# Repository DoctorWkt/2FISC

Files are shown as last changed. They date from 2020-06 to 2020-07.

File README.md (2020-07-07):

# FISC2: A TTL CPU with Some 16-bit Capabilities

FISC2 is a microseqenced CPU built from discrete TTL-level components.
It provides
 + recursive **F**unctions,
 + **I**ndexed addressing,
 + **S**tack operations, and
 + some instructions on 16-bit data values

as well as the usual load/store and arithmetic operations, comparisons,
branches and jumps.

The design uses 29 chips and has 8K of ROM, 336K of available RAM and a UART.



## Documentation

The overall design of the CPU is covered in
[Docs/arch_overview.md](Docs/arch_overview.md), and some details
of the hardware implementation are in 
[Docs/fisc2_implementation.md](Docs/fisc2_implementation.md).

## Implementation

At present, I have:

 + a Perl CPU simulator, [csim](csim)
 + an assembler, [cas](cas)
 + a simple compiler, [clc](clc)
 + example assembly and higher-level programs in [Examples](Examples)
 + a Verilog design in [Verilog](Verilog)
 + a final schematic in [Kicad/schematic.pdf](Kicad/schematic.pdf)

## Status of the CPU

**early-July, 2020**: Both the Perl simulator and the Verilog model work
well. I am happy with the design and I've ordered the PCBs and components.

For more detail on progress, you can read my [journal](Docs/journal.md).

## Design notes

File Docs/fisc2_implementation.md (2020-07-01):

# Implementation of the FISC CPU

This document outlines some of the implementation decisions for the FISC2
CPU. As with the CSCvon8 CPU, one of my goals was to keep the chip count
down. This time, recursive functions, local variables and indexed addressing
are important goals, as these allow me to port a C compiler to the CPU.

## Clock Phases

Before we tour the FISC2 implementation, I think it's important that I cover
how I'm using the two phases of the master clock signal in the implementation.
There is a square-wave master clock, called `Clk`, running at 3.57Mhz: in
the first half of each clock cycle the clock's value is high, and in the second
half the clock's value is low. And, of course, there is a falling edge between
the first and second halves.

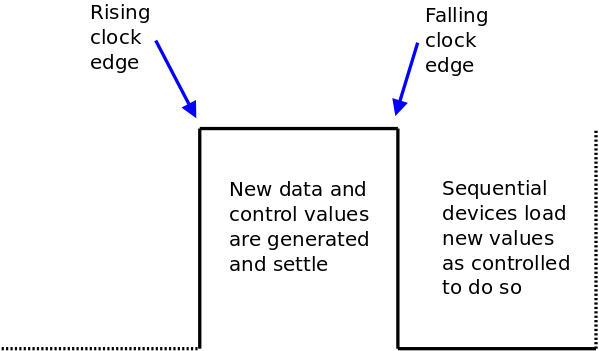
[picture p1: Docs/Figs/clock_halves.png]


In the first half of the clock cycle when the clock pulse is high, we propagate
new values from a (typically sequential) source of data through one or more
combinational devices, e.g the RAM or the ALU. The final result *must* settle before
the end of the first half. This also includes any level-based control values that
will be used in the second half.

The falling edge of the clock pulse is used to load the new data values from the
first half of the clock cycle into the sequential devices that need to load new
values. These devices need to be told to load their values, and so their control
lines (as noted) need to be set before the clock pulse falls. These devices know
to load when they see the clock edge. However, some of them need to see a
rising edge, so we also generate an inverted clock signal `Clkbar` for this reason.

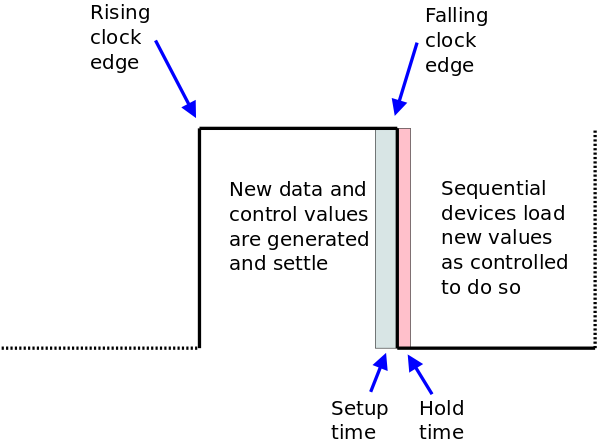
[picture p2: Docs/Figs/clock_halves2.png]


In fact, the values generated in the first half of the clock cycle need to settle
well before the clock transition. This is as most of the sequential devices which use
these values have both a *setup time* and a *hold time*. Each sequential device
has its own values for these two times.

The overall timing of the CPU (and hence its maximum clock speed) is limited
by the delay from when the clock edge rises and when the resulting control and data
values can settle before the start of the setup time. If we don't meet this
timing constraint, we will either load incorrect data or perform actions based
on incorrect control line values.

We can now start the tour of the FISC2 implementation, but bear in mind
which device control lines are level-based (generated in the first clock phase)
and which device control lines are edge-based (and triggered by the falling
clock transition).

*Aside: throughout the rest of the document, control lines which are active
low are indicated by a leading `~` tilde character.*

## The Program Counter

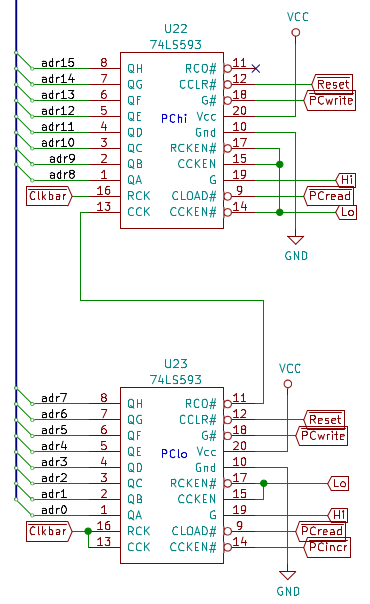
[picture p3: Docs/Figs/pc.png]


I chose to re-use the [74LS593](https://www.ti.com/lit/gpn/sn74ls593) as the
device for the PC. I'd previously used this in my CSCvon8 design; there it was
[my nemesis](https://minnie.tuhs.org/Blog/2019_04_26_Understanding_74LS593.html).
I think I understand it now.

The 74LS593 is an 8-bit register and incrementing counter with tri-state output.
The tri-state output is controlled by the level-based `~G` input, so we generate
this in the first clock half.

Loading and incrementing the register occur when `RCK` and `CCK` see a
rising edge. So, for the *PClo* component, they are both tied to `Clkbar`.

The register loads mid-cycle if `~CLOAD` is set low: both devices have this tied to
`~PCread`. The *PClo* component increments mid-cycle if `~CCKEN` is set low: this
is tied to `~PCincr`.

When *PClo* overflows from $FF to $00, the `~RCO` line generates a clock
transition. This is connected to *PChi*'s `CCK` so as to make *PChi* increment
as well.

I've tied both devices' `~CCLR` lines to the `~Reset` line to ensure that the PC
initialises to value $0000.

Note that the 74LS593's inputs are also its outputs. This is fine as the PC
only has to write to, and read from, the address bus. But because of this
I had to choose another device for the other address registers.

## The Stack Pointer



For the stack pointer, I had to find a TTL device which is:

 + an 8-bit register,
 + with tri-state output,
 + is also an up/down counter,
 + and can be cascaded to act as a 16-bit device.

Fortunately I found the
[74LS469](http://pdf.datasheetcatalog.com/datasheet/nationalsemiconductor/DS008333.PDF).
Unfortunately, this is now obsolete. I can
get them second-hand, but there are no new device and, sadly, no SOIC packages.
That's a shame as the 74LS469 is quite a nice device.

The 74LS469 has two level-based inputs, `~UD` and `~CBI`. When the `CLK` input
sees a rising edge, here is what happens:

  ~CBI |  ~UD  |  Result
------:|:-----:|--------
    0  |   0   | Decrement
    0  |   1   | Increment
    1  |   0   | Do nothing
    1  |   1   | Do nothing

As two of these four values have the same result, I was able to use one of these
patterns for a second purpose: to generate the `~PCincr` line. I'll explain soon.

`~UD` and `~CBI` are level-based, so I have to generate them in the first half of
the clock cycle. The 74LS469 expects a rising clock edge, so `Clkbar` is used
for this.

*SPlo* gets two control lines `~StkOp0` and `~StkOp1` which are tied to
`~UD` and `~CBI`, respectively. We only need to connect the `~StkOp0` (i.e
increment/decrement) line to *SPhi* because *SPlo* generates a carry/borrow
on the `~CBO` output. We can wire this to *SPhi*'s `~CBI` input to cascade
any increment or decrement.

As with the PC, the tri-state output is controlled by a level-based pin, `~OE`
which is tied to `~SPwrite` and generated in the first half of the clock cycle.

Now, I need to be able to set the Stack Pointer to any value, but typically
$0000 when the CPU initialises. Both *SPlo* and *SPhi*'s have `~LD` lines which
are tied to the control lines `~SPloread` and `~SPhiread`, respectively. When
low, they cause *SPlo* or *SPhi* to read from the data bus.

## The AR and DR Address Registers

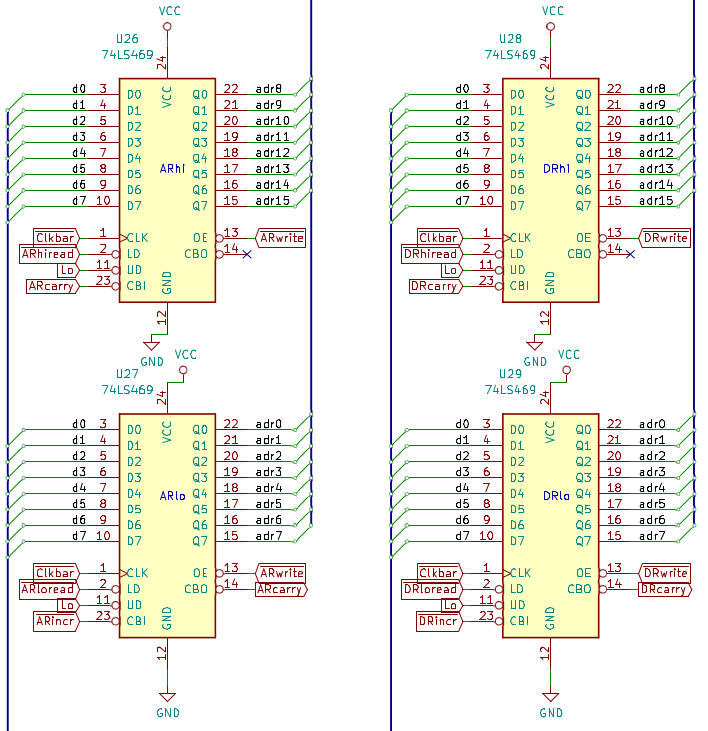
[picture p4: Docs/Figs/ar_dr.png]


I re-used the 74LS469 for the AR and DR registers as they need inputs separate
from their outputs, and they also need to increment.

As they only need to increment, not decrement, I can wire their `~UD` lines low.
They increment when the level-based `~ARincr` and `~DRincr` lines, respectively,
are low in the first half of the clock cycle. Otherwise, they are wired up
the same as the stack pointer devices.

## Memory Devices

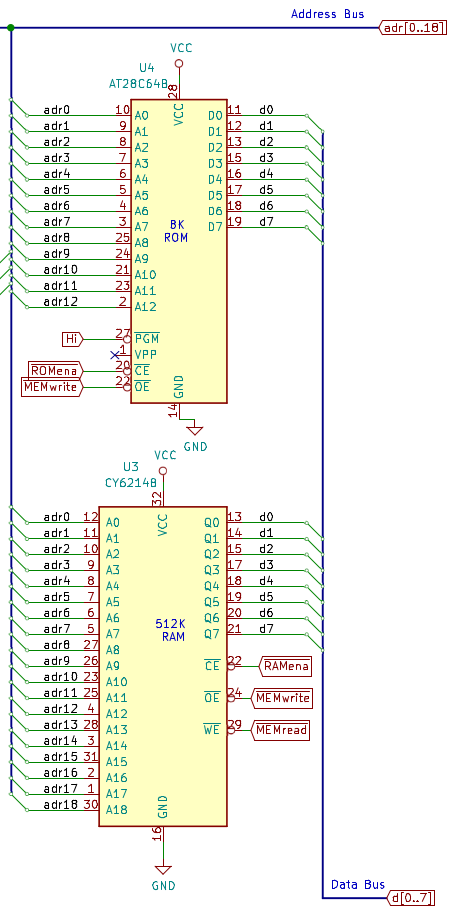
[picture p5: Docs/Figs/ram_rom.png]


The address registers in FISC2 are 16 bits wide, so technically there is only
a 64Kbyte address space. This is divided up into 8K of ROM starting at address
$0000, followed by 56K of RAM.

Both the
[AT28C64B EEPROM](http://ww1.microchip.com/downloads/en/DeviceDoc/doc0270.pdf)
and the [CY62148 static RAM](https://www.digchip.com/datasheets/parts/datasheet/115/CY62148-pdf.php)
read the address from the
address bus, select a memory location and write out to the 8-bit data bus.

Output on each device is enabled when both:

 + the `~CE` (chip enable) line is low, and
 + the `~OE` (output enable) line is low.

I've chosen to wire both `~OE` lines to `~MEMwrite` and treat both components
as a single "memory" device. There is a control line to the RAM, `~MEMread` wired
to `~WE`, which tells the RAM to read from the data bus and overwrite a memory
location.

## Selecting RAM and ROM, and Bank Switching

What I omitted to describe is how I control the `~CE` (chip enable) line on
both devices. I generate a single `~RAMena` line which is connected to the RAM's
`~CE` line. This is inverted and connected to the ROM's `~CE` line. Either
the RAM is enabled or the ROM, but never both. Now let's look at how
this `~RAMena` line is generated.

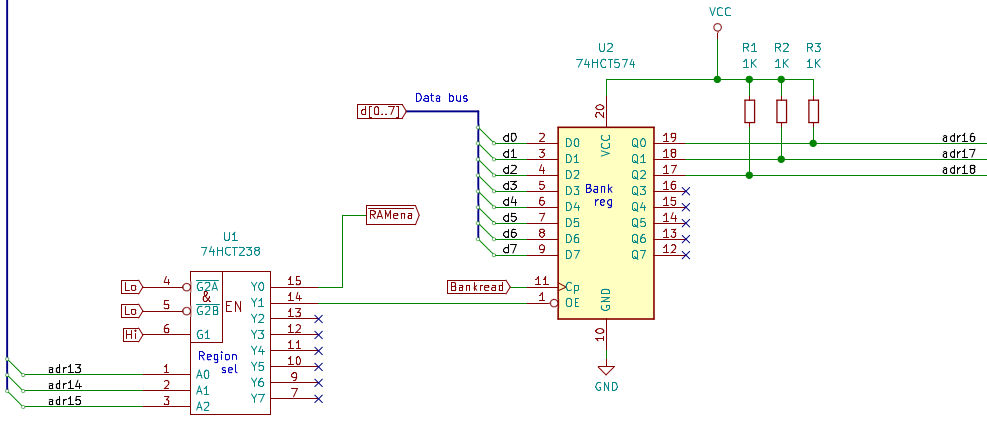
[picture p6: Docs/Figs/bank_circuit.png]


We want the bottom 8K of the address space to select the ROM and the rest of the
address space to select the RAM. To do this, I'm using the
[74HCT238](https://assets.nexperia.com/documents/data-sheet/74HC_HCT238.pdf)
3:8 demux on the left.

The 74HCT238 generates high outputs based on its input. The `A0` to `A2` inputs
are wired to the top three address bus lines, dividing the address space up into
eight 8K regions.

For the bottom 8K, `A0` to `A2` will be all low. This causes the `Y0` output
from the 74HCT238 to go high. As this is wired to the active-low `~RAMena` line,
this disables the RAM and enables the ROM. For all other memory regions, the RAM
is enabled.

Now we get to the bank switch. I wanted to have more than just 56K of available
RAM, and I had to work out how to map it into the 64K address space. Moreover,
I wanted to have a shared region of RAM which was always visible, so that I could
copy in and out of the currently non-visible parts of memory.

I've achieved this with a "bank switch" that generates extra address lines for the
CY62148 which is actually a 512K RAM device. Here is how it works.

I am using a
[74HCT574 8-bit register](https://assets.nexperia.com/documents/data-sheet/74HC_HCT574.pdf)
as a bank switch register; I'm only using
three of the bits that it can store. This register can load from the data bus
when the `Cp` clock input rises. I've wired this to `Bankread` which rises
mid-cycle once the data bus value has settled.

This allows eight "banks" of RAM to be mapped in to the address space, but only one
bank at a time is visible. As it stands, this means that the contents in each bank
can never be visible when a different bank is mapped in. I wanted to have a way
to copy data from one memory bank to another. And here is how this works.

Notice that the `Y1` output from the demux is wired to the `~OE` input on the
bank register. When the address bus has an address in the range $2000 to $3FFF,
this value is high. And as the `~OE` input is active low, this will cause the
output of the 74HCT574 to become high impedance ("high Z").

I've added three 1K pullup resistors to the three address outputs of the
bank register. When these are high impedance, the pullup resistors set their
values high.

The end result is that, when the address bus is in the range $2000 to $3FFF,
the highest of the eight RAM banks will always be selected, regardless of the
value in the bank register. Thus, there is a shared 8K of RAM in the
range $2000 to $3FFF no matter what RAM bank is selected.

# The Address Buffers

I needed the ability to manipulate and to store the values in the four
address registers (PC, SP, AR and DR) in RAM. To do this, I need to be able
to write their values on the data bus. However, the data bus is only 8 bits
wide and the address bus is 16 bits wide.

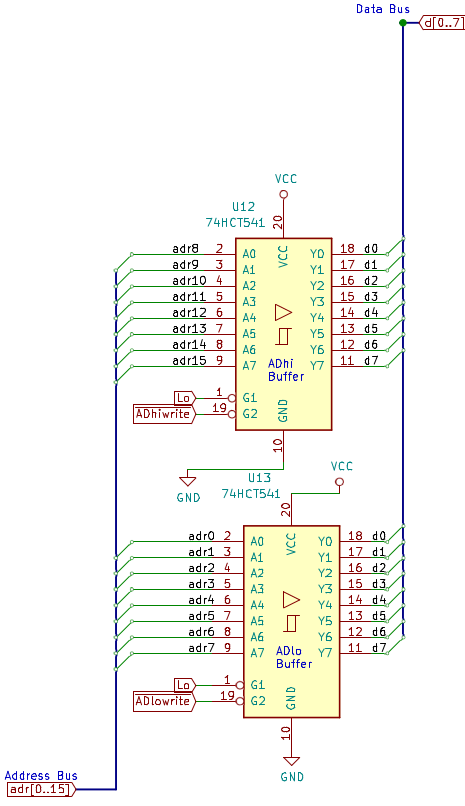
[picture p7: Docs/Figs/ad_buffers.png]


To do this, I'm using two
[74HCT151 tri-state buffers](https://assets.nexperia.com/documents/data-sheet/74HC_HCT151_Q100.pdf).
One is connected to the
low eight bits of the address bus; the other to the high eight bits. Both
output to the data bus.

The 74HCT151's output is controlled by two active-low lines, `~G1` and `~G2`.
I've set one line low on each buffer. The other is wired to `~ADlowrite` and
`~ADhiwrite`, respectively. I can set one of these in the first half of the
clock cycle. At the same time, I can get one of PC, SP, AR or DR to write a
value on the address bus. Now, half of the address bus value appears on the
data bus.

## The A and B Data Registers

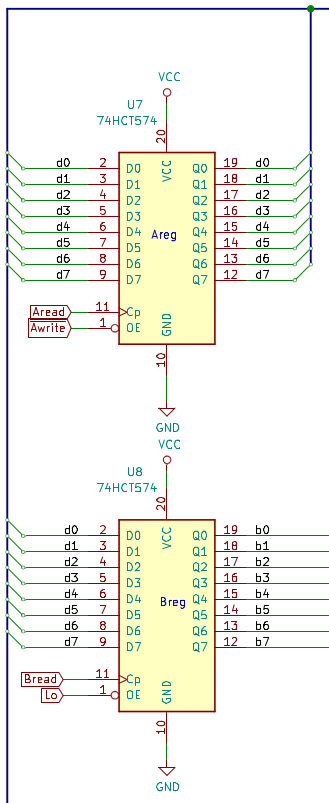
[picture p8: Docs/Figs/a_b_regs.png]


An ALU needs to operands to work on, but we can't transfer two things across
the data bus at the same time. Therefore, we need to store data in at least one
data register. I've put two data registers into FISC, the A and B register.

The A register simply reads from the data bus and writes back to the data bus.
This allows us to get data from memory and keep hold of it for several instructions
without having to fetch it again and again. I used a 74HCT574 8-bit register
for both A and B. Note that each have a rising edge control line, `Aread` and `Bread`
to read from the data bus mid-cycle.

The A register has an active low level-based control line, `~Awrite`, which
enables it to write to the data bus. We have a lot of data bus writers, and
we have to ensure that only one can write on the data bus at any time.

The B register's value goes directly into the ALU, so its output is always
enabled.

## The ALU

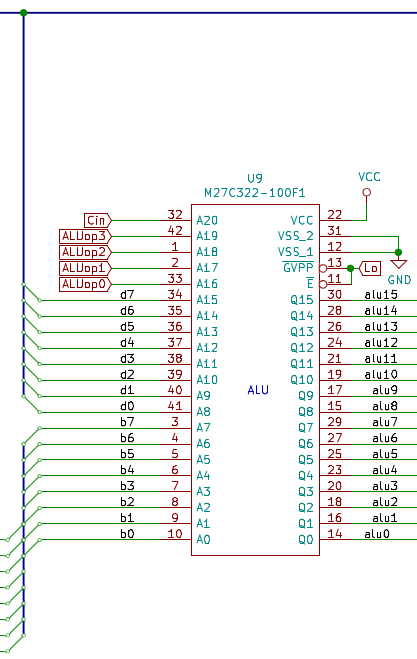
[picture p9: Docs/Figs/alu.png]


The ALU is simply a very big ROM, an
[M27C322 2MB x 16 ROM](https://www.digchip.com/datasheets/parts/datasheet/456/M27C322-pdf.php),
where the results of all operations are pre-computed and stored. I will cover what operations the
ALU performs elsewhere (and put in a link to this at some point).

As inputs, the ALU takes:

 + the 8-bit B value on address lines 0 to 7,
 + the 8-bit data bus value on address lines 8 to 15,
 + four bits indicating the ALU operation on address lines 16 to 19, and
 + a carry-in bit on address line 20.

As outputs, the ALU generates an 8-bit result on data lines 0 to 7, and
another eight bits. For some ALU operations, these encode a comparison result
(e.g. if one operand was bigger than another operand). For other ALU operations,
these bits encode part of the result. As an example of the latter, an 8-bit by
8-bit multiply produces a 16-bit result.

In terms of control, we don't need any control lines for the ALU. The ALU's
output is wired on with `~E` set low. `~GVPP` is wired low to stop the ROM
from being accidentally reprogrammed.

The datasheet for the MC27C322 lists its time from address change to data output
at up to 80nS, so this is one of the longer timing delays in the CPU. Another
is the AT27C1024-70 Decode ROM at 70nS. Together, they mean that the first half
of the clock cycle has to be at minimum 150nS. Then, if we have to fetch data from
the AT28C64B Instruction ROM, we can add another 150nS to that as well!

## The 16-bit Output Register

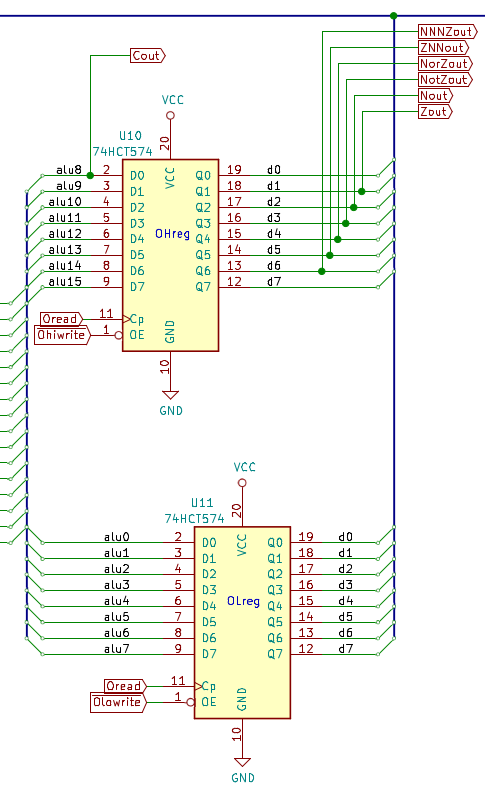
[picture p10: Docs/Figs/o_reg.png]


I use another two 74HCT574 8-bit registers to hold the output of the ALU.
A single rising edge load line, `Oread`, causes them to read the ALU output
mid-cycle when it is settled. Two level-based control lines, `~Ohiwrite`
and `~Olowrite`, tell the registers to write to the data bus. The implication
here is that it takes two clock cycles for the ALU to calculate a result
and for it to cross the data bus to be stored somewhere.

## The Carry

Notice on the previous image that there is a `Cout` signal tied to bit 8
of the ALU output. When we are doing addition or subtraction, this holds
the resulting carry or borrow. Yes, this is already stored in the high half of
the output register discussed above. The problem is that I need this
carry result to be fed back in to the ALU for subsequent additions or
subtractions. However, the output register's output is already connected
to the data bus.

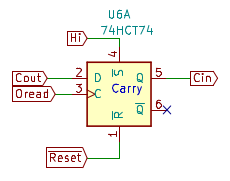
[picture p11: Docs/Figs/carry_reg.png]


Thus, we need a 1-bit register to hold the carry output. I've chosen to
use half of a
[74HCT74 D flip-flop](https://assets.nexperia.com/documents/data-sheet/74HC_HCT74.pdf).
I'm using the same rising edge load
line, `Oread`, that I was using for the output register to save a control
line. I've also wired the flip-flop's reset line to the system `~Reset`
line, even though this is not really neccessary.

## The Reset Line

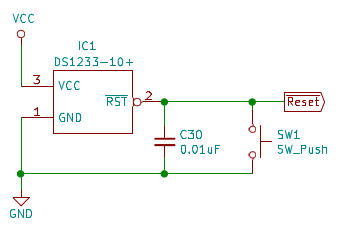
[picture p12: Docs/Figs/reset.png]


Given that I've just mentioned the `~Reset` line, let's see how we
generate it. I am using the
[DS1233 reset device](https://datasheets.maximintegrated.com/en/ds/DS1233.pdf)
for this. It holds the `~Reset` line low until the power supply stabilises,
then waits about 300mS, then raises the `~Reset` line.

The DS1233 device also provides for a manual reset button as
shown in the schematic. When pressed, this drops `~Reset` low,
and it comes up (glitch free) after about 300mS.

## The UART

Our final data device is the
[UM245R UART](https://www.ftdichip.com/Support/Documents/DataSheets/Modules/DS_UM245R.pdf).
This is an expensive device but I like it because it does several things:

 + provides a USB-visible UART for both Linux and Windows at a
   very high bit rate;
 + provides an 8-bit input and output register which is much easier to
   read/write than doing bit-banging;
 + the output is tri-state; and
 + it can also be used as the power supply for the whole CPU.

I am using all four features of the UM245R here. It is connected
to the data bus for both input and output. There are two falling-edge
control lines:

 + `~WR` (connected to `~UARTread`) reads one byte of data from the
   data bus and writes it to the UART; and
 + `~RD` (connected to `~UARTwrite`) reads one byte of data from the
  UART and writes it to the data bus.

When the UART is not writing to the data bus, its output is high Z.

Finally, there are two status lines from the UART:

 + `~RXF` (connected to `~RXready`) is low when the UART has a byte
   ready to place on the data bus; and
 + `~TXF` (connected to `~TXready`) is low when the UART is read to
   read from the data bus and send data down the UART.

## The Control Logic

We have now covered all of the address and data components in the FISC2
implementation. Along the way, I've covered most of the control lines
for these devices. Now we need to turn our attention to how these lines
are generated.

Also, remember that the level-based control lines need to be generated
in the first half of the clock cycle. The edge-based control lines will
either be generated from `Clk` if they need to be falling edges, or
from `Clkbar` if they need to be rising edges.

I did a quick count of the control lines before and I came up with about
thirty-six lines (including some which are groups of lines like the ALU
operation). Somehow, all of these lines have to be asserted or disabled
on each microinstruction. Fortunately, many of the lines can be grouped
together as they are mutually exclusive (e.g. the data bus writers).

## The Instruction Register and Microsequencer

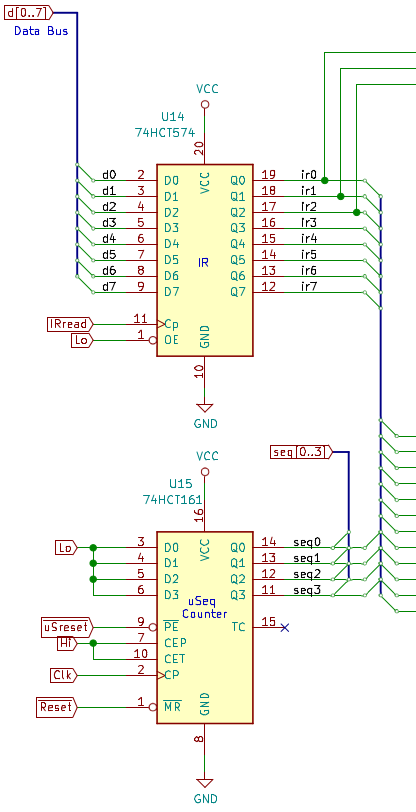
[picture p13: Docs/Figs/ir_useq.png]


The instruction register, a 74HCT574 register, loads an 8-bit opcode
value at the beginning of each instruction. I'll explain how in a minute.

As each high-level instruction is composed of a sequence of microinstructions,
I use a
[74HCT161 counter](https://www.ti.com/lit/ds/symlink/cd54hc163.pdf)
to produce a increasing 4-bit pattern to index
each microinstruction in the high-level instruction in turn.

The `CEP` and `CET` inputs are tied high to hard-wire the device to always
increment. However, we do need to be able to reset the counter back to zero
at the end of each instruction, and also when we reset the CPU. Luckily,
the 74HCT161 has two control lines which we can use to do both.

The `~PE` edge-based line tells the counter to load a value from the
four `D` input lines when this line falls. I've tied all the `D` lines low.
`~PE` is then tied to the `~uSreset` control line, so when it drops, the
counter is reset.

For the main CPU reset, I've tied the 74HCT161 `~MR` (master reset)
level-based line to the system `~Reset` line. When this is low, the
counter remains at zero.

## The Decode ROM

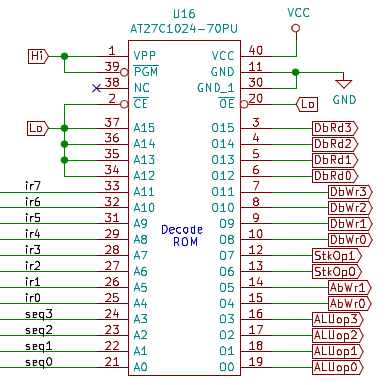
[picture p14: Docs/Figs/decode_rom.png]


The 8 bits from the instruction register and the 4 bits from the microsequence
counter form the address to look up a microinstruction in the
[AT27C1024 Decode ROM](http://ww1.microchip.com/downloads/en/devicedoc/doc0019.pdf).
This ROM has 16 bits of output which we need to
expand to produce the 36 control lines I mentioned before.

The AT27C1024 has more than 12 bits of address inputs, so I've tied the
unused ones to zero. It does mean if I need more instructions, or more
microinstructions in each instruction, I've got the ability to implement this!

The `~PGM` line is tied high so that the ROM is not accidentally programmed.
The `~CE` and `~OE` lines are tied low so that the ROM's output is always
enabled.

I mentioned before that the instruction register loads an opcode from the data
bus on the first microinstruction in each insttruction. I make this happen
by programming the Decode ROM so that the first microinstruction in *every*
instruction asserts these control lines:

```
  MEMwrite IRread PCincr     # Read from memory, write to IR, increment PC
```

## Groups of Decode ROM Outputs

If you look at the above diagram, you can see that the Decode ROM's output
can be broken up into five groups:

 + 4 bits identifying the ALU operation;
 + 2 bits identifying the address bus writer;
 + 2 bits for the stack pointer operation;
 + 4 bits identifying the data bus writer; and
 + 4 bits identifying the data bus reader.

As I mentioned earlier, some patterns in each group are spare, and I
repurpose then for other uses which I will explain below.

## The Address Bus Writer Demux

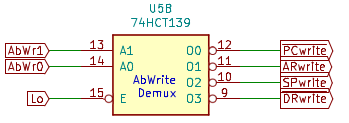
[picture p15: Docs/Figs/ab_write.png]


I've covered the available ALU operations elsewhere, so let's move to the
address bus writer demux. The two address bus writer bits from the Decode
ROM come to this half of a
[74HCT139 2:4 demux](https://assets.nexperia.com/documents/data-sheet/74HC_HCT139.pdf).
These control lines need to
be generated in the first half of the clock cycle, so I have wired the
`~E` enable line of the 74HCT139 low so that the output is always on.
You can see the four active-low control lines that this demux generates on
the right.

## The Stack Operation and `~PCincr`

The stack pointer needs two bits to control its increment and decrement
operation, and these come directly out of the Decode ROM. But two of the
four patterns have the same effect on the stack pointer, and I have a spare
74HCT139 half, so here is what I do:

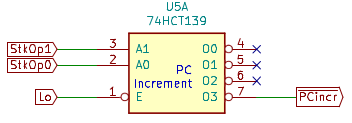
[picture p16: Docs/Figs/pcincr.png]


The fourth stack operation pattern is demuxed to become the active low
`~PCincr` control line. I won't be inc/decrementing the stack at the
same time as I increment the PC, so this is fine. As with the other
74HCT139 half, the `~E` enable line is wired low to generate `~PCincr`
in the first half of the clock cycle.

## The Data Bus Writer Demux

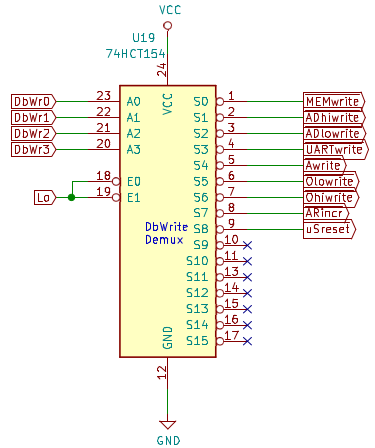
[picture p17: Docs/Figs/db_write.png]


We need to choose a device to write to the data bus in the first half
of the clock cycle. The four data bus writer bits from the Decode ROM
are demux'd with a
[74HCT154 4:16 demultiplexer](https://assets.nexperia.com/documents/data-sheet/74HC_HCT154.pdf).
Again, the `~E0` and `~E1` enable lines are wired low so that the output is always on.

The first seven outputs are actual data bus writer control lines.
That leaves nine outputs unused, so I have repurposed two of them
to be the `~ARincr` and the `~uSreset` lines. I didn't put `~DRincr`
here because I wanted to be able to increment the AR and DR address
registers separately.

## The First Data Bus Reader Demux

We have a problem with demuxing the data bus reader lines from the
Decode ROM. Some of the data bus readers need a level-based control
line to be generated before the mid-cycle clock transition. Others
need an rising edge mid-cycle to read the bus. And yet others need
a falling edge mid-cycle to read the bus! This is how I solve this
problem.

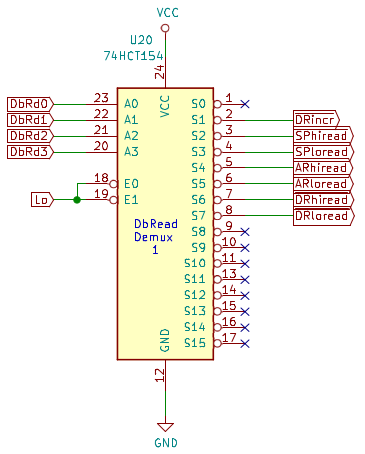
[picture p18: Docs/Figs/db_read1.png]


The first data bus reader demux deals with those lines that are
level-based. I'm using another 74HCT154 4:16 demultiplexer. Again,
the `~E0` and `~E1` enable lines are wired low so that the output
is always on.

Only the `~XXread` lines are actual data bus reader control lines.
I've borrowed one output to be the `~DRincr` control line.

Also note, in particular, two things. First, output zero is not used:
we need the ability to *not* read from the data bus, e.g. when we are
doing a NOP instruction. Second, only the first half of the sixteen
possible input patterns are decoded. Now, why would this be?

## The Second Data Bus Reader Demux

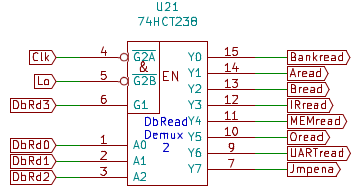
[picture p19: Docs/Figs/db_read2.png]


We don't decode the second half of the sixteen possible input patterns
because they are decoded by this demux! I'm using another 74HCT238 3:8
demux here, and I've done some subtle cleverness along the way.

Remember that the 74HCT238 produces a high output on the line which
is selected by the input pattern. The 74HCT238 also has three output
enable lines: `G1`, `~G2A` and `~G2B`. These have to be high, low and
low (respectively) for one output line to be high. Otherwise, all
eight outputs are held low.

Here is the cleverness. This demux needs to generate the rising
edge lines to control those data bus readers that need them. `~G2B`
is already low, so now we need to deal with `G1` and `~G2A`.

`G1` is tied to the highest of the four data bus reader bits from
the Decode ROM. This means the demux output can only go high when
the input is a pattern from the *second half* of the possible
data bus reader patterns. Clever, huh?!

`~G2A` is now tied to the master `Clk` signal. Now, the output
can only go high when the `Clk` signal falls, and this occurs
mid-cycle. We now have one output which only goes high when selected
and is a rising edge mid-cycle: just what we wanted.

## The Inverter

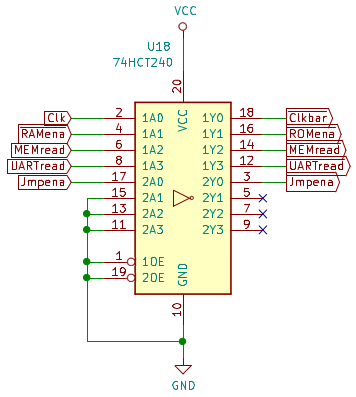
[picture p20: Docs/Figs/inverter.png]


These is just one niggling unsolved issue with the second data bus
reader demux. Some of the edge-based control lines we need are
falling edge, but the 74HCT238 only generates rising edges. To
solve this, I have a
[74HCT240 octal inverter](https://assets.nexperia.com/documents/data-sheet/74HC_HCT240.pdf)
to change the direction of the
edges. This is also used to change the level of some other control
lines.

## The Jump Logic

One thing that I've left to last in this tour of the FISC2
implementation is how the CPU performs jumps. Here are the
reasons that the FISC2 CPU can jump:

 + when the first ALU operand (I'll call "A") is equal to
   the second ALU operand (I'll call "B");
 + when A is not equal to B;
 + when A is greater than B;
 + when A is greater than or equal to B;
 + when A is less than B;
 + when A is less than or equal to B;
 + when the UART is not ready to transmit data;
 + when the UART has no data to be read; and
 + unconditionally (i.e. a normal JMP).

Firstly, this is nine jump reasons, i.e. one more that I can encode
in three bits. Secondly, there isn't any spare output bits from
the Decode ROM, so I have to think of a way to generate a bit
pattern for each of the above jump reasons that can be easily
decoded. Here is what I chose.

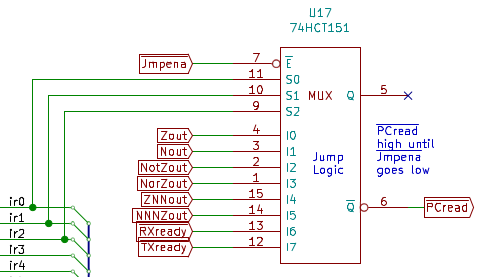
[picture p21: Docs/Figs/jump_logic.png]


I've wired three of the instruction register's output bits
directly to the jump logic. This gives me eight bit patterns
to represent the different jumps. It also means that *any*
instruction can cause a jump if the `~Jmpena` line is
enabled.

For the ALU-based jumps, there is a special ALU operation `A-Bcomp`
which subtracts the "B" operand from the "A" operand and stores
these result flags in the output register if the comparison is:

 + Zero
 + Not Zero
 + Negative
 + Negative or Zero
 + Not Negative, Not Zero
 + Zero or Not Negative

I chose these flags results because:

 + `A == B`, when `A - B` is zero
 + `A != B`, when `A - B` is not zero
 + `A < B`,  when `A - B` is negative
 + `A <= B`, when `A - B` is negative or zero
 + `A > B`,  when `A - B` is not negative, not zero
 + `A >= B`, when `A - B` is zero or not negative

So these six flags become six of the inputs to the jump logic,
which is a
[74HCT151 8:1 multiplexer.](https://assets.nexperia.com/documents/data-sheet/74HC_HCT151_Q100.pdf)
Two other inputs to this device are the two UART status lines, `~RXready` and `~TXready`.

When the `~Jmpena` control line goes low, and when one of the
eight possible jump inputs is high, the `~Q` output goes
low and sets `~PCread` low. This causes the PC to load a new
value, thus "jumping" the PC to a new location.

Which jump input is chosen depends on the three bits from
the instruction opcode. This forces the opcode to represent
certain jump types. For example, an opcode of $X0 or $X8
(when the three IR bits are all zero) can only do an `A == B`
conditional jump. Similarly, an opcode of $X1 or $X9 can only
do an `A != B` conditional jump.

There is one jump which I haven't discussed yet, and that's
the unconditional jump. To make this happen, I use that
ALU operation that always generates a zero output; this also
always sets the Zero flag. Therefore, the microcode sequence
to jump to address $XXXX is:

```
Opcode $48:
  MEMwrite IRread PCincr     # Read from memory, write to IR, increment PC
  MEMwrite ARloread PCincr   # Read the low/high address into the AR
  MEMwrite ARhiread PCincr
  Zero Oread	             # Set the Zero flag in the output register
  Ohiwrite ARwrite Jmpena    # Put AR on address bus, jump as Zero set
  uSreset		     # Reset the microsequencer back to zero
```

## Summary

That ends the tour of the RISC2 implementation. I think (hope)
that I've covered all the devices and, in particular, I hope
I have covered how I've organised all the control lines in order
to make them all work.

If something doesn't make sense, or if you would like something
to be clarified, please let me know.

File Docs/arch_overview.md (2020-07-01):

# FISC2: An 8-bit TTL CPU with Some 16-bit Instructions

FISC2 is a microseqenced CPU built from discrete TTL-level components.
It provides
 + recursive **F**unctions,
 + **I**ndexed addressing,
 + **S**tack operations, and
 + some instructions on 16-bit data values

as well as the usual load/store and arithmetic operations, comparisons,
branches and jumps.

## High-level Overview

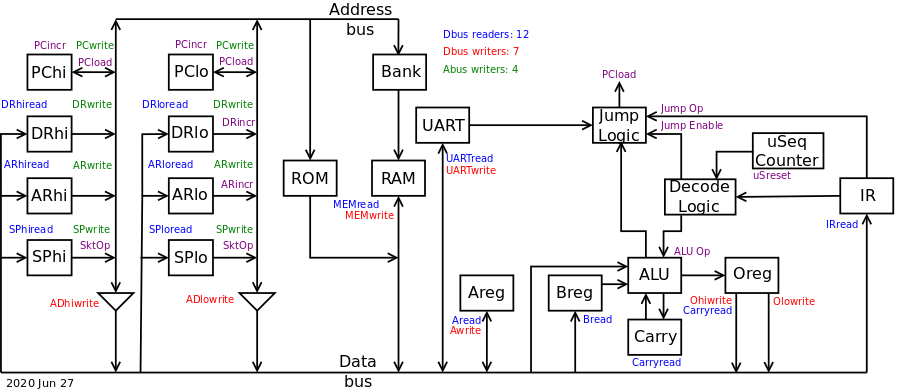
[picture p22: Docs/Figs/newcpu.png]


The above image shows a high level view of the architecture. On the left are the
components that write addresses to the address bus. In the middle is the ROM
and RAM which writes to the data bus. At the bottom right are the two 8-bit data
registers, A and B and the ALU. Finally, at the top-right is the control logic
for the CPU.

Four components can place an address on the address bus, and their control lines
are named in green.

Seven components can write data on the address bus, and their control lines
are named in red.

Twelve components can read from the data bus, and their control lines are named in
blue.

Finally, the purple control lines are for other actions such as incrementing
registers.

## The Address Bus and Registers

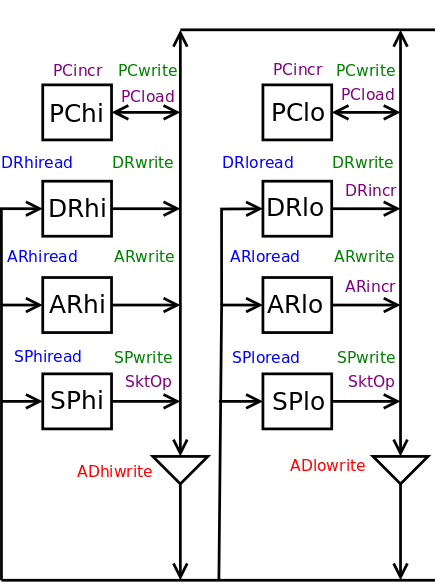
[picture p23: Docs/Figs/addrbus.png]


There are four 16-bit registers which can write to the 16-bit address bus:
 1. The Program Counter (PC)
 2. The Address Register (AR)
 3. The Destination Address Register (DR)
 3. The Stack Pointer (SP)

All three are divided into 8-bit high and low registers. This allows
the Address Register, Destination Register and Stack pointer halves to
write to and read from the 8-bit data bus through the buffers shown as
triangles. The PC can only load from the address bus.

The PC provides the address of the next instruction in memory. It can load
a new value (i.e. jump), increment to the next address or hold its value.

The AR provides the address for data items in memory; this is typically
used as the *source* of CPU data. It can load a new value, hold its value,
or increment its value.

The DR also provides the address for data items in memory; this is
typically used as the *destination* of CPU data. It can load a new value,
hold its value, or increment its value.

The SP points at a location in memory where data can be pushed or popped.
It can load a new value, increment, decrement or hold its value.

## Memory

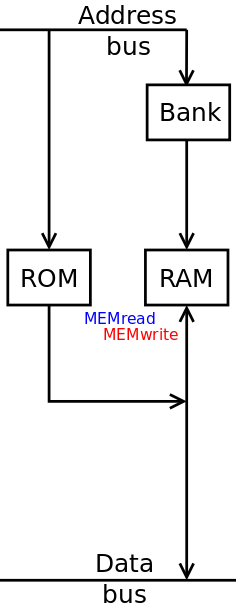
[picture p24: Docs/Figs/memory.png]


FISC2 has a 16-bit address bus, so only 64K bytes can be accessed by
the CPU at any time. The ROM is mapped to the bottom 8K of the address
space. The RAM device is 512K bytes in size. The Bank register adds and
extra three address bits to the address bus and allows the CPU to "see"
eight banks of RAM above the mapped ROM.

However, for the 8K of memory immediately above the ROM, this is always
mapped to the same memory bank. This provides a shared buffer which is
always visible regardless of the value in the Bank register.

The memory map for FISC is thus:



Based on the address on the address bus and the selected bank, either the ROM
or the RAM access a location in memory. If the `MEMwrite` control line is
enabled, this value is written on the data bus.

## The Data Bus



The data bus is 8 bits wide and provides the path for data movement. This includes:

 + data to and from the address registers,
 + data to and from the memory devices,
 + data to and from the UART (not shown),
 + data to the A and B data registers, and from the A register,
 + data to the instruction register (IR), and
 + data from the O register which holds the ALU's output.

## The ALU



The ALU provides 16 operations on two data inputs, of which one is always
the B register. The other data input is the data bus itself. This allows
the ALU input to be one of:

 + the 8-bit halves of the PC, AR, DR and SP registers,
 + the A register,
 + a memory location,
 + the UART, or
 + the output of a previous ALU operation (via the two halves of the 16-bit
   O register).

The ALU's data output is buffered by the 16-bit O register. For most ALU
operations, only the low half of the O register is used. The top half
is used to hold results for multiplication, division and shifts. The
16-bit O register thus allows the CPU to perform ALU operations on two
8-bit values where there is a 16-bit result.

The Carry register records the carry of an ALU addition or subtraction
of an ALU operation. This information can then be used by following
additions and subtractions. 

When performing a comparison between two operands, the ALU stores
information about the comparison in the top half of the O register. This
can then be used for conditional jump and branch instructions.

## Indexed Addressing

As the AR and SP registers can write to and read from the data bus,
we can use the ALU along with the Address Register (AR) to perform indexed
addressing. Consider the load operation `A= <address>,B`, where the base address
is indexed by the B register's value. Also assume that AR and B are already loaded
with the address and index. This sequence of microinstructions will perform the
indexed load:

```
  Oreg = ARlo + B, carry recorded in Carry register
  ARlo = Oreg
  Oreg = ARhi + 0, previous carry brought in
  ARhi = Oreg
  A = Memory[ AR ]
```

## Stack Operations

At boot time, the 16-bit Stack Pointer is initialised to $0000 so
that the first push on the stack will occur at $FFFF, i.e.
the top of memory. The Stack Pointer can increment and decrement itself without
requiring the ALU. Let's look at how we can push the A register on the stack.
This would be performed by this sequence of microinstructions:

```
  SP--
  Memory[ SP ] = A
```

Similarly, popping a value from the stack and into the A register
would be performed by this sequence of microinstructions:

```
  A= Memory[ SP ]
  SP++
```

The Stack Pointer is connected to the data bus in the same way as the
Address Register, and the Stack Pointer can be loaded from the data bus.
This allows functions to have local variables and arguments. Consider
a function with two 8-bit arguments (`arg1` and `arg2`) and three 8-bit
local variables (`loc1`, `loc2` and `loc3`). We can arrange the stack
to look like this:

```
        | arg2 |   SP,3
        +------+
        | arg1 |   SP,2
        +------+
        |  Old |
        +      +
  SP -> | PC+1 |
        +------+
        | loc3 |   SP,-1
        +------+
        | loc2 |   SP,-2
        +------+
        | loc1 |   SP,-3
        +------+
```

The five variables can be accessed using indexed addressing with the Stack
Pointer as the base, as shown in the right-hand column above.

## Function Calls

FISC provides function calls where the return address is stored on the
stack. There are two instructions: JSR to jump to a subroutine and RTS
to return from the subroutine.

Given that the Program Counter will increment itself as part of each
instruction, the sequence of microinstructions for JSR is:

```
  SP--
  Memory[ SP ] = PChi
  SP--
  Memory[ SP ] = PClo
```

and the sequence of microinstructions for RTS is:

```
  PClo = Memory[ SP ]
  SP++
  PChi = Memory[ SP ]
  SP++
```

## Control Logic



The control logic block diagram for FISC2 is shown in the above image.
Each instruction is one byte, followed by zero or more bytes that
encode addresses, constant values, offsets etc.

FISC2 is a microsequenced CPU with up to sixteen microinstructions per
high-level instruction. The microsequence counter starts at zero and
counts up to fifteen, but it can be reset to zero by the Decode Logic.

On microinstruction zero, the Instruction Register is loaded from memory
over the data bus:

```
  IR = Memory[ PC++ ]
```

The Instruction Register and the microsequence counter form a lookup
address to choose the next microinstruction in the Decode Logic.

Four bits from the Decode Logic are sent to the ALU as the
operation to perform. Thus, on every microinstruction the ALU makes a calculation.
However, the Decode Logic also control when the O register stores this result
and the the Carry buffer stores any carry result.
This allows us to selectively use the ALU as required.

When doing a comparison, the ALU generates six bits which are sent to the
Jump Logic:

 + Zero
 + Not Zero
 + Negative
 + Negative or Zero
 + Not Negative, Not Zero
 + Zero or Not Negative

The ALU compares two operands by subtracting the second operand from the
first. The above outputs can be used to make these decisions:

 + `operand1 == operand2`, when `operand1 - operand2` is zero
 + `operand1 != operand2`, when `operand1 - operand2` is not zero
 + `operand1 < operand2`, when `operand1 - operand2` is negative
 + `operand1 <= operand2`, when `operand1 - operand2` is negative or zero
 + `operand1 > operand2`, when `operand1 - operand2` is not negative, not zero
 + `operand1 >= operand2`, when `operand1 - operand2` is zero or not negative

As with the ALU, the Decode Logic controls when the Jump Logic output
actually modifies the Program Counter's value. So even though the Jump
Logic is always evaluating the comparison bits from the ALU, we
won't jump unless the Decode Logic tells us to.

### The Decode Logic

The Decode Logic outputs sixteen control bits. Some of these are demultiplexed
to provide many more control bits. The Jump operation is provided directly by
the low three bits of the instruction.

At present, these are the control groups provided by the Decode Logic:

 + The ALU operation: 4 bits, 3:0
 + The address bus writers: 2 bits, 5:4
 + The stack operation: 2 bits, 7:6
 + The data bus writers: 4 bits, 11:8
 + The data bus readers: 4 bits, 15:12

There are less than sixteen components that read from the data bus; similarly,
there are less than sixteen components that write to the data bus.
So, some of the bit patterns for these two control groups are used to generate
other control lines, such as:

 + incrementing the AR and DR registers
 + asking the Jump Logic to change the PC if required
 + resetting the microsequencer at the end of a series of microinstructions

As there are less than four stack operations, one of the four stack operation
patterns controls when the PC increments.

## Operations on 16-bit Data Values

Given that FISC2 has an 8-bit data bus, it is sensible that we treat FISC2 as
an 8-bit CPU. But what makes FISC2 interesting is that both the AR and DR address
registers can increment. This provides scope to write instructions that perform
operations on 16-bit data values.

Here is an example 8-bit data operation and a possible sequence of microinstructions
for it:

```
# Add the 8-bit value from the source memory address to the value
# at the destination memory address, and store the result back in
# the destination memory address. Assume that the destination address is first.

    DRlo= Mem[ PC++ ]		# Get the destination and source addresses
    DRhi= Mem[ PC++ ]
    ARlo= Mem[ PC++ ]
    ARhi= Mem[ PC++ ]
    Clear the carry
    B= Mem[ AR ]		# Get one operand into the B register
    O= Mem[ DR ] + B		# Perform the ALU operation
    Mem[ DR ]= O		# Store the result back to memory
```

Now let's look at how we can extend this to do an operation on two 16-bit
data items in memory:

```
# Add the 16-bit value stored in little-endian format from the source memory address
# to the 16-bit value at the destination memory address, and store the result back in
# the destination memory address. Assume that the destination address is first.

    DRlo= Mem[ PC++ ]		# Get the destination and source addresses
    DRhi= Mem[ PC++ ]
    ARlo= Mem[ PC++ ]
    ARhi= Mem[ PC++ ]
    Clear the carry
    B= Mem[ AR ]		# Get one operand into the B register
    O= Mem[ DR ] + B		# Perform the ALU operation
    Mem[ DR ]= O		# Store the result back to memory
    AR++			# Move AR and DR to point to the high
    DR++			# byte of the data
    B= Mem[ AR ]		# Get high byte of operand into the B register
    O= Mem[ DR ] + B		# Perform the ALU operation using the stored carry
    Mem[ DR ]= O		# and store the result back to memory
```

This is a long microsequence. However, compared to two 8-bit instructions performed
sequentially:

 + the total number of microinstructions performed is slightly less
   as we don't have to load the IR twice or reset the microsequencer twice;
 + the total instruction size in memory is smaller as we don't have to
   store the destination and source addresses twice; and
 + we now have a 16-bit instruction which makes writing assembly code (and
   porting a compiler) much easier.

Not all 8-bit instructions can be rewritten to have a 16-bit equivalent. For example,
the ALU can do an 8-bit multiplication in one microinstruction. However, it cannot
do a 16-bit multiplication. To do this, we will need to perform four 8-bit
multiplication and then add the subsequent results. This will definitely *not*
fit into the sixteen microinstructions available in a single instruction.

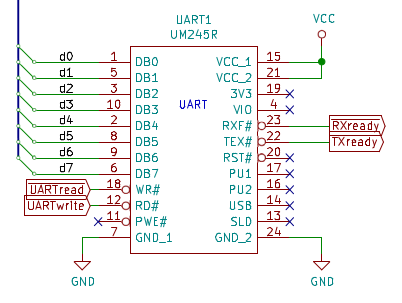
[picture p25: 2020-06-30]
Docs/Figs/uart.png

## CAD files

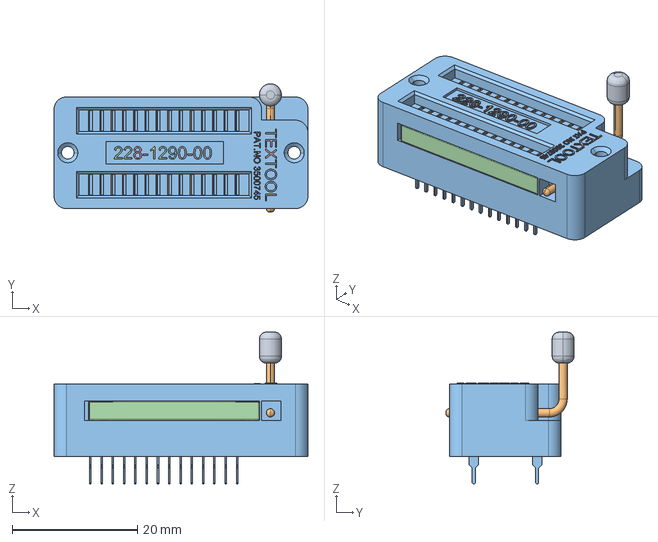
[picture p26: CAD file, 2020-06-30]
Kicad/lib_sch/textool.stp
40.5 x 20.5 x 24.2 mm

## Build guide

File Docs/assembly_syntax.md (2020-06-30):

# FISC2 Assembly Syntax

## Literals

Decimal literals are written as per normal and can be signed, e.g. 23, 45, -67,
-2005 etc.

Hexadecimal literals are written with a leading '$' followed any number of
hex digits. A minus sign is not permitted.

Character literals are written as a single character surrounded by single
quotes. These escaped character literals are recognised: '\n', '\t\, '\r'.

## Symbol Names

Symbol names are composed from the the characters A-Z, a-z, 0-9, the underscore
and the decimal point. Symbol names cannot start with a leading digit.

## Pseudo-Operations

```
  .text
  .data
```

The following code or data is stored in either the text section or the
code section of the output.

```
  .globl <symbol>
```

The given symbol is a global symbol.

```
  .byte <constant>
  .word <constant>
  .long <constant>
```

The given 8-, 16- or 32-bit constant is stored in little-endian format.
There is no word or long alignment.

## Labels

Labels must occur at the start of a line. They must be a symbol followed
immediately by a colon. Labels can appear on a line by themselves.

## Registers

There are eight 32-bit registers, R0 to R7, and they occupy the memory
locations $FFD0 to $FFFF. You cannot create symbols with the same names
as these eight registers.

Depending on the instruction, only the low 8-bits or 16-bits of a register
may be used.

## Index Syntax

You can access an indexed memory location using one of the following
syntaxes:

```
    symbol[Rx]		# Symbol address plus 16-bit register Rx
    symbol[const]	# Symbol address plus 16-bit constant
    symbol1[symbol2]	# Symbol address plus 16-bit value at symbol2
```

All of these denote a 16-bit address.

## Instructions

Most instructions end with a letter to signify the size of the data
and registers that they operate on: 'b' for 8-bit bytes and 'w' for
16-bit words.

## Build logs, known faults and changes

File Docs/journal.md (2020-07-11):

# Warren's Working Journal for the FISC2 CPU

This is my working journal for the FISC2 CPU. It will (hopefully) go
from when I first conceived of the design on paper through to soldering the
components on a PCB and running real instructions, and beyond. I didn't write
it for public consumption; the journal helps me keep track of what I'm doing,
what issues I still need to address etc.

FISC2 is a continuation of the FISC CPU, so you may want to read my
FISC journal
if you are going to read this one.

Anyway, read on for weeks of frustration and occasional success ...

## Sun 24 May 22:20:03 AEST 2020

I've forked my FISC code over to here so I can work on FISC2 in parallel.
This is because I want to explore the idea of a second address register
which will allow me to write "16-bit" instructions.

Imagine that there was a second pair
of address registers, DRhi/DRlo as well as the existing ARhi/ARlo.
Imagine that they could *increment* as well as load (like the PC).

Given the above, we could write these instructions:

### addw $DDDD, $SSSS

Add a 16-bit value from memory location `$SSSS` to memory location
`$DDDD`. Microcode:

  0. Load IR
  1. Load ARlo, clear carry
  2. Load ARhi
  3. Load B from Mem [AR]
  4. Load DRlo
  5. Load DRhi
  6. Oreg= Mem[DR]+B, save carry
  7. Mem[DR]= Oreg, increment AR
  8. Load B from Mem [AR], increment DR
  9. Oreg= Mem[DR]+B (with saved carry)
 10. Mem[DR]= Oreg, reset uSeq counter

The instruction would be 5 bytes long and take 11 microinstructions.
If we had to use byte instructions, we'd have to do:

```
   mov b, $SSSS
   add $DDDD, b		# Zeroes the carry in microcode
   mov b, $SSSS+1
   adc $DDDD+, b	# Add with carry
```

That's 12 bytes long and `5+6+5+6=22` microinstructions: significantly
longer in time and space. Hmm. I'm liking this. We would have to
replace the two 74HCT574 SOIC AR chips with four 74LS593 DIP chips.
More space on the PCB will be required.
Digikey sells SN74LS593DWR SOIC-20 for $20 each. Element 14 doesn't
sell them. Mouser (X-On) in quantities of 4,000+ only.

What this would mean is that the design would have both 8-bit and
16-bit instructions. Maybe I should completely hide the A and B
registers?

We have enough spare decode outputs to make this work, I think. I'd
have to sit down and make sure it was possible.

## Mon 25 May 10:31:02 AEST 2020

We need another address bus writer, that's easy:
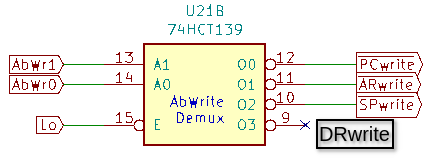
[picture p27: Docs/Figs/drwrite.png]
 

We need another two data bus readers, that's also easy. But I need a control
line which will increment all *four* AR and DR chips at the same time. I'm
thinking of something like this:

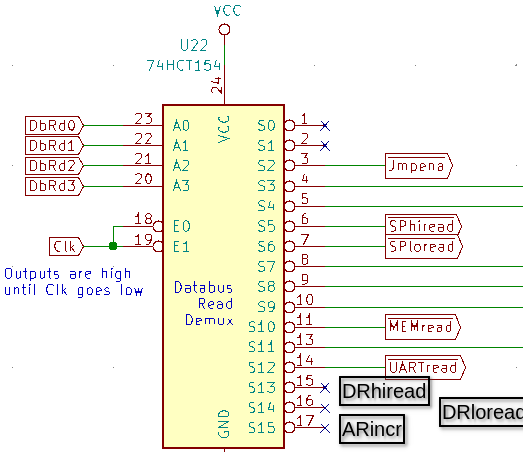
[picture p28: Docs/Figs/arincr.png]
 

I'm borrowing a spare data bus reader control line to use as the increment
line. Let's see if I can write the microcode for `addw $DDDD, $SSSS`:

```
# Address bus writers (2 bits, 8:7)
PCwrite = 0000
ARwrite = 0080
SPwrite = 0100
DRwrite = 0180

# Data bus readers (4 bits, 12:9)
#           0000 means no data bus reader
#           Several values are unused
Jmpena    = 0400
ARhiread  = 0600
ARloread  = 0800
SPhiread  = 0A00
SPloread  = 0C00
Aread     = 0E00
Bread     = 1000
IRread    = 1200
MEMread   = 1400
Carryread = 1600
UARTread  = 1800
DRhiread  = 1A00
DRloread  = 1C00
ARincr    = 1E00

# Add 16-bit word from source to destination (accumulator)
XX movw_word_word:				    # uInst 0 same as before
     MEMwrite ARloread PCincr			    # Get src address into AR
     MEMwrite ARhiread PCincr
     MEMwrite DRloread PCincr			    # Get dest address into DR
     MEMwrite DRhiread PCincr
     ARwrite MEMwrite Bread Stkhold Zero Carryread  # B= Mem[ AR ], zero carry
     DRwrite MEMwrite A+B Carryread Stkhold	    # O= Mem[ DR ] + B
     DRwrite Owrite MEMread Stkhold		    # Mem[ DR ] = O
     ARincr					    # Increment AR and DR
     ARwrite MEMwrite Bread Stkhold 		    # B= Mem[ AR+1 ]
     DRwrite MEMwrite A+B Stkhold		    # O= Mem[ DR+1 ] + B
     DRwrite Owrite MEMread Stkhold		    # Mem[ DR+1 ] = O
     uSreset Stkhold
```

That's 13 microinstructions. I forgot the `uSreset`, and we have to do the
`ARincr` separately: we can't do it while we are using AR or DR. This looks
promising. Now let's look to see if the control lines are active high or low.

## Mon 25 May 11:04:37 AEST 2020

We'd be using the 74LS593, the same as the PC. All three lines are active low:
*PCread*, *PCwrite* and *PCincr*. So *DRwrite* from the address bus writer
demux is active low: OK. And all lines out from the data bus reader demux
are active low, so all OK there too. No extra inverters!

I might try wiring this up in the Verilog and see what happens. I've done the
wiring and the existing examples are all OK with the AR registers. Now let's
try the DR register and the above instruction.

## Mon 25 May 12:25:17 AEST 2020

The wiring is done, took a while to get it fixed. I had to add one more
microinstruction, `Zero Carryread Stkhold` to the list as `Carryread` is
overloaded on the data bus reader demux, sigh. The test program is:

```
        mov a,  $FF     # $8000 is #$10FF
        mov $8000, a
        mov a,  $10
        mov $8001, a
        mov a,  $75     # $8002 is #$6675
        mov $8002, a
        mov a,  $66
        mov $8003, a

        addw $8000, $8002	# 14 uInsts, 5 bytes long
```

which is the same as `example06.s` which does the above (not the `addw`) and:

```
        mov a, $8000    #  5 uInsts
        mov b, $8002	#  5 uInsts
        clc		#  3 uInsts
        add a, b        #  4 uInsts
        mov $8000, a    #  5 uInsts
        mov a, $8001    #  5 uInsts
        mov b, $8003    #  5 uInsts
        add a, b        #  4 uInsts
        mov $8001, a    #  5 uInsts, total 41 uInsts
```

Yes I could improve this by doing:

```
        mov b, $8002	#  5 uInsts
	clc		#  3 uInsts
	add $8000, b    #  6 uInsts
        mov b, $8003    #  5 uInsts
	add $8001, b    #  6 uInsts, total 25 uInsts
```

Also, I could write one of the `add`s to be an add with no carry, so let's
remove the 3-cycle `clc` but add one cycle to the first `add`. That's now
23 uInsts. The new 14-cycle version is 64% faster and only 42% the size
of the one without the `clc`. So, definitely an improvement.

I just updated `csim` with this design change. All tests still pass.

## Mon 25 May 13:30:46 AEST 2020

What this means is that we can hide the A and B registers and make the CPU
look like a 2-operand CISC platform with 8-bit and 16-bit operations.

I'm trying to think of opcode names....

```
    loadb $8000, 'x'		# Load 8-bit constant to memory
    loadb $8000, #$45		# Load 8-bit constant to memory
    loadw $8000, #$1234		# Load 16-bit constant to memory
    movb  $8000, $8002		# Copy byte from src to dest memory
    movw  $8000, $8002		# Copy word from src to dest memory
    addb  $8000, $8002		# 8-bit add from src to dest memory
    addw  $8000, $8002		# 16-bit add from src to dest memory
```

Maybe we use the source operand syntax to work out the instruction?

```
    movb $8000, 'x'		# Load 8-bit constant to memory
    movb $8000, $8002		# Copy byte from src to dest memory
    movw $8000, #$1234		# Load 16-bit constant to memory
    movw $8000, $8002           # Copy word from src to dest memory
    addb $8000, #$12		# 8-bit add constant to dest memory
    addb $8000, $8002		# 8-bit add from src to dest memory
    addw $8000, #$1234		# 16-bit add constant to dest memory
    addw $8000, $8002		# 16-bit add from src to dest memory
```

Yes, I think I like this. I'll need to spend some time on constructing
all the new opcodes.

## Mon 25 May 13:55:58 AEST 2020

I think I really do need to capture the high byte of an 8-bit multiply.
Example: `0x30 * 0x23 = 0x690`. Now imagine we want to do a 16-bit
multiply, which we can do with FOIL:

```
	AABB *         Example:   0203 *
        CCDD                      0065
        ----                      ----
        PPPP = BB*DD              012F = 03 * 65
      QQQQ00 = BB*CC            000000 = 03 * 00
      RRRR00 = AA*DD            00CA00 = 02 * 65  
    SSSS0000 = AA*CC          00000000 = 02 * 00 (not needed for 16-bit result)
                              --------
                                  CB2F
```

But we need that `01` from the `012F` result. I was thinking of wiring up
the Carry register to the top 8 bits of ALU result. When we do an 8-bit
multiply, Oreg gets the low 8-bit result and Creg gets the top 8-bits.
But now how do we output it somewhere?

I've already hardwired one bit to the `Cin` ALU input. I was thinking of
making the Creg another databus writer. But that means:

 + either its output is disabled, so no `Cin` value, or
 + its output is on the data bus, so `Cin` only visible when
   we *cannot* use the data bus to read in one ALU operand. Sigh.

It's **so** close! I could make the Creg into an 8-bit "Preg" (P comes
after O) for the top 8-bits, and just use a 74HCT74 D flip-flop for the
carry store. Assuming I do this, that's two DP chips and one D flip-flop,
so now 28 chips. It also means I can grab 8 more bits of output from the ALU!
Not sure that I need it, but it could be useful. Example, shifts and rolls.

## Tue 26 May 11:35:23 AEST 2020

I've added the new I/O handling code to `csim` and it works. Right now, the
Perl simulator has a 1-bit carry. So I'll now go and capture the top 8-bits
of the ALU output. I've renamed the Oreg as the Olow register and there is now
an Ohigh register. Both get set on every clock cycle. The old Owrite databus
writer control line is now Olowrite and there is an Ohiwrite control line too.

All the tests and compile stuff still works. I'll now go modify `gen_alu` to
output the top 8-bits on a multiply. Done. Now to see if it works.

Just transliterated the old `prhex()` function into the new assembly. Argh,
we don't have `1f` jump labels. I'm definitely going to have to rewrite
the assembler at some point.

Ah, small problem. The original Oreg gets updated on each clock cycle. If
we do this for the Ohigh register, we will lose it before we get a chance to
save it somewhere. I think I'll use Carryread as its load line. Now to change
`csim`. Done.

I've changed the `mul a, b` instruction to store the 16-bit result in B/A,
high bits in B. And it works:

```
$ ./cas fred.s; ./csim
45*56=172E
```

That means technically I can try to write a 16-bit by 16-bit multiply
sequence by doing cross-multiplication (FOIL). I'll do that later.

Hah. It also means that I can make a "divmod" instruction and get the results
of both at the same time. Thus, I can make room for one more ALU operation!

Back to the cross multiply. An example:

```
         12  34      Location $8001/$8000
      *  67  89      Location $8003/$8002
---------------
         1B  D4      34*89	# Store in $8004/$8005
     09  A2          12*89	# Store in $8006, add to $8005
     14  EC          34*67	# Store A temp, add B to $8006, reload A etc.
 07  3E              12*67	# Store in $8007, add to $8006
---------------
 07  5C  A9  D4

$07 $06 $05 $04      Locations $80xx

```

Argh. I coded it up, but I get the result `075BA9D4`. I can see why:
there are going to be carries in each byte column. Argh! This means that
we will have to work right to left.

Fixed, it takes 23 instructions to do it. I had to change the "mul"
instruction and store the hi/lo results in A/B instead of in B/A.

## Thu 28 May 11:24:02 AEST 2020

Now I need to make all of this work in the Verilog version, and bring in
the 74HCT74 flip-flop model. Done. I've also added in the OH register.
I've run all the examples and all the hi-level programs in both the Perl
simulator and in the Verilog version; they produce the same output. So
that seems to indicate the the design is OK.

What to do next? I think what I need to do now is to create a bunch of
8-bit and 16-bit instructions which are suitable for a compiler to
target. One problem I've already thought of are the conditional jumps.
For the 8-bit ones:

```
  jeq addr1, addr2, newpc
```

makes sense to compare 8-bit two locations and jump if `addr1`'s value is
greater than `addr2`. To do the same for two 16-bit locations isn't going
to be so easy. We certainly can't do it in one microinstruction.

For example, consider comparing values $1200 and $2300 which are obviously
not equal. If we compare the low bytes, they are the same. But we can't
jump until we can compare the high bytes.

I don't want to encode the addresses twice in successive instructions:

```
  # Jump to L1 if both 16-bit src and 16-bit dest are the same
  jne src, dest, L2
  jeq src+1, dest+1, L1
L2: ...
    ...
L1: ...
```

But the AR/DR registers are already loaded, so perhaps I can write
separate instructions and increment the AR/DR. Something like:

```
  # Jump to L1 if both 16-bit src and 16-bit dest are the same
  jne src, dest, L2
  ijeq L1
L2: ...
    ...
L1: ...
```

where `ijeq` means "increment the AR/DR registers and do the comparison.
It does look like I have to encode two jump addresses though, but I can
live with that.

## Thu 28 May 11:24:12 AEST 2020

What I might also do is look into `acwj` and see what instructions it already
uses, and see if I can write similar instructions here.

```
  .text
  .data
  .globl
  .byte
  .word
  .long
  push register
  pop register
  move between registers
  load constant into register
  load address into register
  widen a value
  narrow a value
  shift left/right, different sizes (will be fun!)
  negate a value, different sizes (will be fun!)
  convert value into zero or 1 (AND with $0001?)
```

are the ones that I'll have to worry about, plus the multiplication,
division and remainder of course. Argh, I'll also need to deal with
indexed addressing! I think I might need to first work out an assembly
syntax.

## Sat 30 May 08:08:05 AEST 2020

I rewrote `cas` yesterday and now have `ncas`. Still a work in
progress. I've started on the new microcode. I have some of
the 8-bit instructions. I've also got some of the 16-bit
instructions working, too. I've just got 16-bit adds and
subtracts done. I'm trying to work out how to fit a 16-bit
left shift in to the 16 microinstructions. Here is my idea:

```
# lslw_ww: shift value at DR left by value at AR
  Load DR and AR values
  Load B with AR value
  Do O= Mem[DR] << B, 16-bit result in Ohi/Olo (Carryread)
  Save Olo to Mem[DR]
  ARincr
  Do O= Mem[DR] << B no Carryread. Now we need to OR Ohi and Olo
  B= Olo
  O= Ohi << B
  Save Olo to Mem[DR]
```

I wonder if I can do ARincr at the same time that I use the
AR/DR registers, as that would save a clock cycle. No, it's
an overload on the databus read demux so it's not a separate
control line unfortunately.

## Sat 30 May 09:36:13 AEST 2020

Following on from the above, I think I just had a good idea. Right now
we have a single control line `uSreset` to reset the microsequencer.
And we have two `StkOp` control lines which both control the stack pointer
chips and increment the PC. We've had to overload the databus read demux
with things like `Carryread` and `ARincr`.

Also, right now the stack pointer chips are clocked by `Clkbar`.

What if we changed the `uSreset` line to be a `StkOp` line which is used to
clock the stack pointer chips. Then the other two lines will become `MiscOp`
lines. All three lines go to a 74HCT138 3:8 demux.

This gives us the low four outputs as control lines. When the `StkOp` line
goes high, this will be a stack operation. So we could have:

```
  000:  unused
  001:  uSreset
  010:  ARincr
  011:  Carryread?
  100:	Stkincr
  101:  Stkdecr
  110:  Stkhold, could be reused
  111:  Stkhold, could be reused
```

Given that `Stkhold` is essentially a no-op on the stack, this gives us
three more active-low control lines and possibly a fourth if `Carryread`
stays where it is. We could also move `Jmpena`, but I don't know if moving
`Carryread` or `Jmpena` gives us any extra parallelism.

This would change the 4:16 demux chip we currently have to a 3:8 demux, so
it doesn't add to the chip count.

## Sat 30 May 09:51:05 AEST 2020

I was also looking at what else on the board I could make into SOIC.
The '593s are available in SOIC packages. I can also get RAM in a
SOIC package, the CY62128E 128Kx8 device. There is also the CY62148G
512Kx8 in a SOIC package. Argh, if only I can think of a way to bank
switch it so that I could implement a filesystem in the RAM. Both also
have very low standby current, so maybe I could arrange some battery
circuit to hold the memory?!

On the TTLers forum, I asked this question: *Could anybody recommend a
suitable resistor value to pull up a high-Z TTL output so that it is
treated as "high"? Or, similarly, a pull down to "low" resistor value? I
need a 4-bit register where I can force the output to be either "0000"
or "1111" based on a control line. I thought I could use the 74HCT574
register which has tri-state output. So when the output is in high-Z I
could force it to be all ones or all zeroes. This would save a chip.*

Alastair Hewitt writes: *The resistor value is part of an RC circuit
where the C is the parasitic capacitance of the gate/bus. This is in the
15-50pF range depending on your chips. I'm seeing around 25-30pF in my
design. It takes about 0.5RC to go from 0 to 2V with the resistor tied
to 5V. A value of 1K will get there in about 15nS. Initially I wanted to keep
it close to the 74F propagation delay of the 74F chips (4nS) and used 270 ohm
resistors. These worked fine but got kind of hot on the final PCB layout.
1k was a good trade off. I remember now that 1K was too slow on the
breadboard, so you may want to go lower if prototyping. The PCB is more
compact and less parasitic and 1K is just fast enough.*

If this worked, I could keep the 138 3:8 demux for the `ROMena` output.
I could use one of the other outputs to be the output enable for a
74HCT574 which would be the bank selector. I think. Now thinking that
I might need to invert that. Anyway, the idea would be to have ROM at
the bottom 8K, then force bank 0 for the next 8K, then the remaining
48K would be bank switched.

We could run the programs in the top 48K of bank 0 and use the RAM
at location 8K to 16K as the buffer to copy in/out from the other banks.

If an extra inverter is a problem, I could change to the 74HCT238 3:8
demux with active high outputs. Let's see:

```
  top 3 addrbus bits -> 74HCT238, active high outputs

  When 000 input, Q0 is high, otherwise Q0 is low. Use this as RAMena
  and invert it to get ROMena.

  When 001 input, Q1 is high, otherwise Q1 is low. Use this as the
  active-low output enable for a 74HCT574 address bank register.
```

So when the address bus top bits are 001, the address bank register
is high-Z. The pullup (or down) resistors force the output to be a
fixed value regardless of the address bank register's actual value.
We will also need a spare databus reader control line to allow the
bank register to read from the data bus. Yes, there is a spare one
and even two if we move `ARincr` to the new three control lines.

I sent this to the TTlers:
*I want to use a 512KB SRAM and an 8K ROM in a design with a 64K address
bus. I want to keep the 8K ROM at location $0000. In the next 8K starting
at $2000 I want a window on the same RAM regardless of the bank switch. For
the remaining 48K I will have a bank switch that selects from one of
eight 48K banks in the 512KB SRAM.

Here is the circuit I am thinking of. Can anybody spot any issues?



The bank switch is a 74HCT574 register which loads from the data bus. It
has tri-state output but I'm using the pull-up resistors as suggested by
Alastair to set the output to "111" when the `~OE` line is high. These
three bits select the RAM bank.

The 74HCT238 is a 3:8 demultiplexor with high outputs. It receives the
top three bits from the address bus.

When the demux input is "000", this sets `~RAMena` high, disabling the
RAM output. An inverter turns this into `~ROMena`, enabling the ROM for
the bottom 8K.

When the demux input is "001", the `Y1` output from the demux is
high. This disables the 74HCT574 register output and forces the selection
of RAM bank "111". Thuus, RAM bank "111" is always used when the top three
address bus bits are "001", i.e. for memory locations $2000 to $3FFF.

For all other values on the address bus, demux `Y0` output is low so
RAM is enabled and demux `Y1` output is low, asserting the bank switch
register values on address lines 16, 17 and 18.*

And here's a memory map:

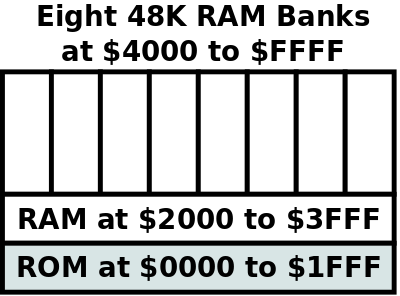
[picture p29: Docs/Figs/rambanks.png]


Assuming that I keep one 48K bank for running code, this leaves
336K of RAM for a file system. That's nearly a whole 360K floppy! So, the
same memory as an Apple ][+, more disk space, a faster clock speed and
some 16-bit instructions! Oh, and the ability to write a C compiler backend
for it.

## Sat 30 May 16:56:52 AEST 2020

I was going to order just the 74HCT574, 74HCT238 and 74HCT04 in DIP package
to test the above. But then I thought: I'm probably going to build FISC2
anyway, so I worked out a BoM and ordered it all from Digikey! Now I've
got to actually design it and lay out the PCB :-)

## Sun 31 May 16:19:47 AEST 2020

Damn, damn, damn! I want 16-bit DR/AR registers that can load from the data
bus, increment and write to the address bus. I thought I could use the
74LS593s as per the PC (and which are in SOIC packages) but no! These
read/write on the _same_ pins! So I can't keep the data and address busses
separate.

The only other incrementing register (in SOIC) I know of is the 74HCT161
which I used in the CSCv2. But these are 4-bit registers. I'd need four
for DR and four for AR. No way. So I will have to order more 74LS469s
in skinny DIP packages from Utsource, as I only have four and I need six.
Damnit! I've ordered six or eight of them.

OK, I've quickly rewired the schematic to have 74LS469s for AR and DR.
For now, I've left `ARincr` as a databus reader demux control line,
because I'll need to add an extra 74HCT138 if I want to demux the
old `StkOp` and `uSreset` lines. If I desperately need extra
microinstructions, I'll add the extra 74HCT138.

## Mon  1 Jun 06:44:56 AEST 2020

I was getting sick of forgetting to put `StkHold` on nearly every
microinstruction, so I modified `gen_ucode` to have a list of lines
to assert by default, and a list of lines that deassert these defaults.
This seems to work.

What I now need to do is to bring all three implementations (Perl,
Verilog, Kicad) into line with each other. I'll probably start with
adding the memory banking to the Perl version. I've added the memory
banking to the Perl version. The next hard bit is the Verilog version
with all the TTL devices to add.

## Mon  1 Jun 13:59:21 AEST 2020

I've left AR/DR as '593s for now (they work) and I've added in the
74HCT238 3:8 demux (active high outputs) and the modified '574 register
(output is high when not enabled). I've also changed the RAM to be 512K.
I also fixed a couple of `csim` bugs. I've written RAM bank test code
and a `bank` instruction. I can write to and read from all the eight
banks, and I can see the shared 8K window from $2000 to $3FFF. This
works in both the Perl and the Verilog versions. Yay!!!

## Mon  1 Jun 14:19:53 AEST 2020

I've replaced the AR/DR with '469s in the Verilog version and they work.
I forgot that `Bankread` was active high so I added it to the inverter
in the Kicad version. So, I *think* all three versions of FISC2 are now
back in sync. Now I need to write more instructions and do more testing.

## Mon  1 Jun 19:28:33 AEST 2020

I've decided to use Carryread as a control line for Ohi/Olow regs and
the Carry register. I've rewritten `csim` to do this and some of the
microcode. Now I need to fix up the Verilog and Kicad versions. Verilog
is done. Kicad is also now done. I nearly made a big gotcha with the
wiring to the O registers but fortunately caught it and fixed it.

## Tue  2 Jun 06:48:01 AEST 2020

I went to bed wondering if there was a 74 series device which was a dual
4-bit register. Then I could use one for carry and the other for the bank
register. No there isn't one, which is a real shame: I could have saved a
chip again! We are at 28 logic chips, one UART, one oscillator and one
reset device. I'm counting that as 29 chips.

I've added some more documentation to the schematic. I've had to create a
SOIC-32 footprint, now sure about the width just yet. I've exported the
netlist and I'm about to start on a PCB design. Very early days.

I've spread it out across a roughly A4-sized board and freerouter is working.
I have tried to minimise the pain points, but I can still see a few.

## Tue  2 Jun 16:20:37 AEST 2020

I started a freerouter running and it began with about 270 vias. After I
could see where the tight/loose areas were, I squeezed in some components.
Now running freerouter, it started at 400+ vias and after an hour is only
down to 370. So obviously it is very space sensitive. And I didn't save
the PCB layout from before.

## Wed  3 Jun 08:06:14 AEST 2020

I made the PCB a bit bigger (215mm x 123mm), spaced out and moved a few
things and I've left freerouter running overnight. It started in the 270 via
area and is now down to 182 after about 12 hours. It's still going. So I will
keep this board size. It's a pity there is no way to get it to save a
snapshot of what it's done periodically, just in case it crashes.

I stopped it at 182. Looks OK. I moved the UART slightly to give a bit more
room for the Decode LEDs. I also moved the Oscillator and clock LED to give
room for the clock daughterboards that I have built. So I can't do much more
on the hardware side for a while. I might turn my attention back to the
microcode.

## Wed  3 Jun 11:16:34 AEST 2020

I did some more instructions. I've done the 8-bit conditional instructions, e.g

```
	jeqb r0, r1, L1
	jltb r0, r1, L2
	jneb r0, r1, L3
	jleb r0, r1, L4
	jgeb r0, r1, L5
	jgtb r0, r1, L6
```

I don't think I can create 16-bit conditional jumps, e.g. `jeqw r1, r1, L2`
to jump is the 16-bit word at `r1` equals the 16-bit word at `r2`. This is
because the jump condition is wired to the instruction opcode.

To do the above, what I really need to do is:

```
	move to the next instruction if the low bytes are different
	do the jump if the high bytes are the same
```

That requires different condition tests and I can't do that. I can simulate:

```
	# jeqw r1, r1, L2 is the same as
	jneb r1, r1, L2a
	jeqb r1+1, r1+1, L2
L2a:    ....

        ....
L2:
```

It's a pity that I don't have three address registers that can increment!
Then I could keep dest, src and jump locations in registers between the
two instructions.

Ah! What if I had a compare instruction which sets the flags in the OH
register?! So:

```
	cmpw r0, r1		# Compare these 16-bit values
	jge L2			# Jump if r2 > r1 to L2
```

The questions are:

+ would an 8-bit compare followed by a jump be more efficient than the
  existing 8-bit conditional jumps?
+ if not, can I keep the existing 8-bit conditional jumps and also have
  the new jump instructions? Yes I think so.

I'm starting to feel that I need an assembler for the microcode!

Right now the condition lines going in to the Jump logic come straight
out from the ALU. This means that we need to load the ALU with the two
operands in the second instruction.

On the other hand, if I reconnect the condition lines going in to the
Jump logic to the OH output, then ... that could be a problem as OH's
output is tristate. But we don't need the databus so it should be OK.
For the existing jump instructions it will add a clock cycle as we
store the result in OH. Example:

```
# Jump if dest equals source
30 jeqb_www: MEMwrite DRloread PCincr
           MEMwrite DRhiread PCincr
           DRwrite MEMwrite Aread        # Get destination value
           MEMwrite ARloread PCincr
           MEMwrite ARhiread PCincr
           ARwrite MEMwrite Bread        # Get source value
           MEMwrite ARloread PCincr
           MEMwrite ARhiread PCincr      # Get jump address
           Awrite A-Bcomp ARwrite Oread	 # Added the Oread
	   Ohiwrite Jmpena		 # Compare and jump if equal
           uSreset
```

But the new no-operand jump instruction would be something like:

```
# Jump if last result was zero
60 jeq: MEMwrite ARloread PCincr	# Get the jump address
	MEMwrite ARhiread PCincr
	Ohiwrite Jmpena
	uSreset
```

## Wed  3 Jun 11:54:32 AEST 2020

Aside: there's a tension going on here. We still have the A and B registers.
For plain old 8-bit operations, instructions like the old FISC which deal
directly with A and B are much more efficient then the new "8-bit value at
a memory location" instructions. But then it's very hard to target a C
compiler at the A/B instructions, especially as there are no "real" registers.

Maybe I need to end up with:

- a set of A/B instructions
- a set of 8-bit in-memory instructions
- a set of 16-bit in-memory instructions

and some warnings that A and B will get clobbered on the 8-bit and
16-bit instructions.

But back to the discussion. Should I move the condition control lines to
the OH output? I suppose I can try it out.

## Wed  3 Jun 12:19:46 AEST 2020

Done and things still work. Now I need to microcode up the `cmpb`, `cmpw`
and the conditional jump-on-flags instructions. Done and they work. For
a 16-bit comparison, I'll need to ripple up the carry from the lower
8-bit subtraction. So I think I'll need to do `A-B-carry` for the `A-Bcomp`
ALU operation. I should be able to clear carry as part of the microsequence
too. OK, I've done that too! My goodness, so much change all in one hit.

But all the microinstructions are getting bigger, sigh.

## Wed  3 Jun 13:36:07 AEST 2020

I realised that I had some lines asserted that were conflicting with each other,
so I modified `gen_ucode` to spot them and die. I found about six or seven!
Oops, so that was a useful modification to make. The 16-bit comparison instruction
(destlo-srclo followed by desthi-srchi) now works.

I also just adjusted the schematic to have the flags change to the output side
of OH. That's the databus, so I just realised that we could store OH into memory
and, at a later point in time, pull the flags back in and jump!

## Wed  3 Jun 14:15:00 AEST 2020

Running freeroute again, starting with 274 vias and 19.4M trace length.

If I put back in the A/B instructions, I might relabel the registers as X/Y
because `b` now means "byte" in the opcode names. I've done a few with more
to go.

## Thu  4 Jun 07:52:35 AEST 2020

Freeroute is down to 164 vias. That's better than the 182 the last time.
I've added back nearly all of the old FISC instructions but with X/Y names.

## Thu  4 Jun 11:32:09 AEST 2020

I've added some push/pop instructions to the microcode. Along the way I found:

 + I had a deassert bug in `gen_ucode`, now fixed.
 + `cas` needed a proper tokeniser, now fixed.
 + I needed some pseudo instructions. I've added some.

Down to 160 vias with freeroute. And it's ended. Also, the Digikey FISC2
parts have arrived! Here's a render of the PCB at the moment:

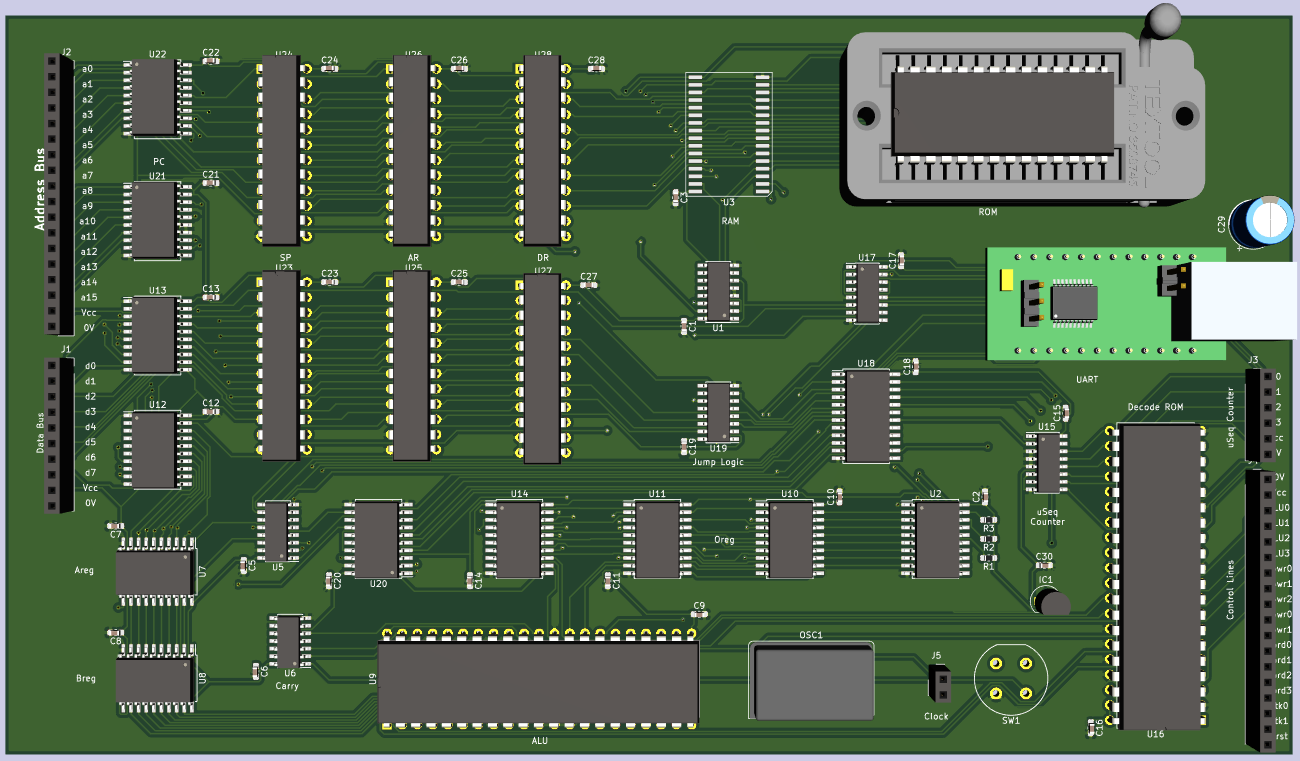
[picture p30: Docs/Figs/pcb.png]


## Thu  4 Jun 14:00:29 AEST 2020



I've built the RAM bank circuit with the parts that have just arrived.

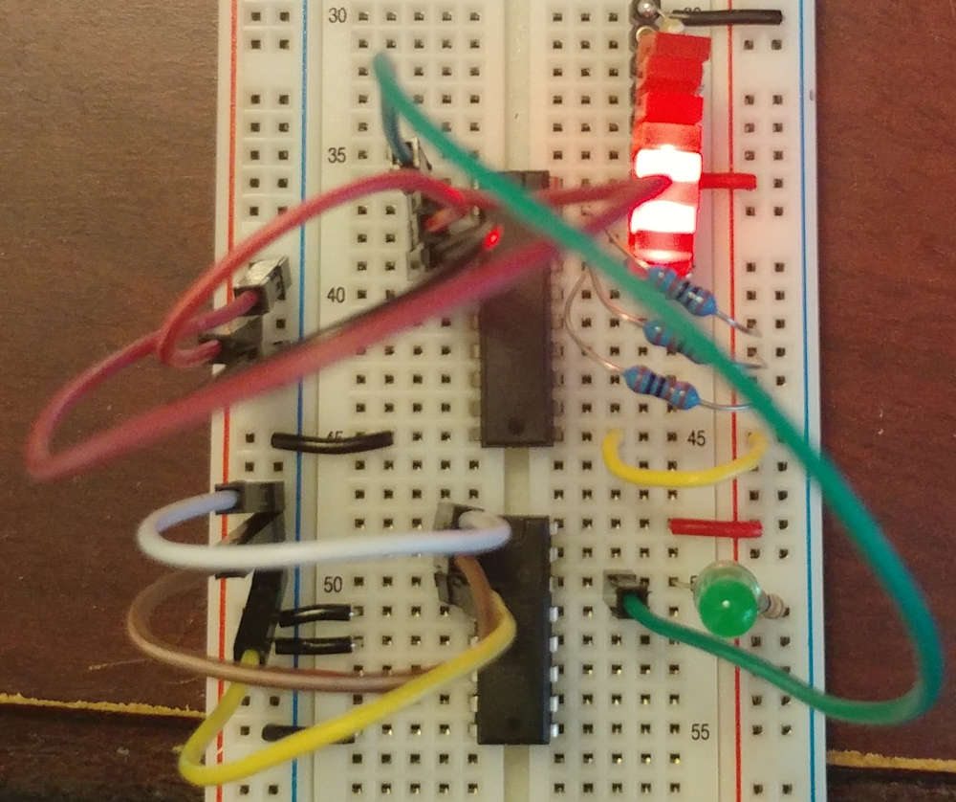
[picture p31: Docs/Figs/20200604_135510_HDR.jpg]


Ignore the top red LED which is lit, this is tied to the Vcc of the
'574 chip. I've loaded "010" into the register using the red/red/black
jumpers at the top-left. The `~Bankload` line is the yellow wire just
below the three resistors. The resistors are the pull-ups for when the
register is high-Z. The green jumper going to the '574 output enable input
from the '238 Y1 output. In the above photo, I've selected RAM region
"000" with the white/brown/yellow jumpers. The Y1 line is low, so the
'574 output is enabled and we see the bottom three LEDs displaying "010".

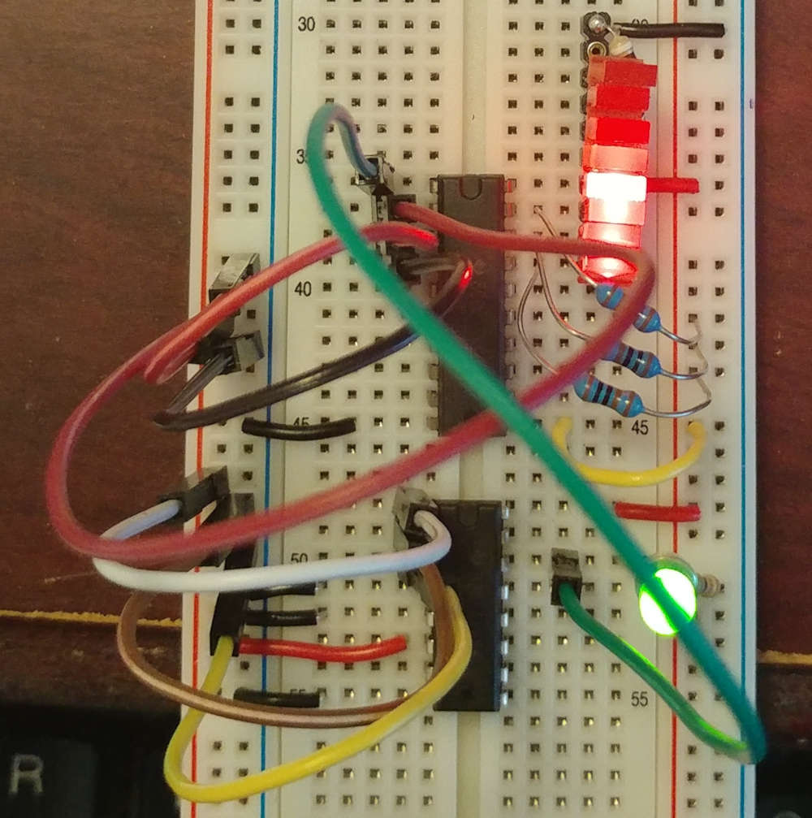
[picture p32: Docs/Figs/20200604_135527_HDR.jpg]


Now I've moved the white jumper to 1, so that the RAM region being used is
"001", i.e. 16-bit address `$2XXX`. This forces the Y1 output high. This
puts the '574 output into high-Z and the pullup resistors turn this into
"111". You can see the green LED show that Y1 is high, and you can see
the bottom three LEDs are all on.

So, it does look like the RAM bank circuit will work.

## Sat  6 Jun 07:38:19 AEST 2020

I've been thinking of the calling convention for the CPU. I think it's going
to be:

 + caller spills all in-use registers before the call
 + caller pushes all arguments on the stack
 + jsr
 + callee uses the arguments, and has local variables with negative
   stack indices
 + callee returns a value through r0

What I do need is to come up with a set of instructions and opcode
nmenonics for accessing the stack. I did this with FISC but I need
to redo them. Something like:

 + move from sp+offset to rX and vice versa

I'd also like to put (back) in some indexed instructions. Examples:

```
int x[5];	// Global variable
r0= x[3];	// Known base, constant index
r0= x[r1];	// Known base, register index

int *ptr = x;	// Global variable
r0= ptr[3];	// Get value at ptr, add constant index
r0= ptr[r1];	// Get value at ptr, add register index
```

Now imagine that `x` and `ptr` are on the stack, either as arguments or as
local variables. We now need to do:

```
r0= x[3];       // SP + constant, constant index
r0= x[r1];      // SP + constant, register index
r0= ptr[3];	// Get value at SP + constant, add constant index
r0= ptr[r1];	// Get value at SP + constant, add register index
```
 
I think I'll do these on a needs basis when I'm writing the compiler backend.
Either way, I'll need a way to represent the operand. At present, we have
'b' bytes, 'w' words and 'l' longs. I can use other letters for these new
operand "types" (not the best word to use).

Imagine:

```
int a;		// Global
main() {
  int b;	// Local at known stack offset

  a= b;
}
```

We want an instruction that does `movw a, sp-2`. The `-2` will be encoded
as a 16-bit signed value. How about the instruction name `movw_ws` where
`s` stands for "SP + constant"? I think that's good. I'm just thinking of
the assembly code for `puts()`. The pseudo-code would be:

```
puts: get byte from *argument
      jump if NUL to L1
      print it on UART
      increment argument
      jump to puts
L1:   rts
```

So perhaps also another operand suffix which means "deref'd address on
stack". I'm going to need to make a list of these things!

 1. b: byte
 2. w: word
 3. l: long
 4: s: value at stack offset
 5: p: value through a pointer
 6: P: value through a stack offset pointer, might be too ambitious

Going back to `puts`:

```
puts: movb r0, *sp+2	# Get byte from *argument
      cmpb r0, 0
      jeq L1		# Jump if NUL to L1
      out r0
      inc sp+2
      jmp puts
L1:   rts
```

There are a few instructions there that don't exist yet!

## Sat  6 Jun 18:26:43 AEST 2020

I just added `movb_ws`, which moves a value at an offset from the stack
pointer into a memory location. Lots more to do!

## Sun  7 Jun 07:24:34 AEST 2020

I'm trying to write the microsequence for `movb dest, *src` and I'm getting
stuck. As the `dest` comes first, it gets put into DR first. The the `src`
address into AR. Now I need to get the pointer in AR. To do that, I'll
need to increment AR to get the high byte. But ... that will also increment
the DR even before I've used it!

I could try to shuffle the dest address first into A/B and then back,
but that's lots more microinstructions and I may not have enough :-(

Crazy idea: I could make the last unused databus writer demux output into
`~DRincr`. Thus, it is separate from `~ARincr` but it can also be asserted
at the same time.

## Mon  8 Jun 11:22:58 AEST 2020

I've done the above, fixed the existing micocode and added two more `mov`
instructions which move a byte to/from via a pointer. I've modified `cas`,
`csim` and the Verilog version and all tests still pass. I also updated the
Kicad version.

Damn. I was hoping to squeeze in "move word to/from pointer" instructions
but I've run out of microinstructions and I can't see how to reduce them.
We have too many data bus readers, and we can't write B directly out to the
data bus!

Hah, I fixed it. We can update AR in the same cycle that we use it, so that
saved a microinstruction and now it fits. The "move word to/from pointer"
instructions work as well in `csim` and Verilog. Yay! It's starting to feel
like a usable CPU, now. But the overall instruction speed is going to be
slow compared to the clock speed.

## Mon  8 Jun 12:48:57 AEST 2020

The eight '469s from UTsource arrived. I still haven't properly started
building FISCv1. I just did an experiment where I bring the final `uSreset`
microinstruction up and merge with the second-last one. It works with `csim`
and the Verilog version. No idea if it will work with real hardware yet.
Would be nice if it does: each instruction is one less clock cycle.

I started to (re)build FISC1, so things here on the FISC2 side might be
put on hold. I'm hoping there will be few lessons learned on FISC1 but
and I do learn will help out here on FISC2.

## Tue  9 Jun 09:20:12 AEST 2020

I've ported the `clc` compiler from FISC, using the A/B instructions. I
was going to rewrite it using the new 8-bit instructions, but the compiler
is written assuming two registers. It would actually be more inefficient if
I tried using the 8-bit instructions.

## Wed 17 Jun 11:09:20 AEST 2020

I've built the FISC CPU and I'm testing it. I've hit a bad problem with
the choice I made with how to loadd the stack pointer chips. These are
74LS469s, and they need the `~LD` signal to be low *before* the clock
signal comes in. In FISC, I'm generating the `~SPloread` and `~SPhiread`
lines as edges at the same time as `Clkbar`. So they are definitely not
set before the clock comes in.

So ... I'll need to generate all the 74LS469 load lines at the start of the
clock cycle and not in the middle of the clock cycle. This means that I
can't use the existing databus read demux to generate the 74LS469 load
lines, like I can for the registers (A/B/O) and the memory devices. And
that means I'll have to rethink my control line demultiplexers.

## Fri 26 Jun 11:46:39 AEST 2020

I had spent a few days working on a solution which, in the end, involved
a second decode ROM to generate more control lines. I've ditched that and
I now have a nicer solution. Here it is.

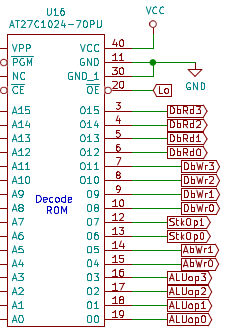
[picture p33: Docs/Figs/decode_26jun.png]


The decode ROM still outputs the same four ALUop lines, the same two address
bus writer lines and the same two stack operation lines. We still have the
same 2:4 demuxes for these, and `~PCincr` is still being generated as one of
the four stack operations.

I've merged `~uSreset` so that there are now four data bus writer bits. These
are decoded as follows:

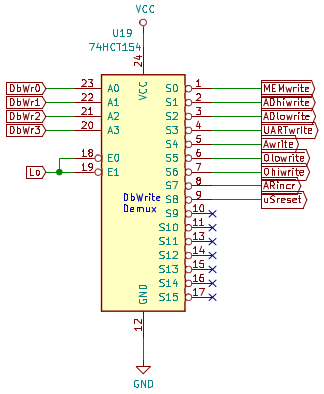
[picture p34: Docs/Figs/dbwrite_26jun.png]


These are the existing seven data bus writer control lines, which all have to
be enabled at the start of the clock cycle. That's why the two enable lines are
pulled low. All of these seven control lines are active low. I've put in
`~uSreset` here as it is done when we are not writing on the data bus. I've
put `~ARincr` in here so that it is separate from `~DRincr`. This allows us to
do them at the same time, which will save a clock cycle with the 16-bit instructions.

Now the interesting part, the data bus reader decode. There are now **two**
demuxes. The first one is this one:

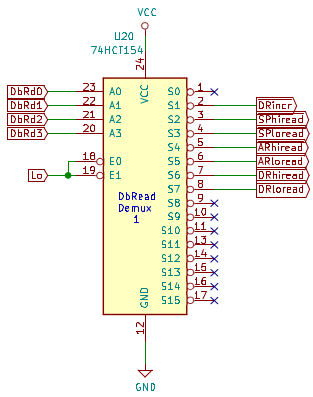
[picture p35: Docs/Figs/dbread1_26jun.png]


Again, the enable lines are pulled low so the outputs occur at the start of the
clock cycle. Note that we are only using the first eight outputs; the first
one is unused so that we can *not* read from the data bus.

All of these control lines are going to the 74LS469 counters, so we need them
to be asserted at the start of the clock cycle. `~DRincr` is here for the same
reason, and also because I can separate it from `~ARincr`.

But there is a *second* data bus reader demux:

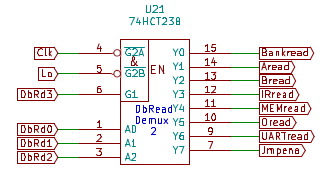
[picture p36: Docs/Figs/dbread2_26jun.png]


This is a 3:8 demux with active *high* outputs. These ones go to the 74HCT574
registers which need to be rising signals: `Bankread`, `Aread`, `Bread`, `IRread`
and `Oread`. And they have to rise mid-cycle.

To make this happen, the active low enable line `~G2B` is wired low and the other
active low enable line `~G2A` is wired to `Clk`. So when `Clk` goes low,
one of the outputs goes high. Thus, a rising signal mid-cycle.

And here's the tricky part: `DbRd3` , which is the most significant bit of the four
data bus read control bits, is wired to `G1`. This ensures that the output of the
3:8 demux can only go high when we are selecting something from the *upper half*
of the range of data bus read control values. Thus, `Bankread` is value $8,
`Aread` is $9 etc.

This is the only easy way I could think of to have some data bus read control lines
become active at the start of the clock cycle as *values*, and others go active
mid-cycle as *edges*.

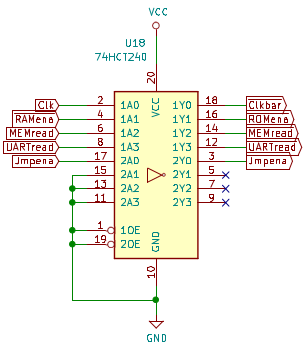
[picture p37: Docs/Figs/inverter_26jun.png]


Finally, some of the outputs from this 3:8 demux have to be falling edges, so we
send them to the inverter, along with the clock and the RAM enable line.

And, somehow, we are still at 29 chips.

## Sat 27 Jun 08:30:18 AEST 2020

This time I'm going to breadboard each part of the control logic before I
order the PCBs. This will allow me to check the timings and ensure that
the 74LS469 counters are working properly. I've ordered a bunch of DIP
chips which are used on the control side of things. While I wait for them
to arrive, I've made a start on the breadboard. I have:

 + an oscillator socket, connected to
 + a 74HCT161 counter, no resets yet, connected to
 + a Decode ROM socket with the IR lines pulled low

I won't build the whole control side. What I will do is check each
demux in turn, and connect them to an controlled device. Example,
I can check the Stack Operation bits and the SPloread lines by
connecting them to a 74LS469 to ensure that it does load, increment
and decrement.

The existing circuit is counting happily for now.

## Sat 27 Jun 09:02:40 AEST 2020

Now that I've moved the control lines around, I need to fix up
the microcode, the Perl simulator and the Verilog simulator. I've
just done the microcode. Now to do the Perl simulator.

OK, `csim` is now updated and it passes all the current tests.
I'll do the Verilog version later as it will need a lot of work.

## Sat 27 Jun 11:02:59 AEST 2020

I've just created a handful of instructions so I can use
them on the breadboard to verify that the control logic is working.
One nice idea that I had was that I can use the timings I see on
the logic analyser to adjust the timings in the Verilog model to
make it even more accurate.

## Sat 27 Jun 16:21:36 AEST 2020

OK, I've rewritten the Verilog version to match the new control
logic wiring, and it passes all the test from 01 to 12 again.
I also realised that I can replace the first data bus reader demux,
currently a 74HCT154 with a 74HCT138 using `DbRd3` as one of the
control lines like I did with the second data bus reader demux.
This is a smaller chip and it might make the wiring a slightly
bit simpler as well. Ditto, I can replace the octal inverter
with a hex inverter which is also a smaller chip.

## Sun 28 Jun 17:15:06 AEST 2020

I was writing up new docs for the design and implementation of
FISC2. I have the carry flag wired up wrong in the schematic
and I must fix it. For a while I couldn't work out why the
jump inputs come from the output of *Ohi* and not the ALU
output. Then I remembered, we need to store the flags so
we can do a compare in one instruction and then jump based
on these flags in a second instruction.

## Mon 29 Jun 08:15:53 AEST 2020

I removed the reset line going to the Carry flip-flop to make 
the PCB layout just a bit simpler. But I also added a pin
header for power, just in case I need to plug in the logic
probe. Hopefully the DIP devices will arrive tomorrow and I
can check the control logic on the breadboard. I'm feeling
confident about it now.

## Mon 29 Jun 11:57:04 AEST 2020

I fixed up the PCB layout with the new chip, and I've set freerouter
running on it to give me an idea of the pain points. It started at
305 vias, which is up from the ~270 vias on FISC. Well, with four
new chips I'm not surprised.

## Mon 29 Jun 13:23:02 AEST 2020

I saw where some tracks were tight and I moved a few things out
to add some more space. Now freerouter has started with only
263 vias, which is great news!

I ws reading in a TTL book and saw: Good practice calls for an
unused LS input to be tied to 5V. HCT inputs can be tied to
either 0V or 5V. I must remember to do this for the unused D
flip-flop.

And now I'm worried about fan out on the data bus. Apparently
about ten LS devices is the maximum fan out. I've got six
74LS469s, four 74HCT574s, a ROM (M27C322), a RAM (CY62148)
and a UART (UM245R). So maybe I should put in a buffer just
for the 74LS469s. Which one to choose? I'm already using a
74HCT541. Is there a more "powerful" one?

## Tue 30 Jun 09:36:13 AEST 2020

I've stopped the freeroute, added in the unused D flip-flop,
tied its inputs and redid freeroute using the existing tracks.
All OK. Down to 174 vias. Here's what it looks like:

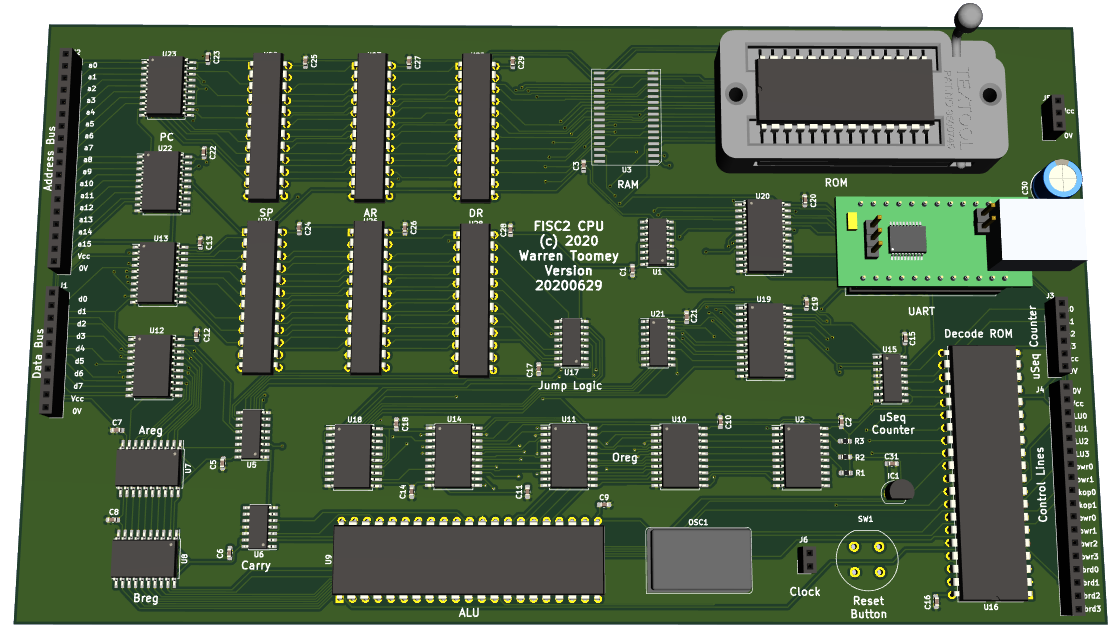
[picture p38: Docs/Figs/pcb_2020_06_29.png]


On inspection, I can see a few bypass caps in the wrong place so
I'm going to have to fix them, anyway. Damn!

## Tue 30 Jun 09:36:19 AEST 2020

Back to thinking about the ALU. We have a spare ALUop now that
I can merge div and mod. We also have A-B and A-Bcomp which are
pretty much the same except A-Bcomp passes out the B value.

Now that I have OHireg, can I use the `asr` ALUop to pass B's
value out on the high 8 bits? That would mean that I now have
_two_ spare ALUops! And, what to do with them?!

## Tue 30 Jun 17:55:06 AEST 2020

I'll come back to the ALU, but my DIP TTL chips are here. So I'm doing
some timing measurements. First up,

74HC161 propagation time clk to out: 12.5nS.
74HCT161 propagation time clk to out: 15nS.
AT27C1024 Decode ROM propagation time from input change to output change: 20nS.

Here's the circuit so far:

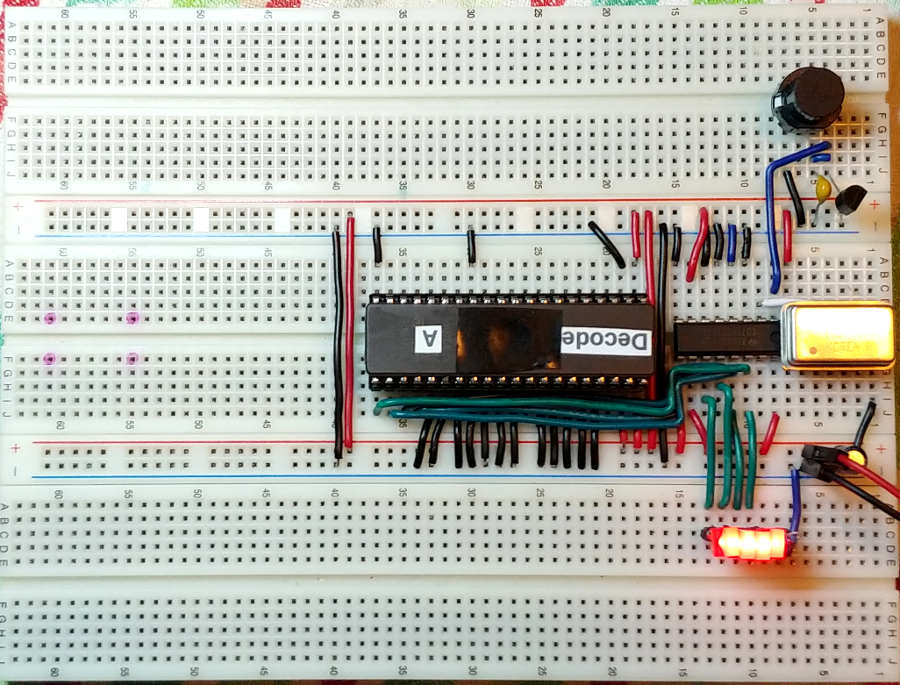
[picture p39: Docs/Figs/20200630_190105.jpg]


The 1MHz oscillator is on the right with the reset circuit above it. Next
left is the 74HCT161 driving the LEDs and the low four bits of the Decode
ROM. The remaining ROM inputs are tied low. On the top side of the ROMs
are the currently unwired outputs. There's a 22uF cap near the power input.

So at present I'm running the NOP instruction at 1MHz, which gives me
enough bits to compare the input change to the output change.

I've just put the 74HCT139 address bus writer demux on the breadboard.
I've checked the Stack Operation bits and the `~SPwrite` line
against this opcode:

```
D1 stkops:
	MEMwrite IRread PCincr	# 1
	Noread
        SPloread
        SPwrite			# 2
        Stkincr			# 3
        SPwrite			# 4
        Stkincr			# 5
        SPwrite			# 6
        Stkdecr SPwrite		# 7
        Stkdecr SPwrite		# 8
        SPloread SPwrite	# 9
        SPwrite			# 10
        uSreset
```

Here is the resulting waveform with signals `Clk`, `Stkop0`, `Stkop1`
and `~SPwrite` from top to bottom. I've added numbers for the above steps.
It all looks good.



While I've got the 74HCT139 on the board, here's a measurement for it.
74HCT139 input to output change: 12.5nS.

## Wed  1 Jul 07:19:30 AEST 2020

I can't believe that I don't have (and didn't order) any 74HCT154 4:16
demux chips! I must have ordered the '541s and thought they were '154s at
the same time. So, for `~SPloread`, I am using a 74HCT138 3:8 demux on
the breadboard. Here's a measurement for it.
74HCT138 input to output change: 12.5nS.

I've put the 74LS469 up/down counter on the breadboard, and wired it up
to the two `StkOp` lines and the `~SPloread` line. I've wired a constant
input of $02. So it's the moment of truth time. Can I get the '469 to
load the value of 2? Here is what value it should have:

```
D1 stkops:
	MEMwrite IRread PCincr
	Noread
        SPloread		# 2
        SPwrite
        Stkincr			# 3
        SPwrite
        Stkincr			# 4
        SPwrite
        Stkdecr SPwrite		# 3
        Stkdecr SPwrite		# 2
        SPloread SPwrite	# 2
        SPwrite
        uSreset			# 3
	default			# 4
	default			# 5
	default			# 6?
```

I am not decoding `~uSreset` so the microsequencer will count from 0 to 15.
Those last three microinstructions are all zero which by default is a
stack increment operation.

And here is what I see, the lines from top to bottom are `Clk`, `Q0`, `Q1`,
`Q2` and `Q3`.

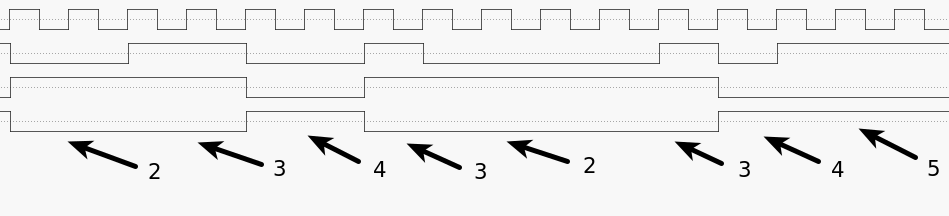
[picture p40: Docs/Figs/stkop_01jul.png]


And that's a beautiful thing as I can see the chip loading the value $2,
incrementing and decrementing. I'm not seeing the increment to 6 but I'm
not worried by that. I'm very happy to see the 5 change to a 2 right on
the left-hand side of the figure.

Now, I need to augment this to have a `Clkbar`, so I've put a 74HCT240
octal inverter on the breadboard. 74HCT240: input to output is 10nS.

I've tied the bottom three 74LS469 inputs to some Decode ROM outputs
just to show that I can load different values. Here's the microcode
with that I think is the register's output value:

```
D1 stkops:
	MEMwrite IRread PCincr
	Noread
        SPloread		# 0 load
        SPwrite
        Stkincr			# 1
        SPwrite
        Stkincr			# 2
        SPwrite
        Stkdecr SPwrite		# 1
        Stkdecr SPwrite		# 0
        SPloread SPwrite	# 2 load
        SPwrite
        uSreset			# 3
	default			# 4
	default			# 5
	default	
```

And here's what I see with the logic analyser:



So, yes, it is loading different values at different times.
Also, 74LS469 load to output change: 12.5uS.

Here's the breadboard at present:

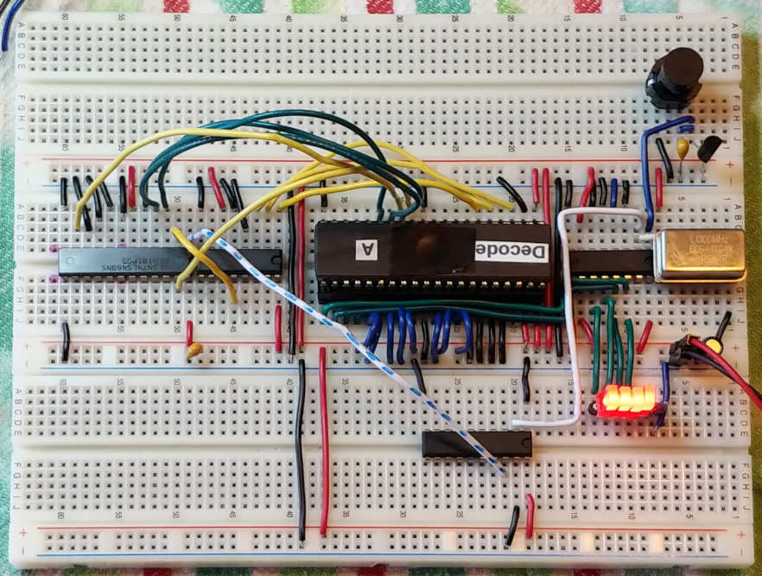
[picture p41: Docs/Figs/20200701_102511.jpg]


We have, from left to right:

 + 74LS469 up/down/counter
 + 74HCT138 3:8 demux
 + AT27C1024 Decode ROM
 + 74HCT240 inverter below the ROM
 + 74HCT161 4-bit counter
 + 1MHz oscillator
 + DS1233 reset device above the oscillator

## Wed  1 Jul 10:34:22 AEST 2020

Yesterday on the TTLers forum I asked about possible fan out problems and
Alan and Alastair gave me some feedback. I tried to work out the high/low
input and output currents for all the devices on the data bus, and I made
a spreadsheet for it. I think I've concluded that I'm OK for the data bus.
Yes there are eight LS readers but all the other readers are CMOS (so low
input current required), and all the bus writers have enough output current
to drive all the bus readers.

I think that means that I don't need another 74HCT541 buffer just to drive
the LS devices. I also asked Alan if he would review my design and he's
agreed to, so hopefully he will spot any glaring mistakes I've made. So far
he's worried that the AT28C64B Instruction ROM delay is 150nS, and at
3.57MHz half a clock cycle is under 140nS. I think I'm OK because I
didn't have any troubles with it on CSCvon8 running at 3.57, but it's
something to watch out for.

Therefore, I'm going to set freeroute running twice (simultaneously)
and get some tracks laid down again.

## Wed  1 Jul 11:47:08 AEST 2020

Back to the ALU redesign. I had this idea. We can now
capture two lots of 8-bit results for each ALU operation.
Not all of them have to be flags. I could move
some of the logic operations to the high bits
as they can get stored in OHireg. So, this is
possible:

Op  | Low Bits           | High Bits
---:|:------------------:|:---------
 0  |  0		 |  Flags (Z for jump)
 1  |  A + B		 |  Flags (Carry)
 2  |  A - B		 |  Flags (Carry and jumps)
 3  |  A + 1		 |  Flags (Carry)
 4  |  A - 1		 |  Flags (Carry)
 5  |  A + carry	 |  Flags (Carry)
 6  |  A * B		 |  High bits of multiply
 7  |  A / B		 |  A % B
 8  |  A AND B		 |  B
 9  |  A OR B		 |  A XOR B
 A  |  NOT A		 |  NOT B
 B  |  A << B		 |  High bits of shift
 D  |  A >> B arithmetic |  A >> B logical
 D  |  spare		 |  spare
 E  |  spare		 |  spare
 F  |  spare		 |  spare

This leaves six 8-bit operations that I can
add. I'm just wondering: would there be any
ALU operations that would help when doing 16-bit
arithmetic? Especially as I can read/write the
two AR registers and the two DR registers. I can't
think how at present, but it's something to
investigate.

## Wed  1 Jul 13:06:24 AEST 2020

Back to the breadboard. I'm now trying the second databus reader demux, the
one that's a 3:8 decoder but I use the clock and the `DbRd3` bit to
enable the output. Looks like it's going to work:

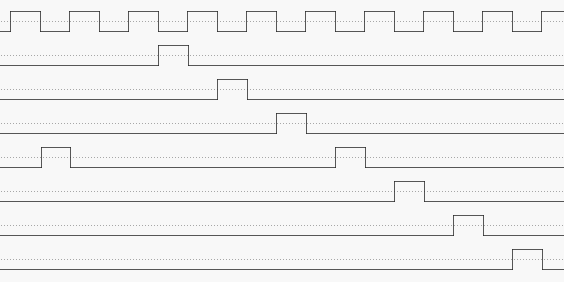
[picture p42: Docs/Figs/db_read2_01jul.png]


We need rising clock edges mid cycle and that's what we see. The first one is
the `IRread` signal. Then I do:

```
D5 dbrd2:
	MEMwrite IRread PCincr
	Noread
        A-B Bankread
        A&B Aread
        A|B Bread Awrite
        A^B IRread
        A<<B MEMread
        A>>B Oread MEMwrite
        A*B UARTread
        A/B Jmpena
        uSreset
```

I don't have enough analyser pins deployed to catch the `Jmpena` signal
but I'm sure it will be there. 74HCT238: delay from input to output is 10nS.

I also checked the carry:



That's the reset line, clock, input and output.
74HCT74: clock to output change is 12.5nS.

Next up is the Instruction ROM, the AT28C64B device that Alan is worried
about. I wired the low four address bits up to the '161 counter and wired
the others high.



The trace shows the fastest counter pin and three data bit outputs.
You can definitely see it glitch as it finds the data value internally.
Also, the output delays are not synchronised. The worst I saw with
this small sample of 16 addresses is a 35nS propagation delay. Alan
did say that it is possible that some data values might require
a delay of up to 150nS.

## Wed  1 Jul 16:18:29 AEST 2020

Alan's looking at the design and I'm getting some good feedback. He's
not happy with the 1K pullup resistors and recommends 22K ones instead.
I'll definitely have to try that out. He doesn't think that the PCB
layout is crucial. He doesn't like my register control line names, or
my flags names!

Alan did point out something that I hadn't fully realised and there some
potential there. The jump logic is now effectively wired to the data bus,
because the OHireg writes to the data bus and that's where the jump logic
reads from. Implication: we don't have to read the flags from the OHireg;
in fact, we can read them straight from the data bus.

I've just updated the Verilog version to reflect this. All the tests
are still OK.

Ah, a slight panic then. Alan pointed out that the CY62148 datasheet
says it's a 3.6V device, not a 5V device. After I spent some time
looking for a replacement part, I checked my parts purchase and found
that I'd bought a CY62148GN-45 which is a 5V device. So I'm OK!

## Thu  2 Jul 08:23:07 AEST 2020

I'll try this for the testing of the bank switch circuit with the different
resistors. The bottom three '161 output lines will be inputs to the bank switch
register. The top one will be the output enable line, so half the time the
register should be disabled. The 1MHz clock will be the register's clock input,
so the register should change value each time the counter changes.

I will feed this to my EEPROM (as I can't pre-program the RAM). The first
eight values will be 00 to 07. I'll monitor the ROM's output. With the
register `~OE` tied high I should see all eight values. With the 
register `~OE` tied to the top counter bit, I have no idea what I should
see for the second half of the values. Then when I add in the resistors,
I should see 07 for all of the the second half of the values.

## Thu  2 Jul 17:54:04 AEST 2020

I've wired the above up. Here is the output of the register with the `~OE`
pin tied low:



Top signal is the clock, the rest are the three output bits. It's outputting
the count of the '161 fine. Now I'll wire the `~OE` high and make the
output tri-state:

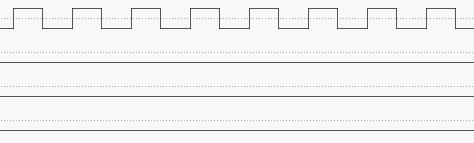
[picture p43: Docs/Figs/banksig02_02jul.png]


So all the outputs appear low but they are actually hi-Z. Now I'll wire
the `~OE` to the top bit of the '161 counter:



It counts for eight clocks then goes hi-Z for the next eight clocks. Fine.
Now let's try some 22K resistors on those outputs. Actually, I only have
20K resistors:



Looks the same, unsurprisingly. I wonder what my DSLogic Pro thinks is
the threshold between low/high for a) the high-Z and b) the pullup
resistors. For the high-Z, I'm seeing glitches around the 1.7V threshold.
With the pullup resistors, about 4.4V. This is with the register outputs
connected to the ROM inputs, so it's a realistic test. Now let's see what
the ROM outputs. It should be 0 to 6, then nine lots of 7.



And that's what I see on the output of the ROM. So it does look like I
can use 20K or 22K resistors instead of 1K resistors as the pullups.
I think that's the only change that I need to make.

## Thu  2 Jul 19:35:51 AEST 2020

I thought I'd let the auto place mechanism in KiCad put the components on
the board. So I cleared all the tracks, moved everything off except the
UART and let KiCad put them back. Then I spaced them all out evenly
over the PCB. Then I let freerouter have a go at the board. Once it had
routed the tracks, it had an initial via count of 346! That's pretty
terrible compared to my initial ~260 vias. In that case, I won't alter
the PCB at all now. I do still need to do the copper pour on the board.

## Thu  2 Jul 21:56:10 AEST 2020

I've changed the resistors to 22K on the schematic, poured the copper, done
the DRC, made the gerbers, sent them to JLCPCB and I've ordered the PCBs!
Now I need to find out what components I'm still missing and order some
of those. It's starting to get expensive.

## Fri  3 Jul 10:01:44 AEST 2020

You know, I forgot to check all the footprints on the PCB before I ordered
it. In particular, I didn't check the CY62148GN footprint. I just did and
it is slightly too narrow. It's not completely bad, but I might have to tin
the pads and the IC legs, then sit the chip on the pads and heat each leg
in turn to get them to "take".

I might try this out with a spare SOIC chip and the FISC board I've stuffed
up.

Here is the list of components that I definitely still need to buy:

 + three 22K resistors
 + SOIC HCT238
 + SOIC HCT74
 + SOIC HCT154

Given the freight charge, perhaps I should buy another set of components?
Also, maybe a 2MHz oscillator. I'll think about it.

Now, a long-term roadmap of things to do (apart from build and test the
FISC2 PCB), in no particular order:

 + write the boot ROM a la CSCvon8
 + add more instructions
 + choose the spare ALU operations
 + port the acwj C compiler
 + write a C version of the simulator
 + design a file system and system calls
 + add library functions to the ROM
 + make the C compiler self-compiling on the actual hardware

## Sat  4 Jul 15:44:48 AEST 2020

I worked on some more instructions today, adding 'X', 'Y' and 'sp' as
register keywords to `cas` as well. I was going to work on a `puts`
function where the base pointer is pushed on the stack. I've just found
out that:

```
        ldw $8000, $4342
        pushw $8000
```

puts $42 and $43 on the stack, not $00 $80. What I also want is to push
the pointer, not the value at the pointer. I need to do this:

```
fred:	.str "Hello there"
	pushsomething fred	# Push base address of fred on stack
```

Do I do this by naming the instruction, or by adding a decoration to the
operand?

```
	pushptr fred		# or
	pushw &fred
```

## Sun  5 Jul 10:50:33 AEST 2020

I went for the latter. Now that I'm trying to write `puts()`, I realise
that I'm going to need a whole bunch of new instructions that deal with
local variables, e.g.

```
	movw xxx, sp+1			# Move word from local to global
	movw sp+1, xxx			# Move word from global to local
	addw xxx, sp+1			# Add global and local
	addw sp+1, xxx			# Add global and local
	addw sp+1, sp+3			# Add local and local
```

Otherwise, I'll have to move stuff into the pseudo-registers, do the work
on them and move back to the locals. That would slow things down an awful
lot!

This FISC2 CPU is a project that going to keep me going (insane?) for a
very long time, there are just so many things that can be done. I might
even run out of instruction positions.

Now I'm wondering if I should modify `gen_ucode` to use the C pre-processor
(or add in my own pre-processor) because of the large amounts of duplicate
microcode. OK, I've just done this. I've added a couple of macros, but I
haven't done the whole of the `microcode` file yet.

Later, yes I've added a lot of macros to the `microcode` file.

## Mon  6 Jul 13:28:53 AEST 2020

I started on porting the "acwj" compiler to FISC2 last night. Only a
very small start, and I'll keep a separate journal.

In hindsight, yes I should have made the uSeq counter bigger than
4 bits so I could have *huge* instructions!

I was also wondering if I could clock the CPU at a higher speed
but for the slow components latch their control inputs for two
clock cycles, e.g. the ALU. It would be interesting to get up to 8MHz
or 10MHz :-) I could lose the 8K Instruction EEPROM and replace it
with a 4K EPROM. I could use a 4:16 demux for the memory regions
and have only a 4K shared region. This would give me eight 56K
memory banks. That's 448K of RAM! And if I could interface an SD
card, that would be excellent. Perhaps this could be FISC3.

## Mon  6 Jul 20:23:04 AEST 2020

I've added more pseudo-ops to the assembler: `.rom`, `.text` and `.data`.
I think they work but I'll have to keep an eye on them. I now need to
modify the simulator to load the `cas` output into RAM. OK, that's done
too, and I've altered the code that builds and runs the examples to
know about the new `-l` flag to `csim`.

## Tue  7 Jul 11:07:47 AEST 2020

I've added more instructions this morning. These deal with pointers
on the stack. Again, I've have to break instructions into two instructions.
Oh well. I just squeezed into the 16 microinstruction limit. I also realised
that I can leave out the `uSreset` when I need exactly 16 microinstructions!
That gives me one extra microinstruction if I need it.

The PCB should be arriving early next week, but I also start teaching
again next week. I've just written a list of what to solder in which
order. The big killer with this design is you need to do all the decode
logic pretty much in one hit!

Next up: get `cas` to input multiple files. That will be fun. I'll
have to pass one on all files, then pass two on them all again.
No, it was easy as we pre-load all the input files into an array.
I got rid of the `cpp` usage for now because it throws off the
line numbers.

## Tue  7 Jul 16:10:09 AEST 2020

I think I haven't got `.data` working properly in the assembler yet, so
that's something I will have to look at. I went crazy and sketched out
the beginning of a design with a 16-bit data bus, several 16-bit registers
and two ALU ROMs so that it is 16 bits wide.

## Tue  7 Jul 16:58:09 AEST 2020

Yay, I think I've fixed the `.data` problem. I can now do this:

```
$ cat input001.c
void prwhexn(int val);

int xx;

void main()
{ xx= 12 * 3; prwhexn(xx);
  xx= 18 - 2 * 4; prwhexn(xx);
  xx= 1 + 2 + 9 - 5/2 + 3*5; prwhexn(xx);
}

$ ./cwj -S input001.c
$ ./cas crt0.s prwhexn.s input001.s
$ ./csim -l
0024
000A
0019
```

So that's the first C program compiled, assembled and simulated with
no hand editing. I can't (yet) test it in the Verilog version as it
expects the Instruction ROM to have the code in it.

One thing I will have to think of is how to name the registers so that
they don't conflict with the C symbols: `r0` ... `r7`, `x` and `y`. That's
why I had to use `int xx;` above. For now, I've renamed `x` and `y` to
`rX` and `rY`.

I've made a start on tansliterating the CSCvon8 monitor, but I think
I need to write some instructions so I can do `address+rY` indexing.

## Sat 11 Jul 11:26:05 AEST 2020

It's been a tough time with my wife in hospital. This morning I've
managed to get the monitor working properly, and I've uploaded and
run my first program via the monitor:

```
C4000
06 48 06 65 06 6c 06 6c 06 6f 06 0a 50 Z
```

which simply prints out "Hello". I will add a `-o` flag to `cas`
so we can choose the output file name. Done.

I've also ordered a hot air reflow station and also a tablet oscilloscope,
so my addiction is getting serious! The PCBs arrived last night, but
I'm going to wait until the reflow station and the solder flux arrives.

## Sat 11 Jul 16:52:07 AEST 2020

I just realised that the instruction mnemonics that `clc` is using are
out of date, so I brought it up to date. It also now compiles and
assembles to an "a.out" format which I can upload to the new ROM monitor.
So once I build the hardware I will be able to burn the ROM once and
the upload programs through the monitor.

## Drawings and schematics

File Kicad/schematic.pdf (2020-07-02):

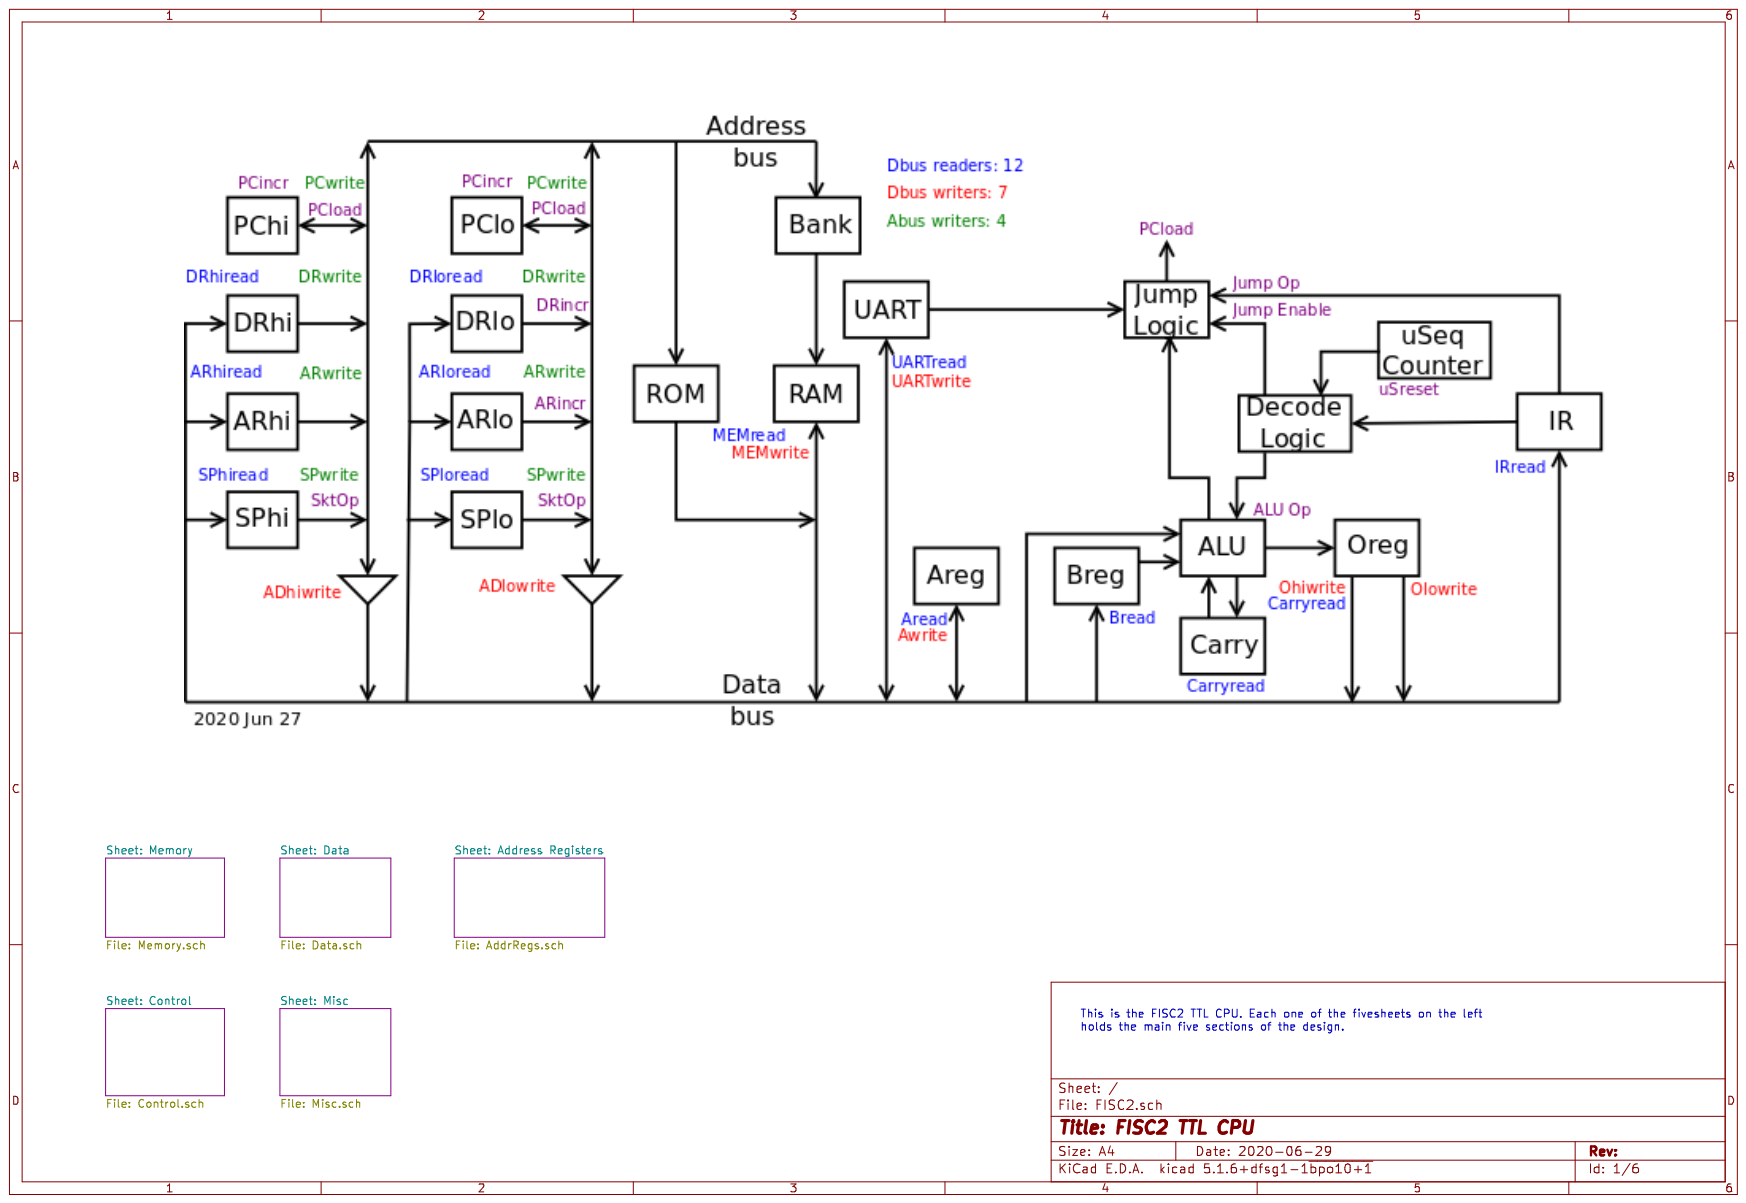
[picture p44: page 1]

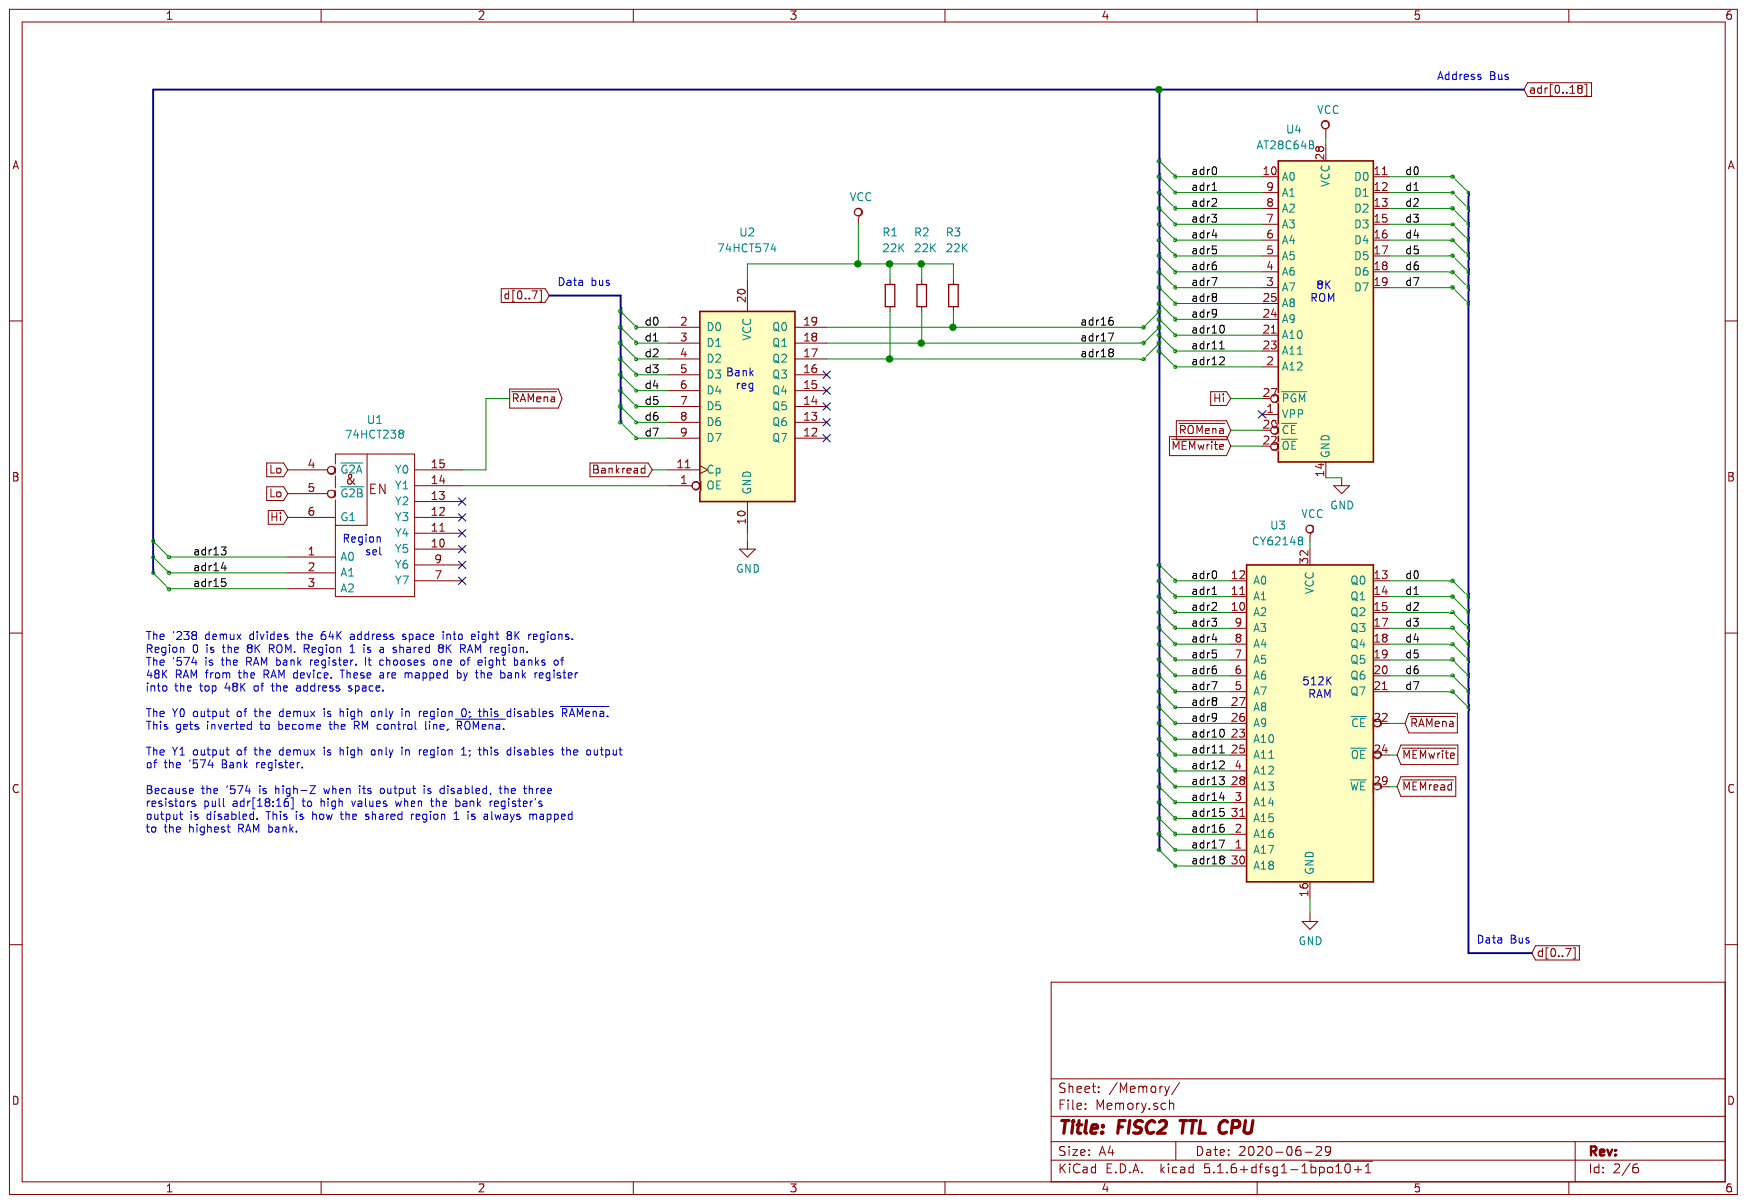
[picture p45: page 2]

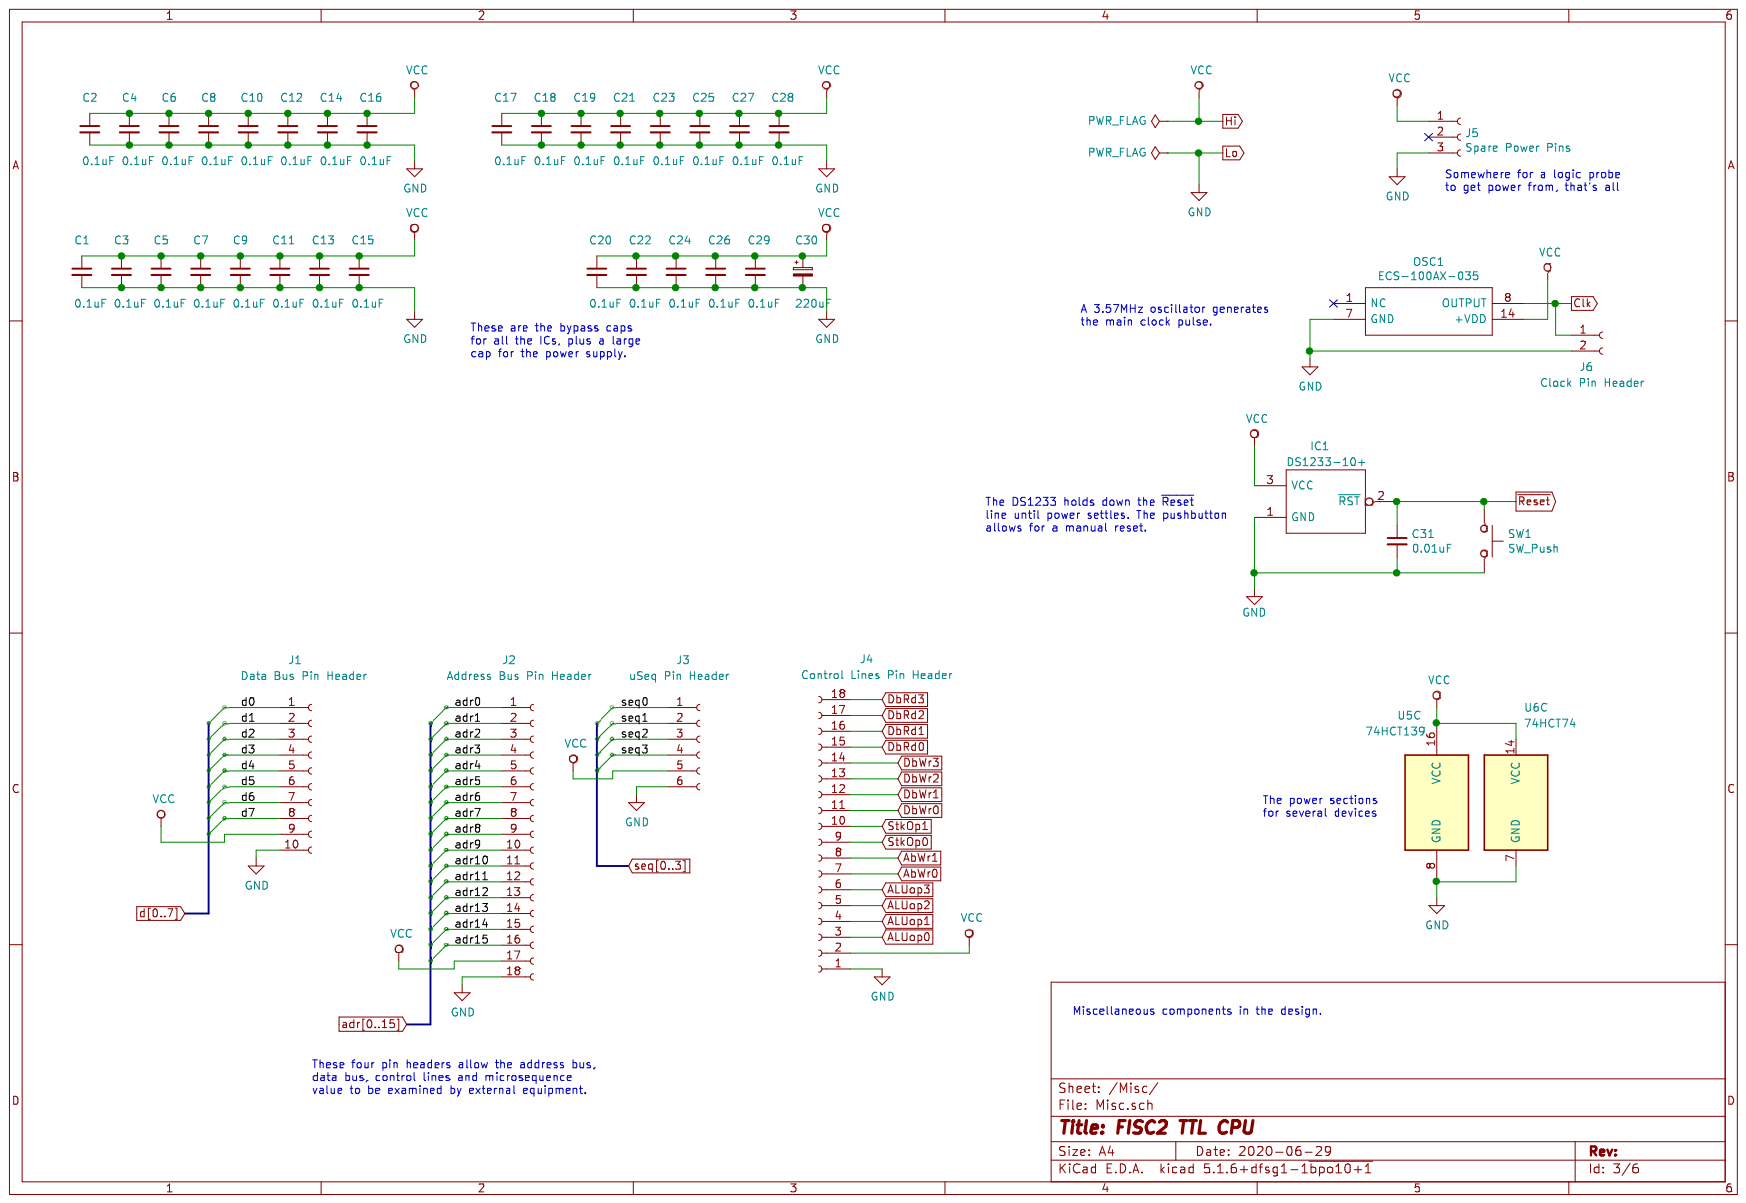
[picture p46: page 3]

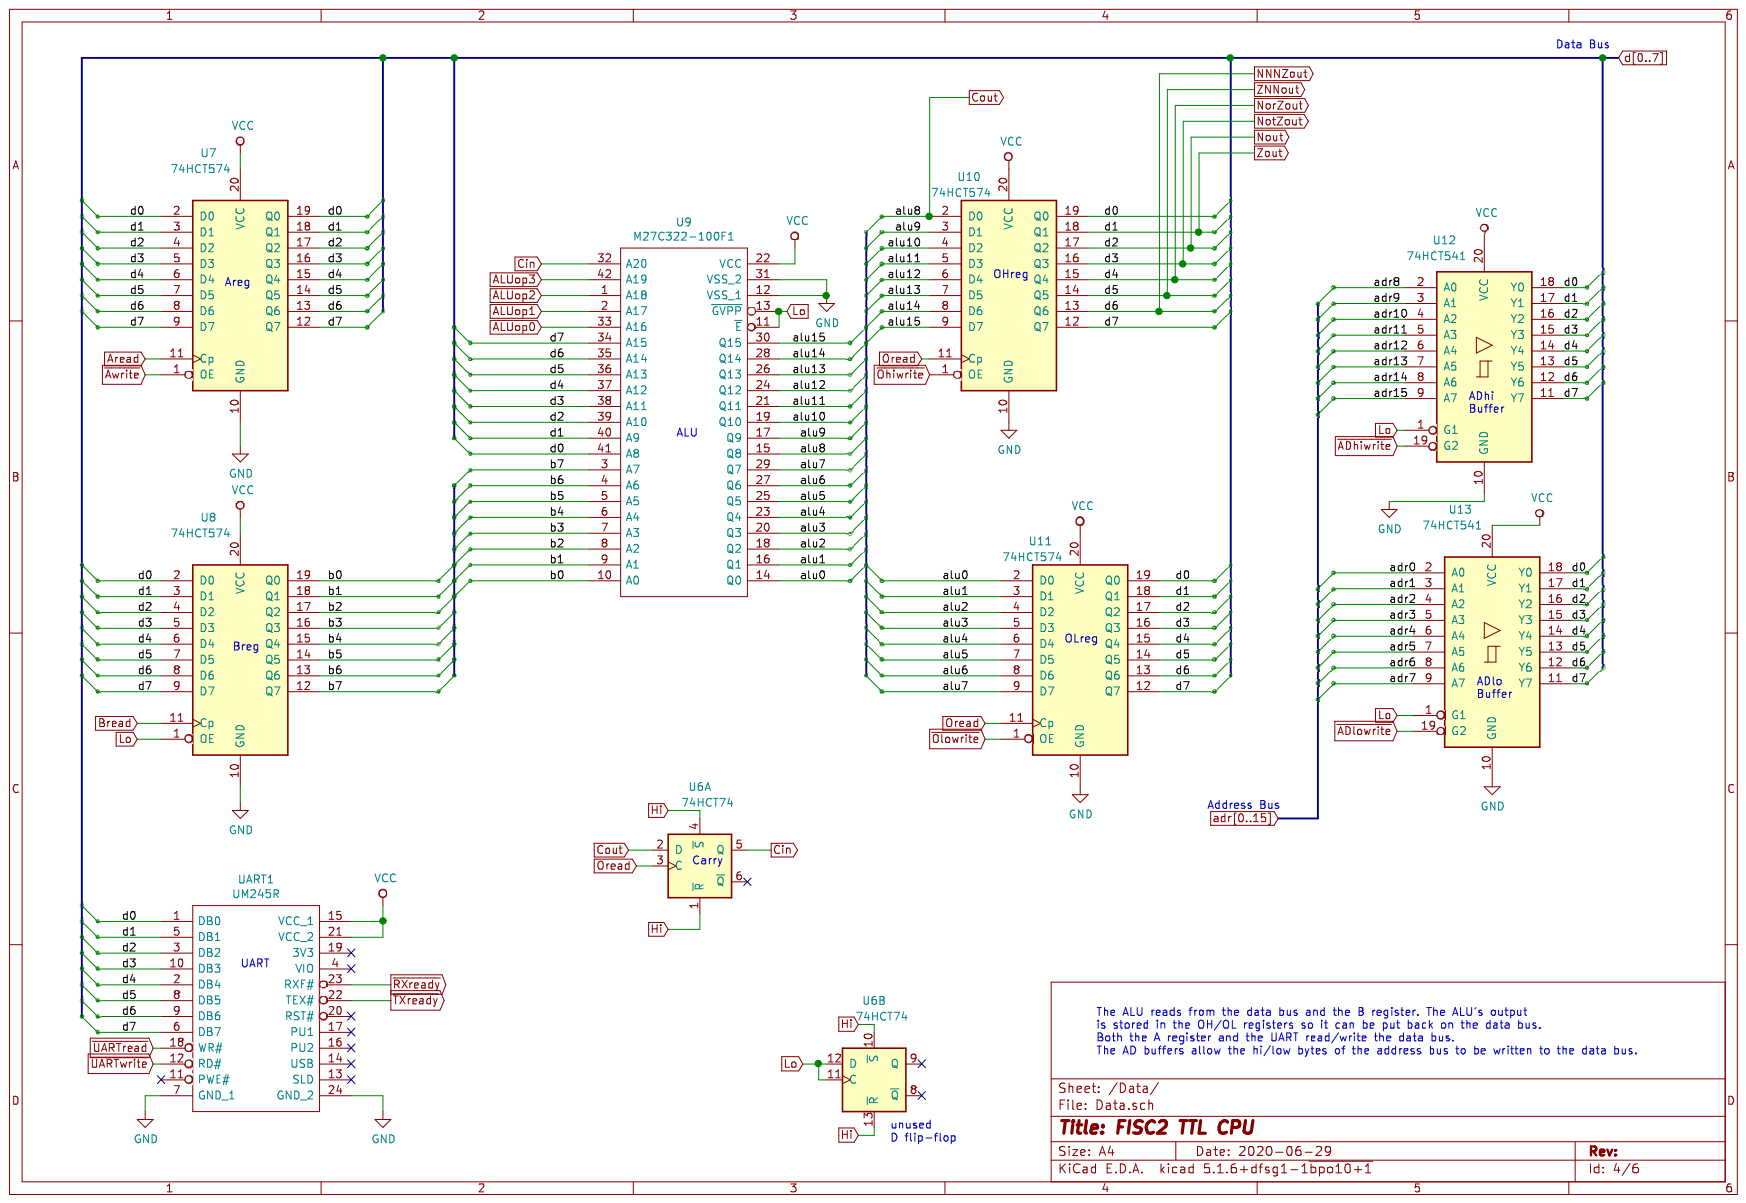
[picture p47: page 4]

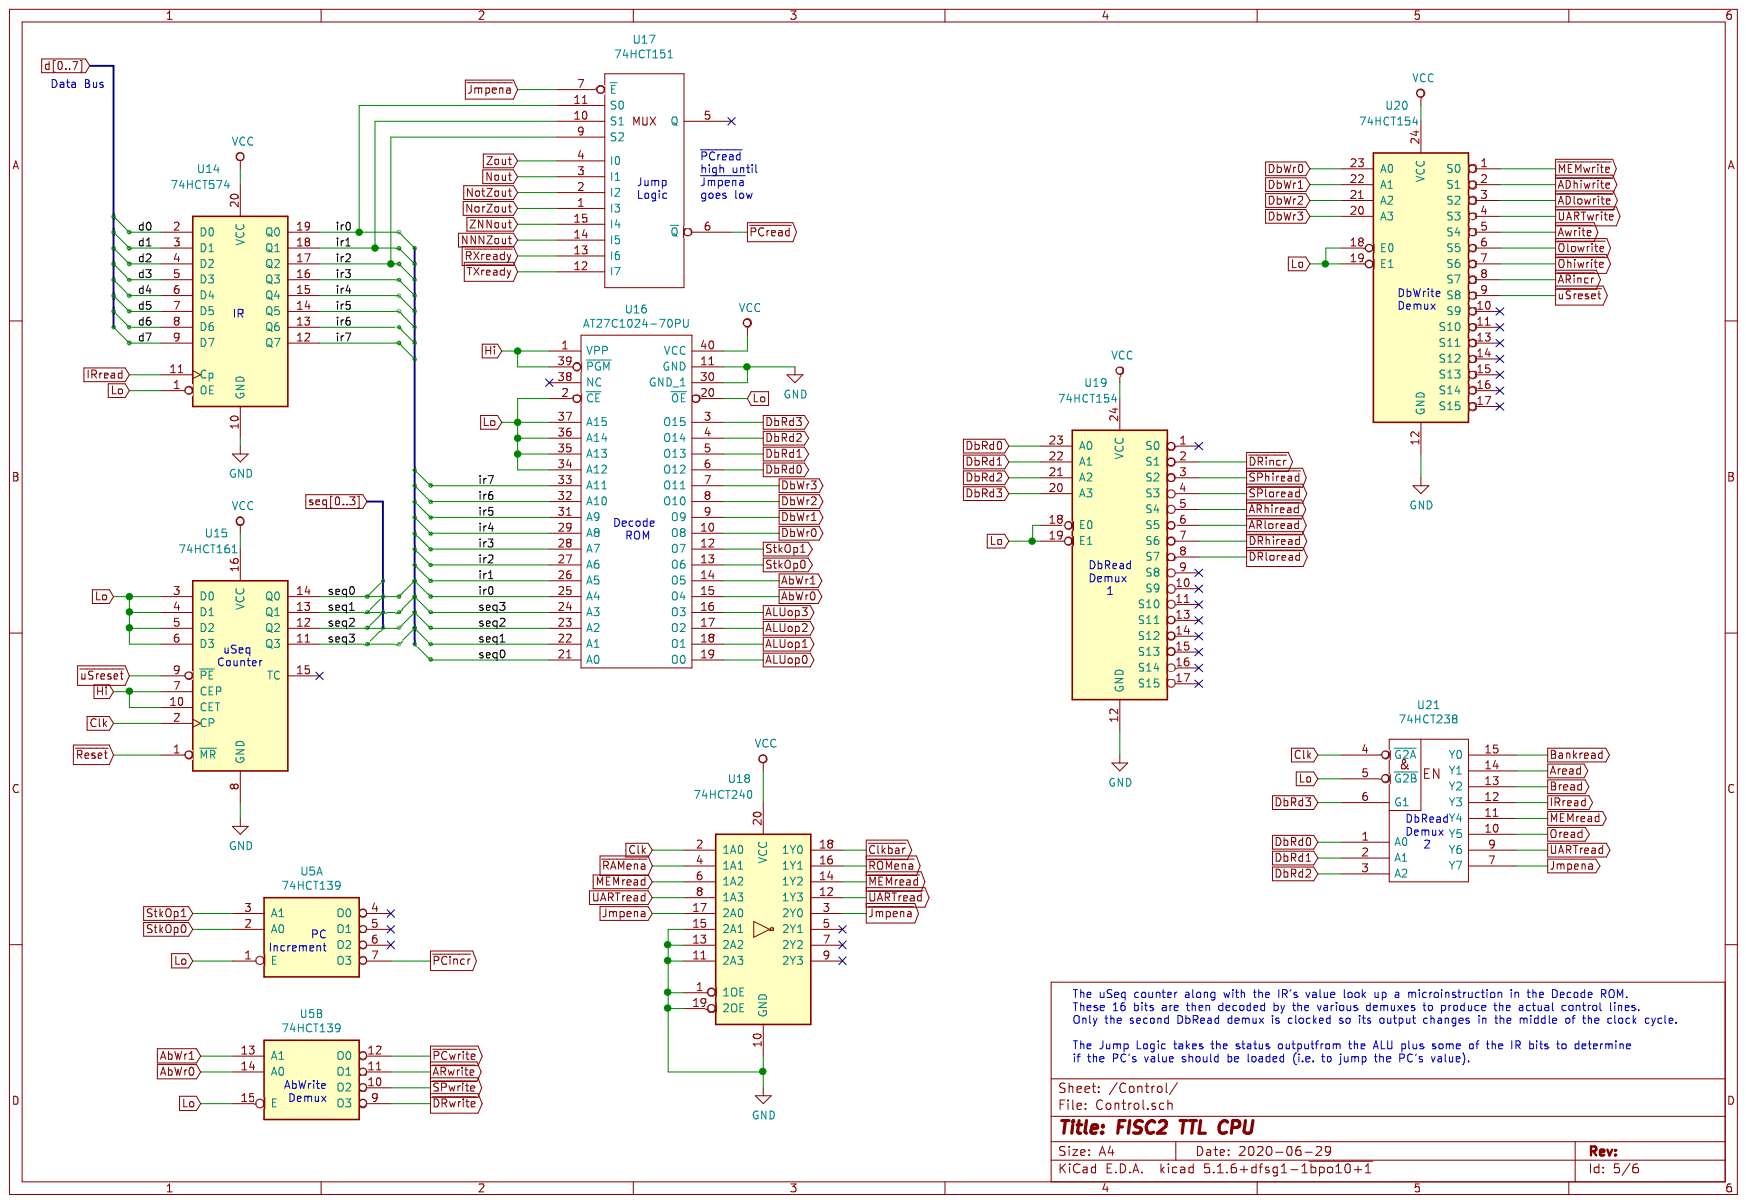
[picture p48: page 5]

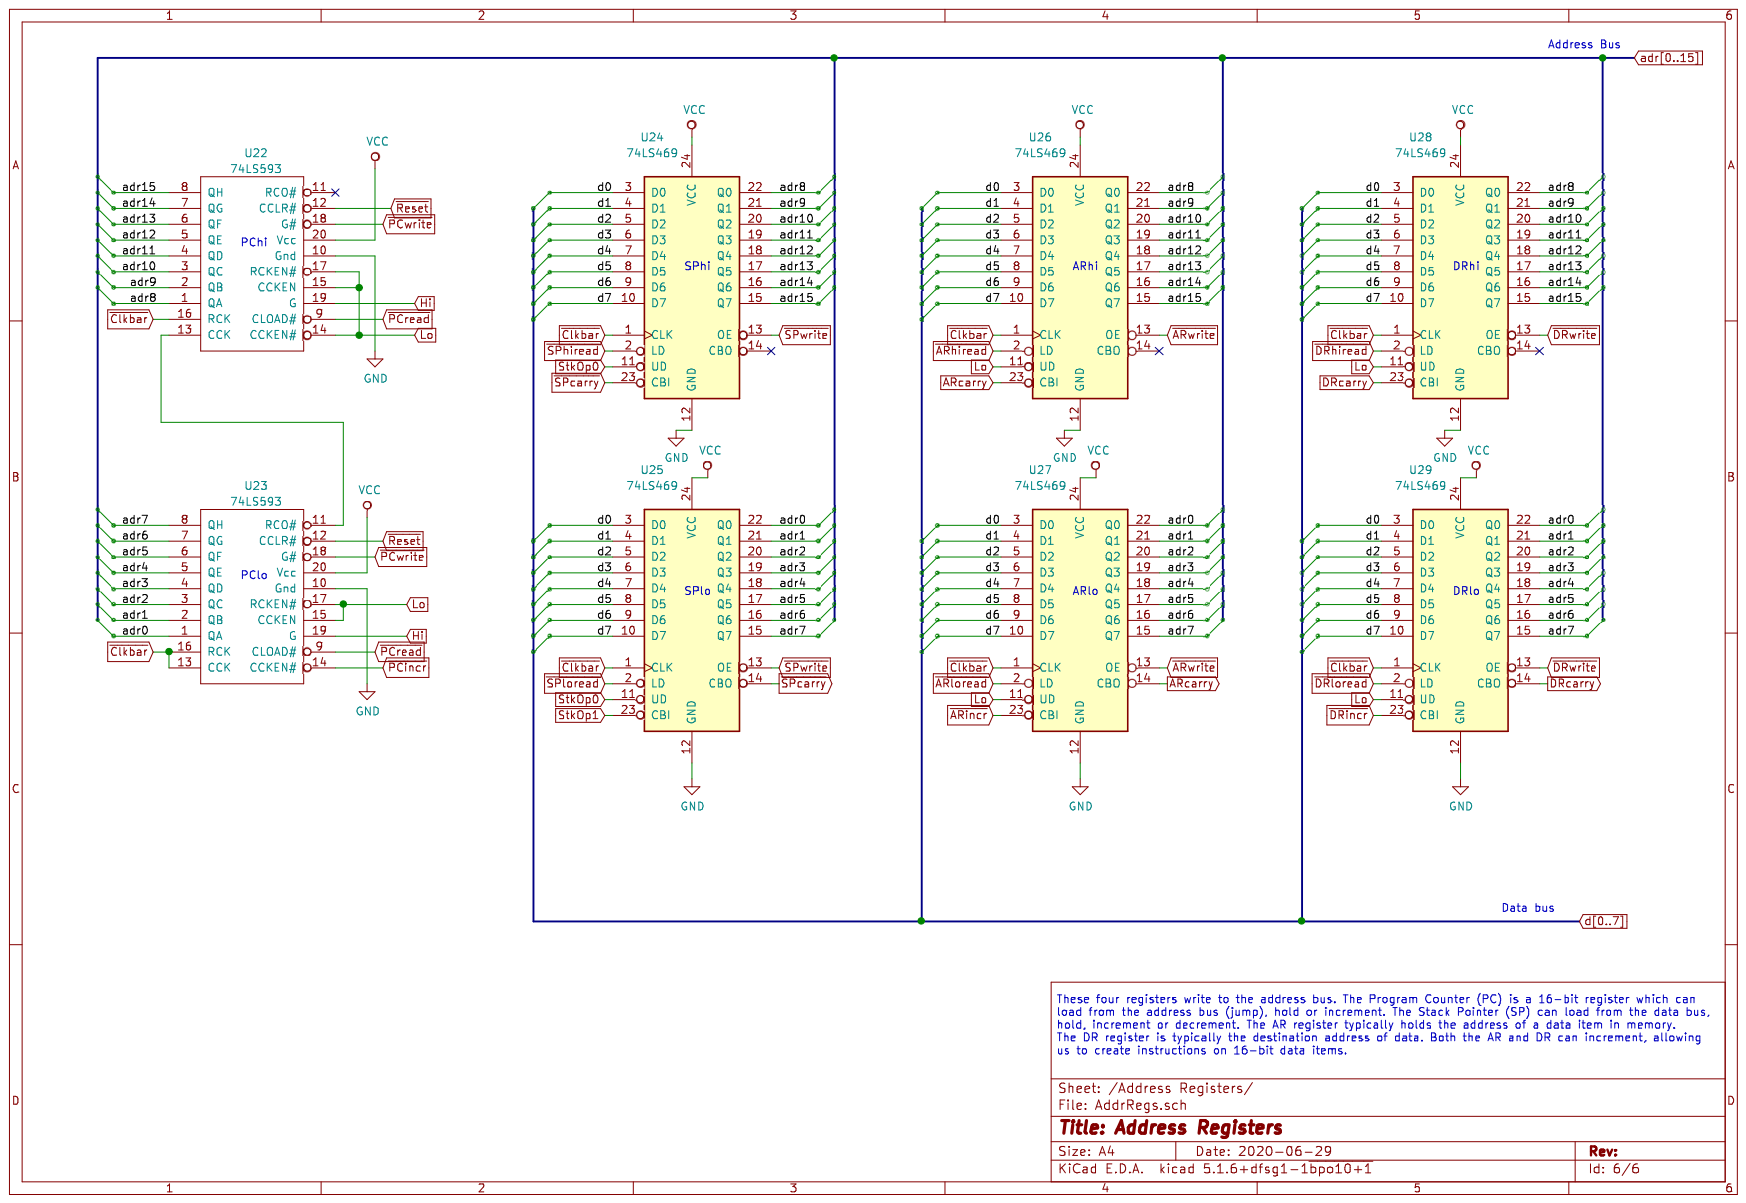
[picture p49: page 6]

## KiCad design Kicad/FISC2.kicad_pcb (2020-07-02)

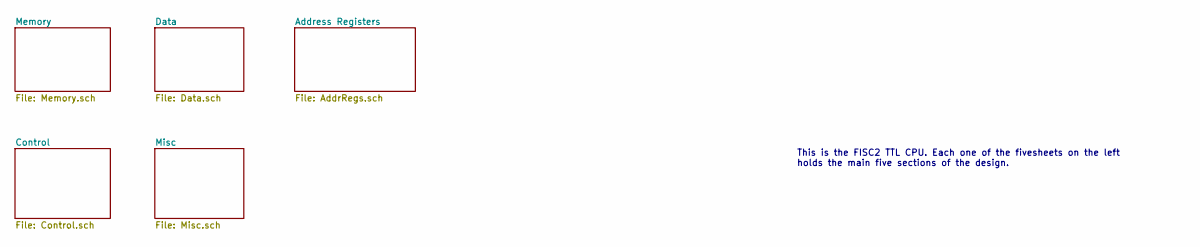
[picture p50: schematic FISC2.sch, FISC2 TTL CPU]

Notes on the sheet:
This is the FISC2 TTL CPU. Each one of the fivesheets on the left holds the main five sections of the design.

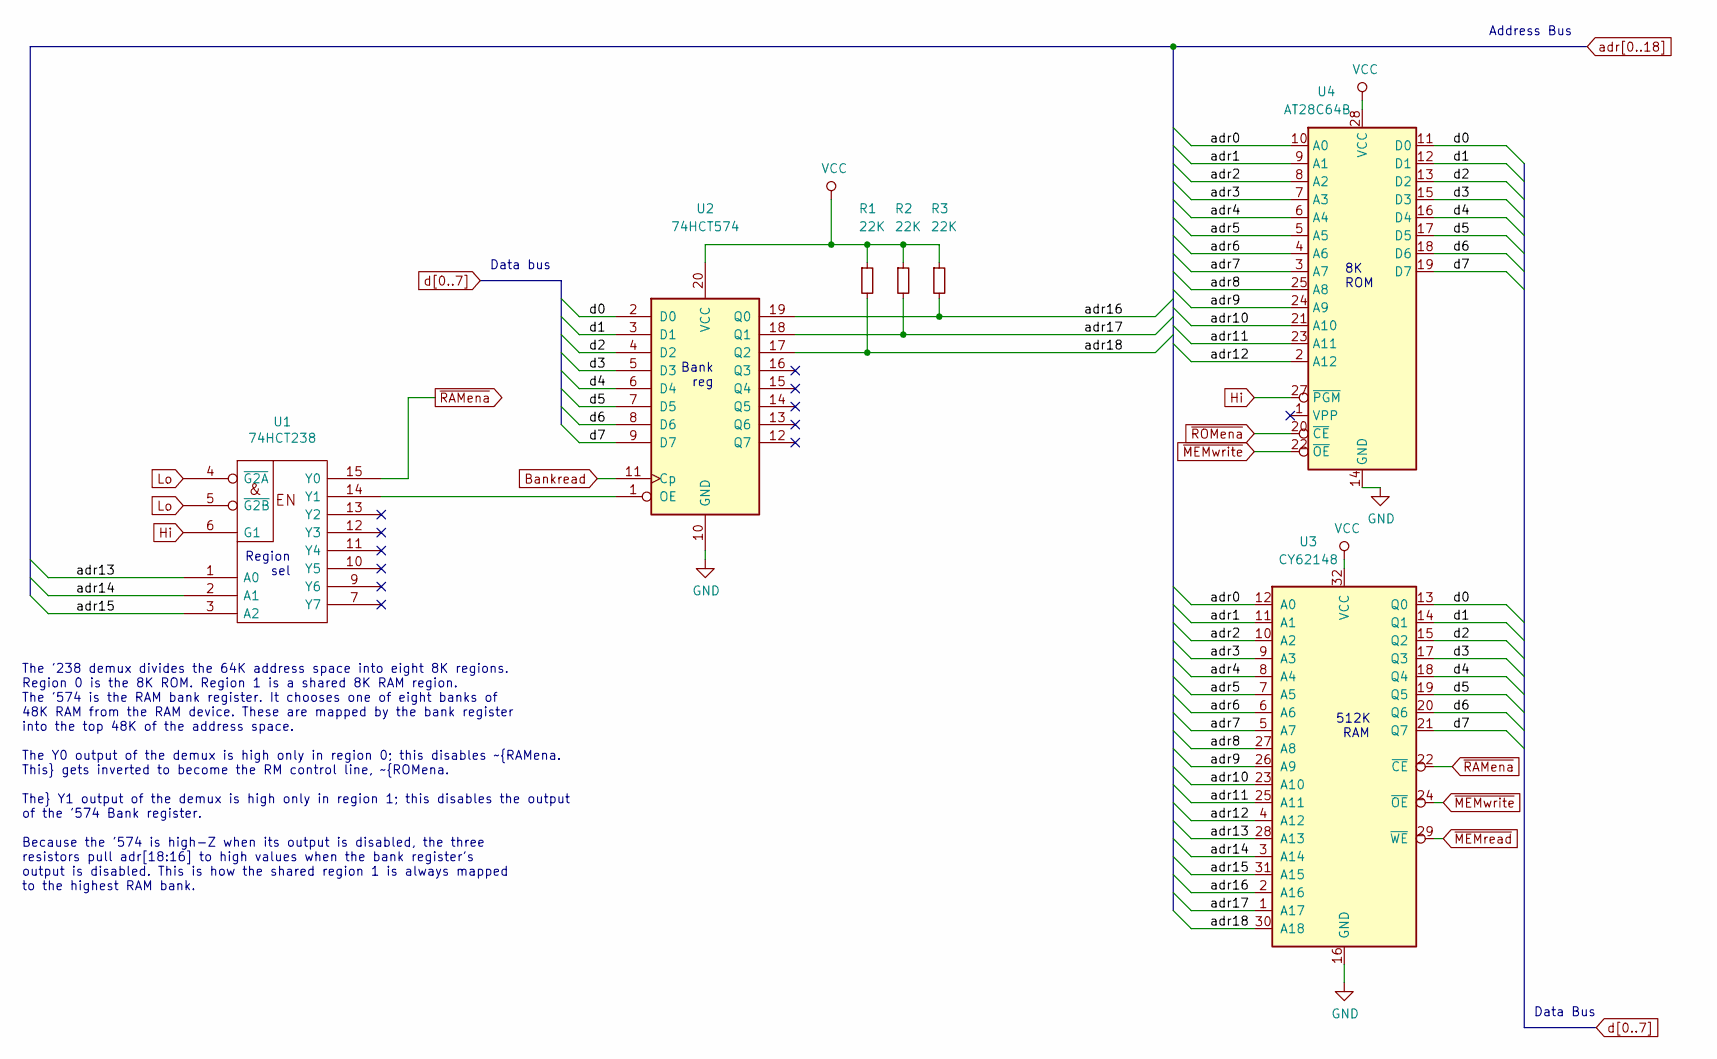
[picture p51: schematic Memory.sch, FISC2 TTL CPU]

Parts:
R1, R2, R3: 22K; R_0603_1608Metric_Pad1.05x0.95mm_HandSolder
U1: 74HCT238; SOIC-16_3.9x9.9mm_P1.27mm
U2: 74HCT574; SOIC-20W_7.5x12.8mm_P1.27mm
U3: CY62148; SOIC-32_11.2mm_P1.27mm
U4: AT28C64B; DIP-28_W15.24mm

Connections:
Bankread: U2.11 (Cp); also elsewhere on the board
Hi: R1.1, R2.1, R3.1, U1.6 (G1), U1.16 (VCC), U2.20 (VCC), U3.32 (VCC), U4.27 (~PGM), U4.28 (VCC); also elsewhere on the board
Lo: U1.4 (~G2A), U1.5 (~G2B), U1.8 (GND), U2.10 (GND), U3.16 (GND), U4.14 (GND); also elsewhere on the board
NNNZout: U2.8 (D6), U3.20 (Q6), U4.18 (D6); also elsewhere on the board
unnamed: U1.14 (Y1), U2.1 (OE)
NorZout: U2.6 (D4), U3.18 (Q4), U4.16 (D4); also elsewhere on the board
NotZout: U2.5 (D3), U3.17 (Q3), U4.15 (D3); also elsewhere on the board
Nout: U2.4 (D2), U3.15 (Q2), U4.13 (D2); also elsewhere on the board
ZNNout: U2.7 (D5), U3.19 (Q5), U4.17 (D5); also elsewhere on the board
Zout: U2.3 (D1), U3.14 (Q1), U4.12 (D1); also elsewhere on the board
adr0: U3.12 (A0), U4.10 (A0); also elsewhere on the board
adr1: U3.11 (A1), U4.9 (A1); also elsewhere on the board
adr2: U3.10 (A2), U4.8 (A2); also elsewhere on the board
adr3: U3.9 (A3), U4.7 (A3); also elsewhere on the board
adr4: U3.8 (A4), U4.6 (A4); also elsewhere on the board
adr5: U3.7 (A5), U4.5 (A5); also elsewhere on the board
adr6: U3.6 (A6), U4.4 (A6); also elsewhere on the board
adr7: U3.5 (A7), U4.3 (A7); also elsewhere on the board
adr8: U3.27 (A8), U4.25 (A8); also elsewhere on the board
adr9: U3.26 (A9), U4.24 (A9); also elsewhere on the board
adr10: U3.23 (A10), U4.21 (A10); also elsewhere on the board
adr11: U3.25 (A11), U4.23 (A11); also elsewhere on the board
adr12: U3.4 (A12), U4.2 (A12); also elsewhere on the board
adr13: U1.1 (A0), U3.28 (A13); also elsewhere on the board
adr14: U1.2 (A1), U3.3 (A14); also elsewhere on the board
adr15: U1.3 (A2), U3.31 (A15); also elsewhere on the board
adr16: R3.2, U2.19 (Q0), U3.2 (A16)
adr17: R2.2, U2.18 (Q1), U3.1 (A17)
adr18: R1.2, U2.17 (Q2), U3.30 (A18)
d0: U2.2 (D0), U3.13 (Q0), U4.11 (D0); also elsewhere on the board
d7: U2.9 (D7), U3.21 (Q7), U4.19 (D7); also elsewhere on the board
~MEMread: U3.29 (~WE); also elsewhere on the board
~MEMwrite: U3.24 (~OE), U4.22 (~OE); also elsewhere on the board
~RAMena: U1.15 (Y0), U3.22 (~CE); also elsewhere on the board
~ROMena: U4.20 (~CE); also elsewhere on the board

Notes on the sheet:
512K RAM
8K ROM
Address Bus
Data Bus
Data bus
The '238 demux divides the 64K address space into eight 8K regions. Region 0 is the 8K ROM. Region 1 is a shared 8K RAM region. The '574 is the RAM bank register. It chooses one of eight banks of 48K RAM from the RAM device. These are mapped by the bank register into the top 48K of the address spac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
Bank reg
Region sel

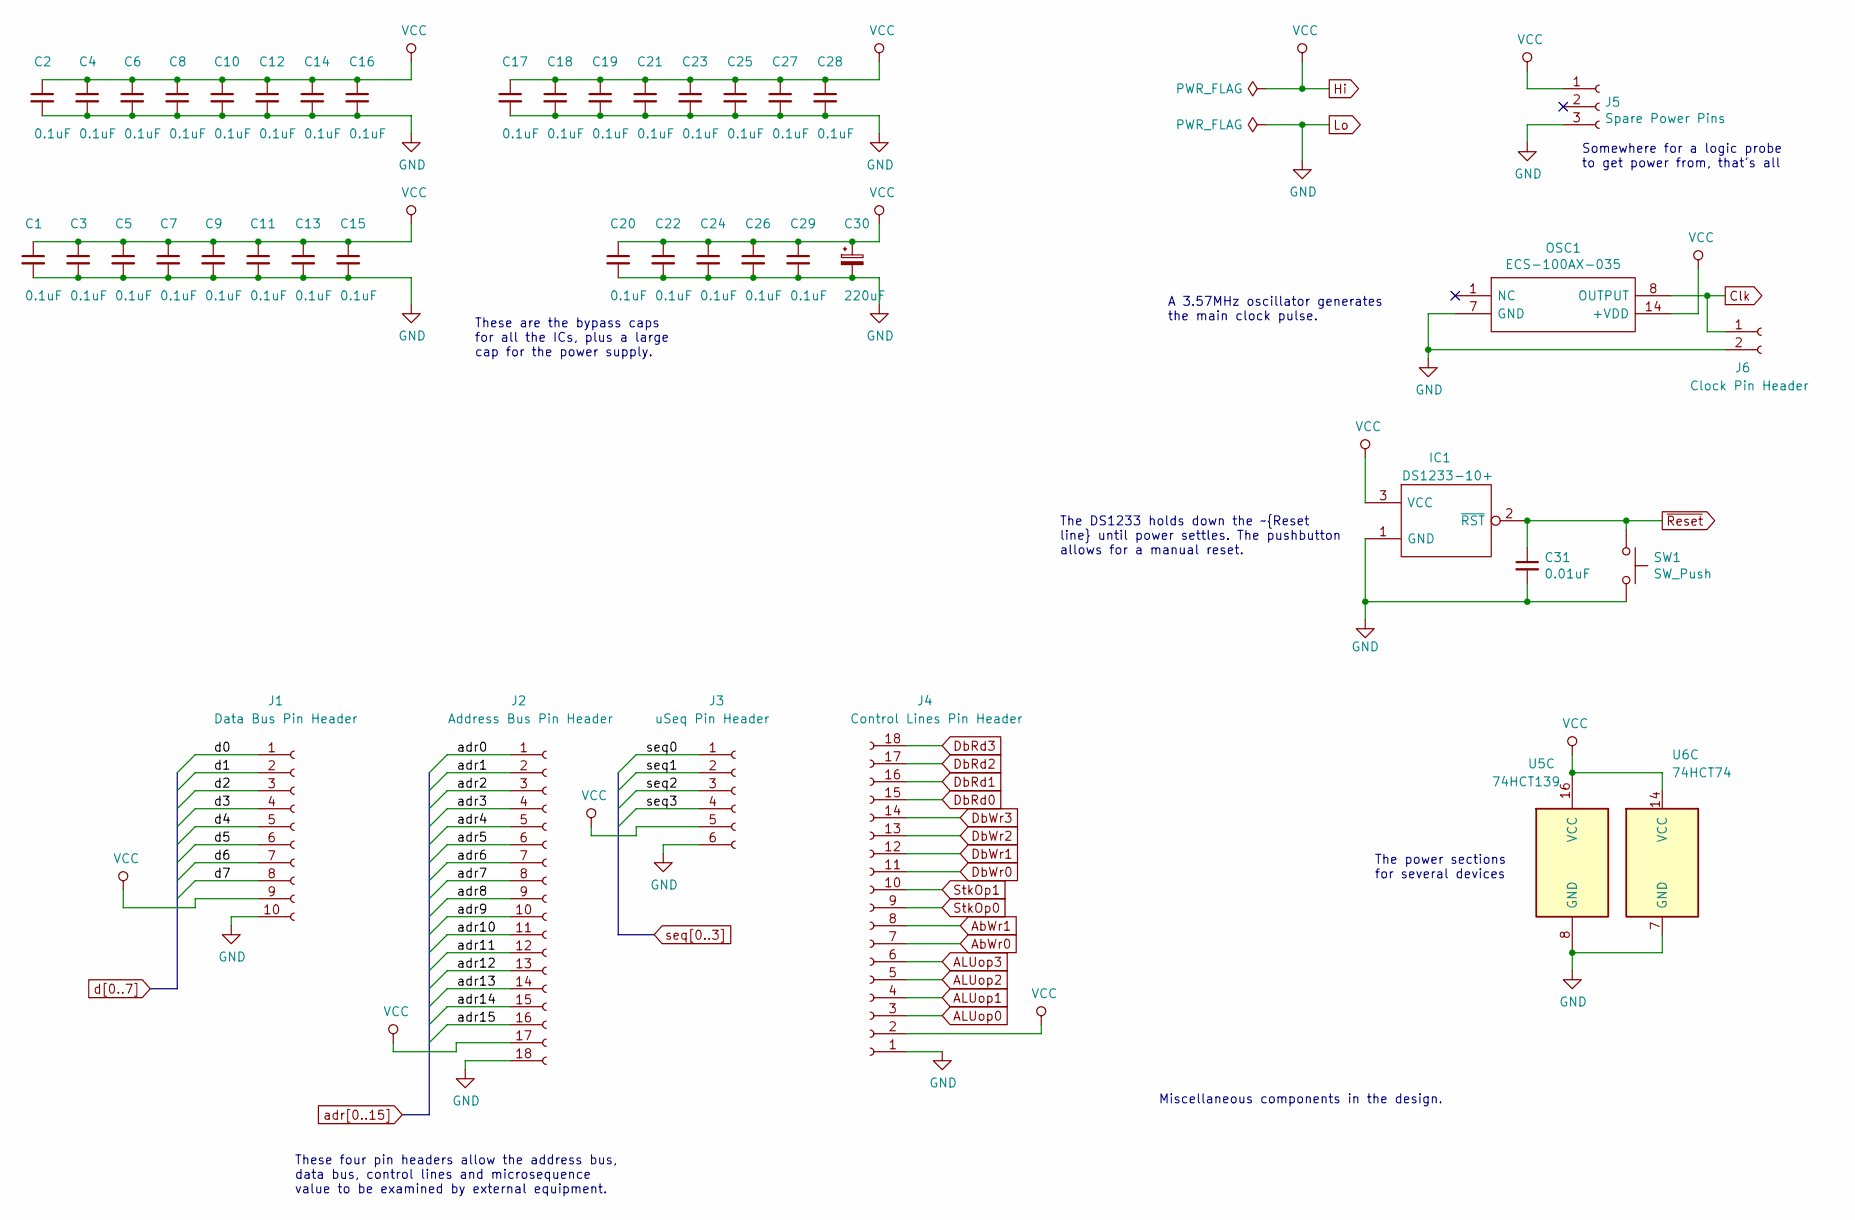
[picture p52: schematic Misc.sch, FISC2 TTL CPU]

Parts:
C1, C2, C3, C4, C5, C6, C7, C8, C9, C10, C11, C12, C13, C14, C15, C16, C17, C18, C19, C20, C21, C22, C23, C24, C25, C26, C27, C28, C29: 0.1uF; C_0603_1608Metric_Pad1.05x0.95mm_HandSolder
C30: 220uF; CP_Radial_D8.0mm_P5.00mm
C31: 0.01uF; C_0603_1608Metric_Pad1.05x0.95mm_HandSolder
IC1: DS1233-10+; TO-92; Manufacturer_Part_Number DS1233-10+; Mouser Part Number 700-DS1233-10
J1: Data Bus Pin Header; PinSocket_1x10_P2.54mm_Vertical
J2: Address Bus Pin Header; PinSocket_1x18_P2.54mm_Vertical
J3: uSeq Pin Header; PinSocket_1x06_P2.54mm_Vertical
J4: Control Lines Pin Header; PinSocket_1x18_P2.54mm_Vertical
J5: Spare Power Pins; PinSocket_1x03_P2.54mm_Vertical
J6: Clock Pin Header; PinSocket_1x02_P2.54mm_Vertical
OSC1: ECS-100AX-035; Oscillator_DIP-14; Manufacturer_Part_Number QX14T50B1.843200B50TT
SW1: SW_Push; Push_E-Switch_KS01Q01
U5: 74HCT139; SOIC-16_3.9x9.9mm_P1.27mm
U6: 74HCT74; SOIC-14_3.9x8.7mm_P1.27mm

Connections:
ALUop0: J4.3; also elsewhere on the board
ALUop1: J4.4; also elsewhere on the board
ALUop2: J4.5; also elsewhere on the board
ALUop3: J4.6; also elsewhere on the board
AbWr0: J4.7; also elsewhere on the board
AbWr1: J4.8; also elsewhere on the board
Clk: J6.1, OSC1.8 (OUTPUT); also elsewhere on the board
DbRd0: J4.15; also elsewhere on the board
DbRd1: J4.16; also elsewhere on the board
DbRd2: J4.17; also elsewhere on the board
DbRd3: J4.18; also elsewhere on the board
DbWr0: J4.11; also elsewhere on the board
DbWr1: J4.12; also elsewhere on the board
DbWr2: J4.13; also elsewhere on the board
DbWr3: J4.14; also elsewhere on the board
Hi: C1.1, C2.1, C3.1, C4.1, C5.1, C6.1, C7.1, C8.1, C9.1, C10.1, C11.1, C12.1, C13.1, C14.1, C15.1, C16.1, C17.1, C18.1, C19.1, C20.1, C21.1, C22.1, C23.1, C24.1, C25.1, C26.1, C27.1, C28.1, C29.1, C30.1, IC1.3 (VCC), J1.9, J2.17, J3.5, J4.2, J5.1, OSC1.14 (+VDD), U5.16 (VCC), U6.14 (VCC); also elsewhere on the board
Lo: C1.2, C2.2, C3.2, C4.2, C5.2, C6.2, C7.2, C8.2, C9.2, C10.2, C11.2, C12.2, C13.2, C14.2, C15.2, C16.2, C17.2, C18.2, C19.2, C20.2, C21.2, C22.2, C23.2, C24.2, C25.2, C26.2, C27.2, C28.2, C29.2, C30.2, C31.2, IC1.1 (GND), J1.10, J2.18, J3.6, J4.1, J5.3, J6.2, OSC1.7 (GND), SW1.2, U5.8 (GND), U6.7 (GND); also elsewhere on the board
NNNZout: J1.7; also elsewhere on the board
NorZout: J1.5; also elsewhere on the board
NotZout: J1.4; also elsewhere on the board
Nout: J1.3; also elsewhere on the board
StkOp0: J4.9; also elsewhere on the board
StkOp1: J4.10; also elsewhere on the board
ZNNout: J1.6; also elsewhere on the board
Zout: J1.2; also elsewhere on the board
adr0: J2.1; also elsewhere on the board
adr1: J2.2; also elsewhere on the board
adr2: J2.3; also elsewhere on the board
adr3: J2.4; also elsewhere on the board
adr4: J2.5; also elsewhere on the board
adr5: J2.6; also elsewhere on the board
adr6: J2.7; also elsewhere on the board
adr7: J2.8; also elsewhere on the board
adr8: J2.9; also elsewhere on the board
adr9: J2.10; also elsewhere on the board
adr10: J2.11; also elsewhere on the board
adr11: J2.12; also elsewhere on the board
adr12: J2.13; also elsewhere on the board
adr13: J2.14; also elsewhere on the board
adr14: J2.15; also elsewhere on the board
adr15: J2.16; also elsewhere on the board
d0: J1.1; also elsewhere on the board
d7: J1.8; also elsewhere on the board
seq0: J3.1; also elsewhere on the board
seq1: J3.2; also elsewhere on the board
seq2: J3.3; also elsewhere on the board
seq3: J3.4; also elsewhere on the board
~Reset: C31.1, IC1.2 (~RST), SW1.1; also elsewhere on the board

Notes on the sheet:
A 3.57MHz oscillator generates the main clock pulse.
The DS1233 holds down the ~Reset line until power settles. The pushbutton allows for a manual reset.
The power sections for several devices
These are the bypass caps for all the ICs, plus a large cap for the power supply.
These four pin headers allow the address bus, data bus, control lines and microsequence value to be examined by external equipment.
Miscellaneous components in the design.
Somewhere for a logic probe to get power from, that's all

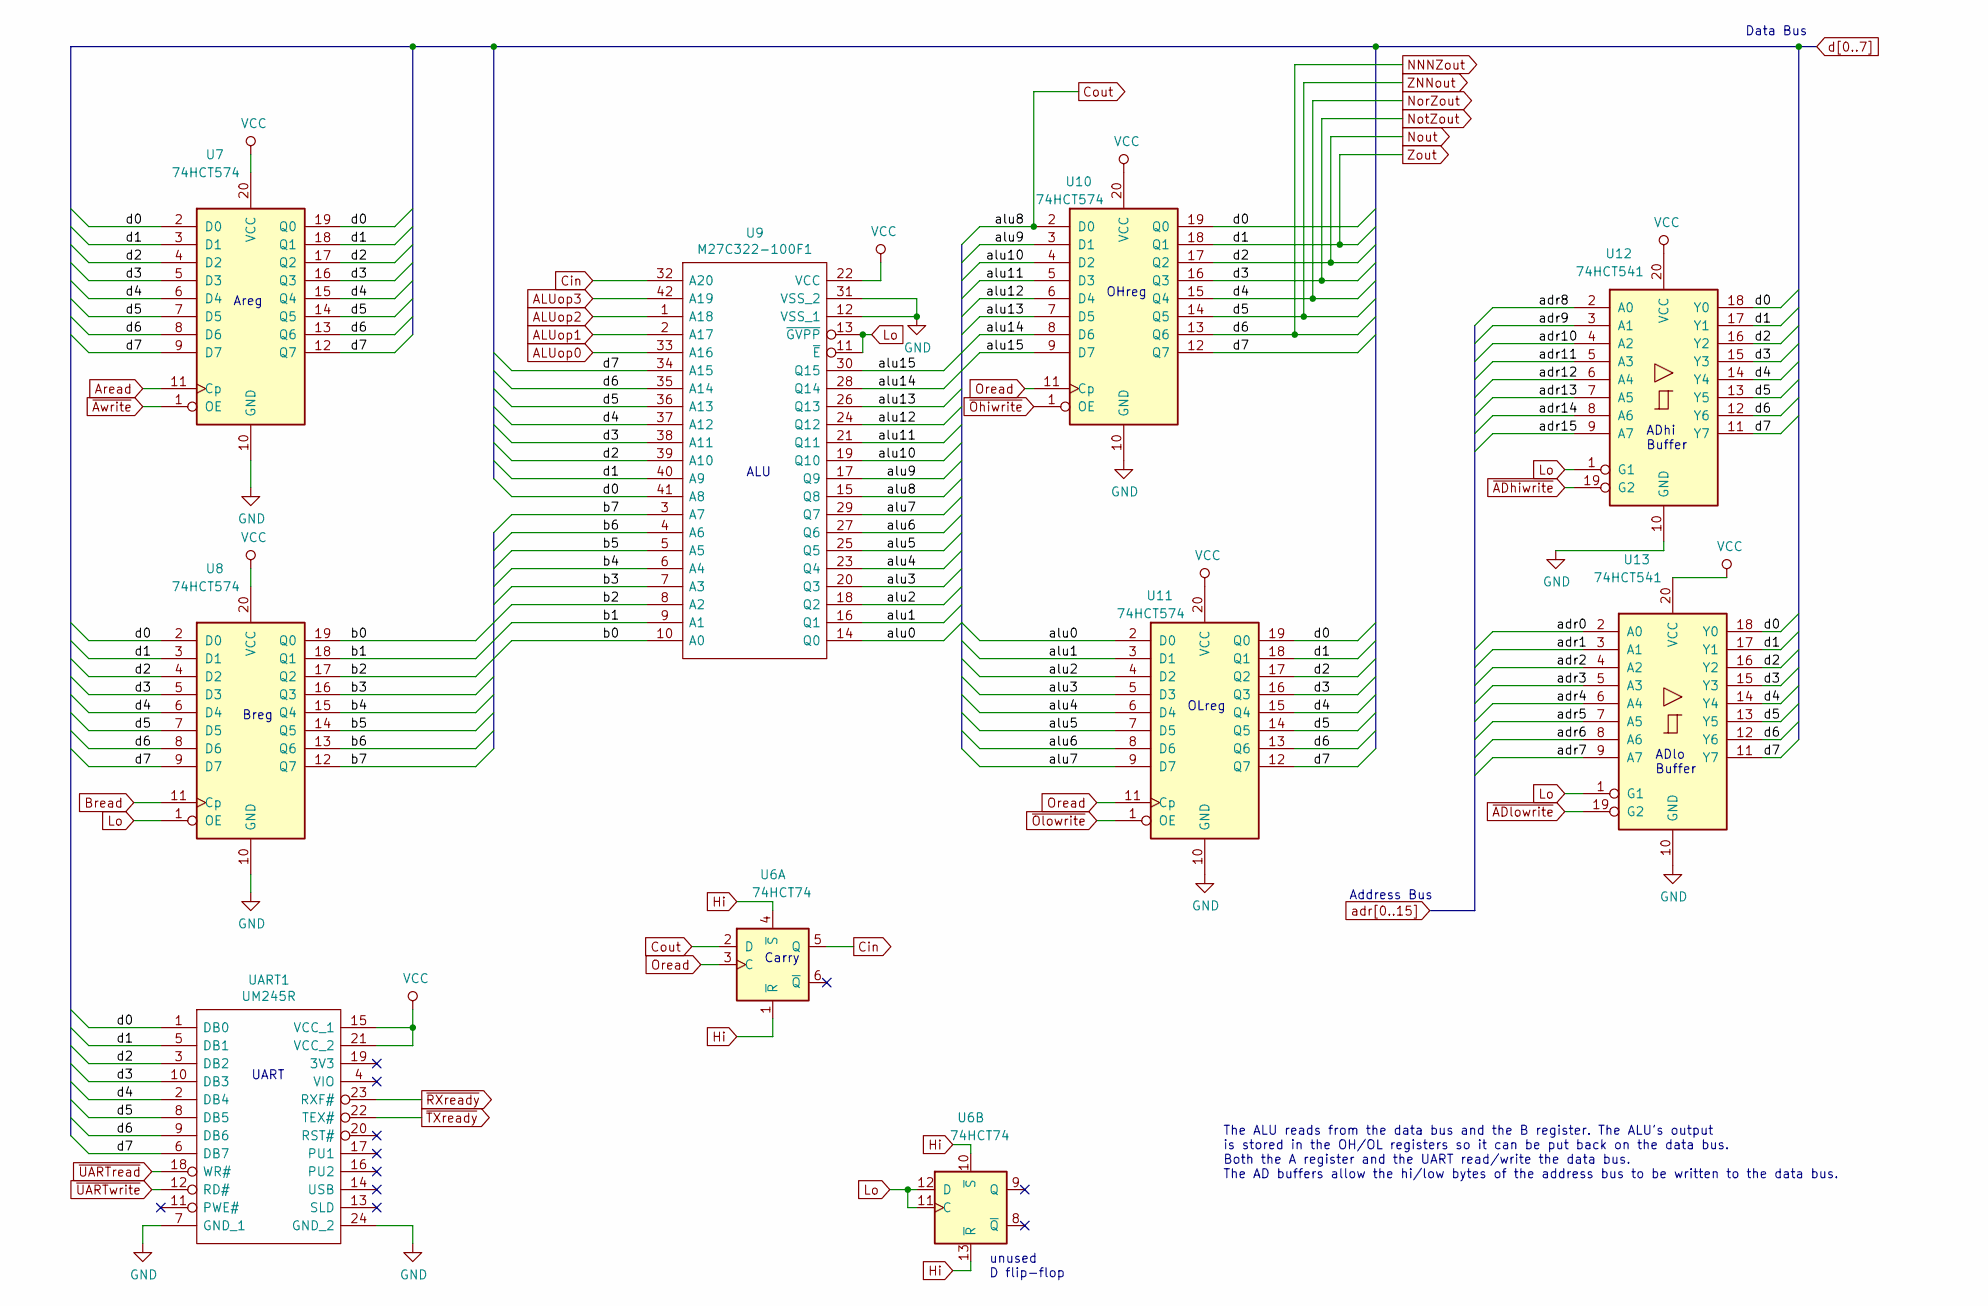
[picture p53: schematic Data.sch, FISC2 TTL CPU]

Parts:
U6: 74HCT74; SOIC-14_3.9x8.7mm_P1.27mm
U7, U8, U10, U11: 74HCT574; SOIC-20W_7.5x12.8mm_P1.27mm
U9: M27C322-100F1; DIP-42_W15.24mm; Manufacturer_Part_Number M27C322-100F1; Mouser Part Number 511-M27C322-10F
U12, U13: 74HCT541; SOIC-20W_7.5x12.8mm_P1.27mm
UART1: UM245R; DIP-24_W15.24mm_Socket; Manufacturer_Part_Number UM245R; Mouser Part Number 895-UM245R

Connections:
/Data/alu0: U9.14 (Q0), U11.2 (D0)
/Data/alu1: U9.16 (Q1), U11.3 (D1)
/Data/alu2: U9.18 (Q2), U11.4 (D2)
/Data/alu3: U9.20 (Q3), U11.5 (D3)
/Data/alu4: U9.23 (Q4), U11.6 (D4)
/Data/alu5: U9.25 (Q5), U11.7 (D5)
/Data/alu6: U9.27 (Q6), U11.8 (D6)
/Data/alu7: U9.29 (Q7), U11.9 (D7)
/Data/alu9: U9.17 (Q9), U10.3 (D1)
/Data/alu10: U9.19 (Q10), U10.4 (D2)
/Data/alu11: U9.21 (Q11), U10.5 (D3)
/Data/alu12: U9.24 (Q12), U10.6 (D4)
/Data/alu13: U9.26 (Q13), U10.7 (D5)
/Data/alu14: U9.28 (Q14), U10.8 (D6)
/Data/alu15: U9.30 (Q15), U10.9 (D7)
/Data/b0: U8.19 (Q0), U9.10 (A0)
/Data/b1: U8.18 (Q1), U9.9 (A1)
/Data/b2: U8.17 (Q2), U9.8 (A2)
/Data/b3: U8.16 (Q3), U9.7 (A3)
/Data/b4: U8.15 (Q4), U9.6 (A4)
/Data/b5: U8.14 (Q5), U9.5 (A5)
/Data/b6: U8.13 (Q6), U9.4 (A6)
/Data/b7: U8.12 (Q7), U9.3 (A7)
ALUop0: U9.33 (A16); also elsewhere on the board
ALUop1: U9.2 (A17); also elsewhere on the board
ALUop2: U9.1 (A18); also elsewhere on the board
ALUop3: U9.42 (A19); also elsewhere on the board
Aread: U7.11 (Cp); also elsewhere on the board
Bread: U8.11 (Cp); also elsewhere on the board
Cin: U6.5 (Q), U9.32 (A20)
Cout: U6.2 (D), U9.15 (Q8), U10.2 (D0)
Hi: U6.1 (~R), U6.4 (~S), U6.10 (~S), U6.13 (~R), U7.20 (VCC), U8.20 (VCC), U9.22 (VCC), U10.20 (VCC), U11.20 (VCC), U12.20 (VCC), U13.20 (VCC), UART1.15 (VCC_1), UART1.21 (VCC_2); also elsewhere on the board
Lo: U6.11 (C), U6.12 (D), U7.10 (GND), U8.1 (OE), U8.10 (GND), U9.11 (~E), U9.12 (VSS_1), U9.13 (~GVPP), U9.31 (VSS_2), U10.10 (GND), U11.10 (GND), U12.1 (G1), U12.10 (GND), U13.1 (G1), U13.10 (GND), UART1.7 (GND_1), UART1.24 (GND_2); also elsewhere on the board
NNNZout: U7.8 (D6), U7.13 (Q6), U8.8 (D6), U9.35 (A14), U10.13 (Q6), U11.13 (Q6), U12.12 (Y6), U13.12 (Y6), UART1.9 (DB6); also elsewhere on the board
NorZout: U7.6 (D4), U7.15 (Q4), U8.6 (D4), U9.37 (A12), U10.15 (Q4), U11.15 (Q4), U12.14 (Y4), U13.14 (Y4), UART1.2 (DB4); also elsewhere on the board
NotZout: U7.5 (D3), U7.16 (Q3), U8.5 (D3), U9.38 (A11), U10.16 (Q3), U11.16 (Q3), U12.15 (Y3), U13.15 (Y3), UART1.10 (DB3); also elsewhere on the board
Nout: U7.4 (D2), U7.17 (Q2), U8.4 (D2), U9.39 (A10), U10.17 (Q2), U11.17 (Q2), U12.16 (Y2), U13.16 (Y2), UART1.3 (DB2); also elsewhere on the board
Oread: U6.3 (C), U10.11 (Cp), U11.11 (Cp); also elsewhere on the board
ZNNout: U7.7 (D5), U7.14 (Q5), U8.7 (D5), U9.36 (A13), U10.14 (Q5), U11.14 (Q5), U12.13 (Y5), U13.13 (Y5), UART1.8 (DB5); also elsewhere on the board
Zout: U7.3 (D1), U7.18 (Q1), U8.3 (D1), U9.40 (A9), U10.18 (Q1), U11.18 (Q1), U12.17 (Y1), U13.17 (Y1), UART1.5 (DB1); also elsewhere on the board
adr0: U13.2 (A0); also elsewhere on the board
adr1: U13.3 (A1); also elsewhere on the board
adr2: U13.4 (A2); also elsewhere on the board
adr3: U13.5 (A3); also elsewhere on the board
adr4: U13.6 (A4); also elsewhere on the board
adr5: U13.7 (A5); also elsewhere on the board
adr6: U13.8 (A6); also elsewhere on the board
adr7: U13.9 (A7); also elsewhere on the board
adr8: U12.2 (A0); also elsewhere on the board
adr9: U12.3 (A1); also elsewhere on the board
adr10: U12.4 (A2); also elsewhere on the board
adr11: U12.5 (A3); also elsewhere on the board
adr12: U12.6 (A4); also elsewhere on the board
adr13: U12.7 (A5); also elsewhere on the board
adr14: U12.8 (A6); also elsewhere on the board
adr15: U12.9 (A7); also elsewhere on the board
d0: U7.2 (D0), U7.19 (Q0), U8.2 (D0), U9.41 (A8), U10.19 (Q0), U11.19 (Q0), U12.18 (Y0), U13.18 (Y0), UART1.1 (DB0); also elsewhere on the board
d7: U7.9 (D7), U7.12 (Q7), U8.9 (D7), U9.34 (A15), U10.12 (Q7), U11.12 (Q7), U12.11 (Y7), U13.11 (Y7), UART1.6 (DB7); also elsewhere on the board
~ADhiwrite: U12.19 (G2); also elsewhere on the board
~ADlowrite: U13.19 (G2); also elsewhere on the board
~Awrite: U7.1 (OE); also elsewhere on the board
~Ohiwrite: U10.1 (OE); also elsewhere on the board
~Olowrite: U11.1 (OE); also elsewhere on the board
~RXready: UART1.23 (RXF#); also elsewhere on the board
~TXready: UART1.22 (TEX#); also elsewhere on the board
~UARTread: UART1.18 (WR#); also elsewhere on the board
~UARTwrite: UART1.12 (RD#); also elsewhere on the board

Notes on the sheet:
Areg
Carry
UART
OLreg
ALU
Breg
ADhi Buffer
ADlo Buffer
Data Bus
Address Bus
The ALU reads from the data bus and the B register. The ALU's output is stored in the OH/OL registers so it can be put back on the data bus. Both the A register and the UART read/write the data bus. The AD buffers allow the hi/low bytes of the address bus to be written to the data bus.
OHreg
unused D flip-flop

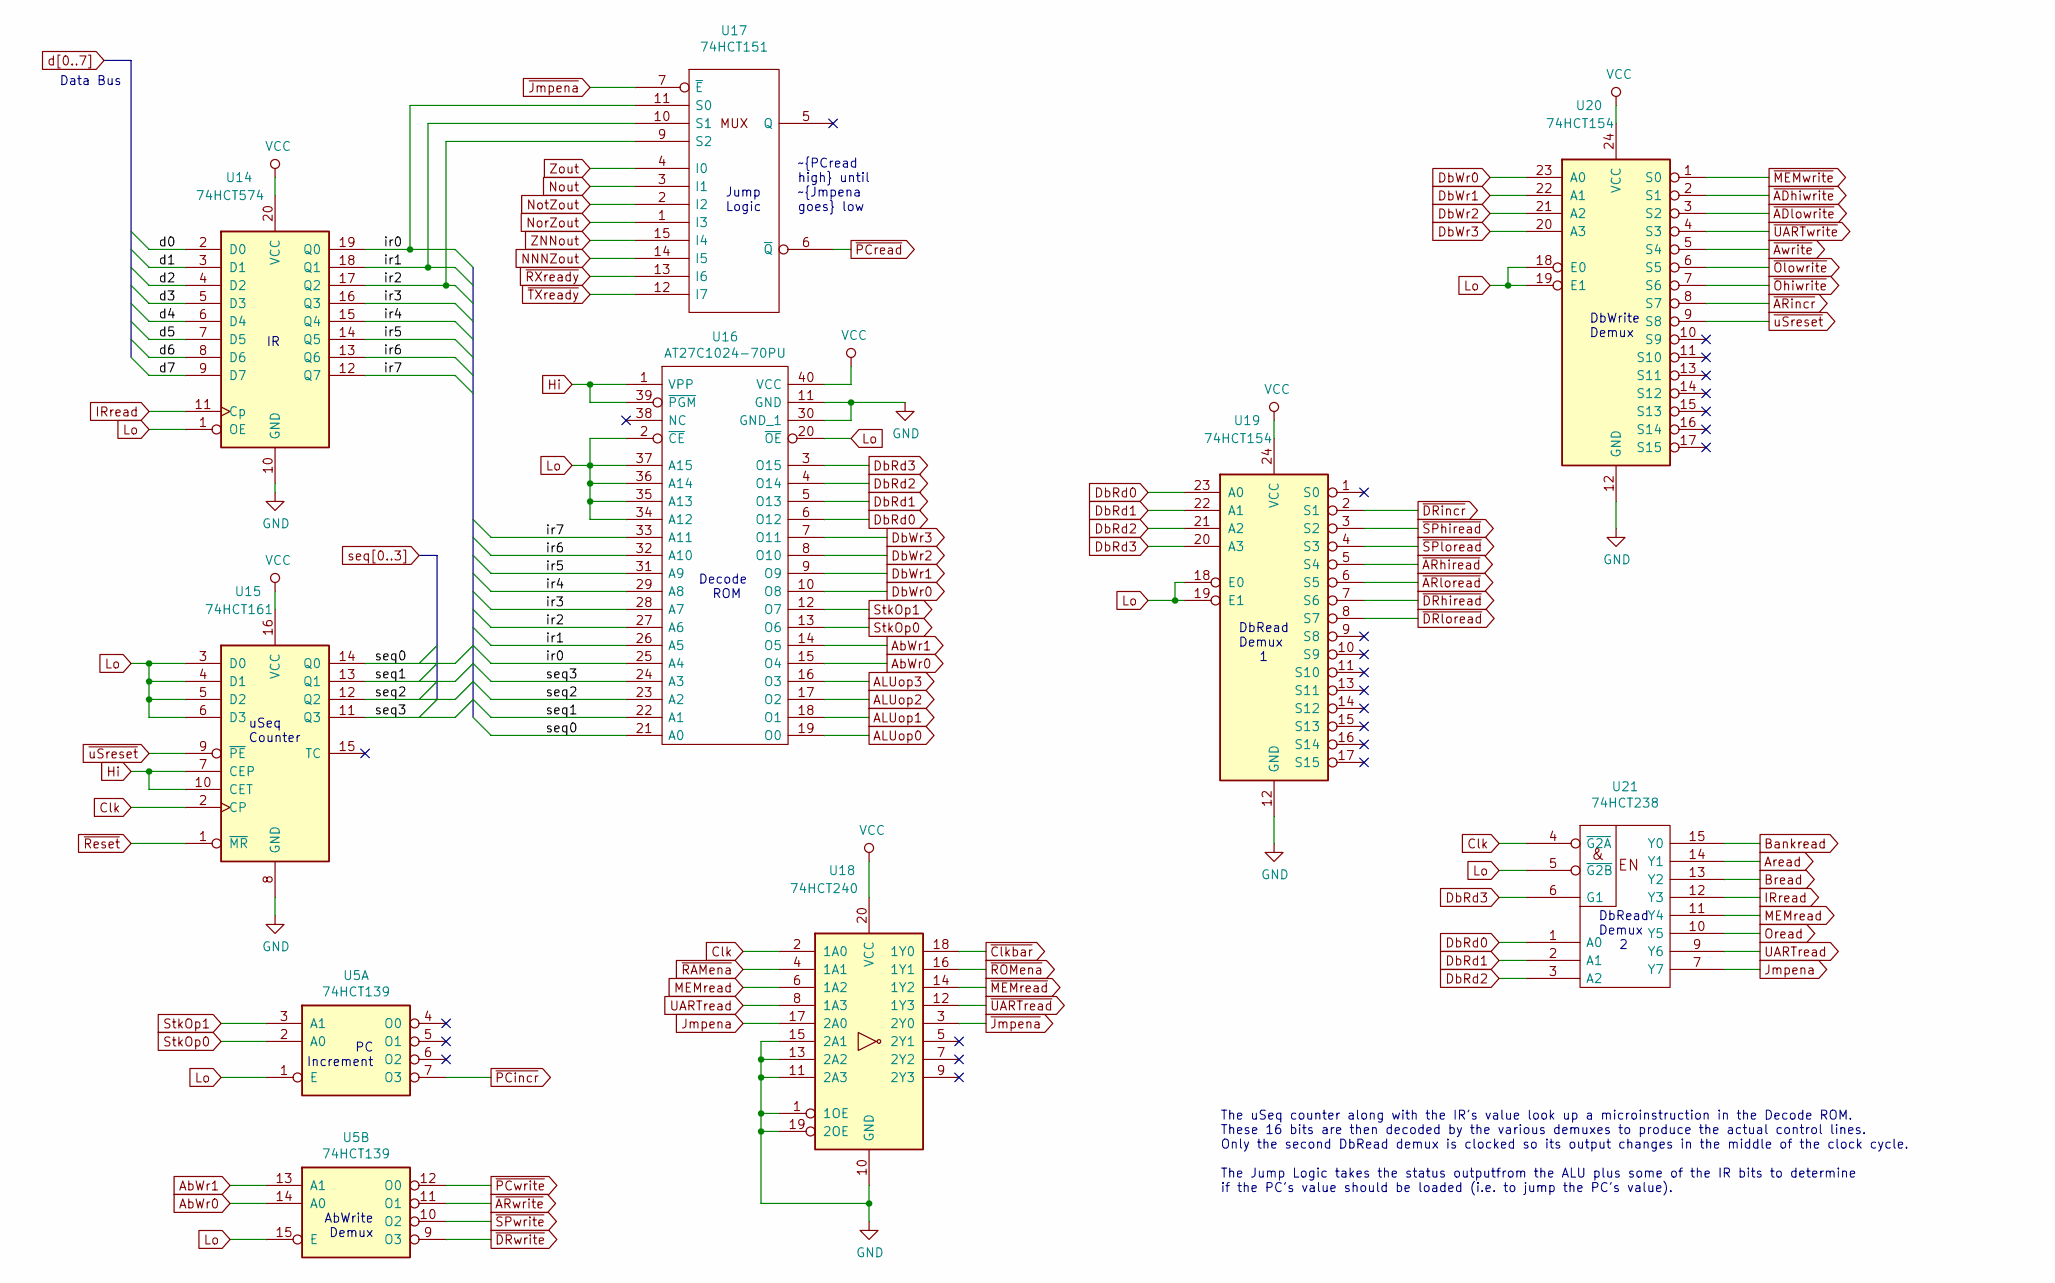
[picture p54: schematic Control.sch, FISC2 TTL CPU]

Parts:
U5: 74HCT139; SOIC-16_3.9x9.9mm_P1.27mm
U14: 74HCT574; SOIC-20W_7.5x12.8mm_P1.27mm
U15: 74HCT161; SOIC-16_3.9x9.9mm_P1.27mm
U16: AT27C1024-70PU; DIP-40_W15.24mm; Manufacturer_Part_Number AT27C1024-70PU; Mouser Part Number 556-AT27C102470PU
U17: 74HCT151; SOIC-16_3.9x9.9mm_P1.27mm
U18: 74HCT240; SOIC-20W_7.5x12.8mm_P1.27mm
U19, U20: 74HCT154; SOIC-24W_7.5x15.4mm_P1.27mm
U21: 74HCT238; SOIC-16_3.9x9.9mm_P1.27mm

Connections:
/Control/ir0: U14.19 (Q0), U16.25 (A4), U17.11 (S0)
/Control/ir1: U14.18 (Q1), U16.26 (A5), U17.10 (S1)
/Control/ir2: U14.17 (Q2), U16.27 (A6), U17.9 (S2)
/Control/ir3: U14.16 (Q3), U16.28 (A7)
/Control/ir4: U14.15 (Q4), U16.29 (A8)
/Control/ir5: U14.14 (Q5), U16.31 (A9)
/Control/ir6: U14.13 (Q6), U16.32 (A10)
/Control/ir7: U14.12 (Q7), U16.33 (A11)
ALUop0: U16.19 (O0); also elsewhere on the board
ALUop1: U16.18 (O1); also elsewhere on the board
ALUop2: U16.17 (O2); also elsewhere on the board
ALUop3: U16.16 (O3); also elsewhere on the board
AbWr0: U5.14 (A0), U16.15 (O4); also elsewhere on the board
AbWr1: U5.13 (A1), U16.14 (O5); also elsewhere on the board
Aread: U21.14 (Y1); also elsewhere on the board
Bankread: U21.15 (Y0); also elsewhere on the board
Bread: U21.13 (Y2); also elsewhere on the board
Clk: U15.2 (CP), U18.2 (1A0), U21.4 (~G2A); also elsewhere on the board
DbRd0: U16.6 (O12), U19.23 (A0), U21.1 (A0); also elsewhere on the board
DbRd1: U16.5 (O13), U19.22 (A1), U21.2 (A1); also elsewhere on the board
DbRd2: U16.4 (O14), U19.21 (A2), U21.3 (A2); also elsewhere on the board
DbRd3: U16.3 (O15), U19.20 (A3), U21.6 (G1); also elsewhere on the board
DbWr0: U16.10 (O8), U20.23 (A0); also elsewhere on the board
DbWr1: U16.9 (O9), U20.22 (A1); also elsewhere on the board
DbWr2: U16.8 (O10), U20.21 (A2); also elsewhere on the board
DbWr3: U16.7 (O11), U20.20 (A3); also elsewhere on the board
Hi: U14.20 (VCC), U15.7 (CEP), U15.10 (CET), U15.16 (VCC), U16.1 (VPP), U16.39 (~PGM), U16.40 (VCC), U17.16 (VCC), U18.20 (VCC), U19.24 (VCC), U20.24 (VCC), U21.16 (VCC); also elsewhere on the board
IRread: U14.11 (Cp), U21.12 (Y3)
Jmpena: U18.17 (2A0), U21.7 (Y7)
Lo: U5.1 (E), U5.15 (E), U14.1 (OE), U14.10 (GND), U15.3 (D0), U15.4 (D1), U15.5 (D2), U15.6 (D3), U15.8 (GND), U16.2 (~CE), U16.11 (GND), U16.20 (~OE), U16.30 (GND_1), U16.34 (A12), U16.35 (A13), U16.36 (A14), U16.37 (A15), U17.8 (GND), U18.1 (1OE), U18.10 (GND), U18.11 (2A3), U18.13 (2A2), U18.15 (2A1), U18.19 (2OE), U19.12 (GND), U19.18 (E0), U19.19 (E1), U20.12 (GND), U20.18 (E0), U20.19 (E1), U21.5 (~G2B), U21.8 (GND); also elsewhere on the board
MEMread: U18.6 (1A2), U21.11 (Y4)
NNNZout: U14.8 (D6), U17.14 (I5); also elsewhere on the board
NorZout: U14.6 (D4), U17.1 (I3); also elsewhere on the board
NotZout: U14.5 (D3), U17.2 (I2); also elsewhere on the board
Nout: U14.4 (D2), U17.3 (I1); also elsewhere on the board
Oread: U21.10 (Y5); also elsewhere on the board
StkOp0: U5.2 (A0), U16.13 (O6); also elsewhere on the board
StkOp1: U5.3 (A1), U16.12 (O7); also elsewhere on the board
UARTread: U18.8 (1A3), U21.9 (Y6)
ZNNout: U14.7 (D5), U17.15 (I4); also elsewhere on the board
Zout: U14.3 (D1), U17.4 (I0); also elsewhere on the board
d0: U14.2 (D0); also elsewhere on the board
d7: U14.9 (D7); also elsewhere on the board
seq0: U15.14 (Q0), U16.21 (A0); also elsewhere on the board
seq1: U15.13 (Q1), U16.22 (A1); also elsewhere on the board
seq2: U15.12 (Q2), U16.23 (A2); also elsewhere on the board
seq3: U15.11 (Q3), U16.24 (A3); also elsewhere on the board
~ADhiwrite: U20.2 (S1); also elsewhere on the board
~ADlowrite: U20.3 (S2); also elsewhere on the board
~ARhiread: U19.5 (S4); also elsewhere on the board
~ARincr: U20.8 (S7); also elsewhere on the board
~ARloread: U19.6 (S5); also elsewhere on the board
~ARwrite: U5.11 (O1); also elsewhere on the board
~Awrite: U20.5 (S4); also elsewhere on the board
~Clkbar: U18.18 (1Y0); also elsewhere on the board
~DRhiread: U19.7 (S6); also elsewhere on the board
~DRincr: U19.2 (S1); also elsewhere on the board
~DRloread: U19.8 (S7); also elsewhere on the board
~DRwrite: U5.9 (O3); also elsewhere on the board
~Jmpena: U17.7 (~E), U18.3 (2Y0)
~MEMread: U18.14 (1Y2); also elsewhere on the board
~MEMwrite: U20.1 (S0); also elsewhere on the board
~Ohiwrite: U20.7 (S6); also elsewhere on the board
~Olowrite: U20.6 (S5); also elsewhere on the board
~PCincr: U5.7 (O3); also elsewhere on the board
~PCread: U17.6 (~Q); also elsewhere on the board
~PCwrite: U5.12 (O0); also elsewhere on the board
~RAMena: U18.4 (1A1); also elsewhere on the board
~ROMena: U18.16 (1Y1); also elsewhere on the board
~RXready: U17.13 (I6); also elsewhere on the board
~Reset: U15.1 (~MR); also elsewhere on the board
~SPhiread: U19.3 (S2); also elsewhere on the board
~SPloread: U19.4 (S3); also elsewhere on the board
~SPwrite: U5.10 (O2); also elsewhere on the board
~TXready: U17.12 (I7); also elsewhere on the board
~UARTread: U18.12 (1Y3); also elsewhere on the board
~UARTwrite: U20.4 (S3); also elsewhere on the board
~uSreset: U15.9 (~PE), U20.9 (S8)

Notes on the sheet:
uSeq Counter
Decode ROM
Jump Logic
AbWrite Demux
DbRead Demux 1
Data Bus
~PCread high until ~Jmpena goes low
The uSeq counter along with the IR's value look up a microinstruction in the Decode ROM. These 16 bits are then decoded by the various demuxes to produce the actual control lines. Only the second DbRead demux is clocked so its output changes in the middle of the clock cycle. The Jump Logic takes th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
PC Increment
DbWrite Demux
DbRead Demux 2

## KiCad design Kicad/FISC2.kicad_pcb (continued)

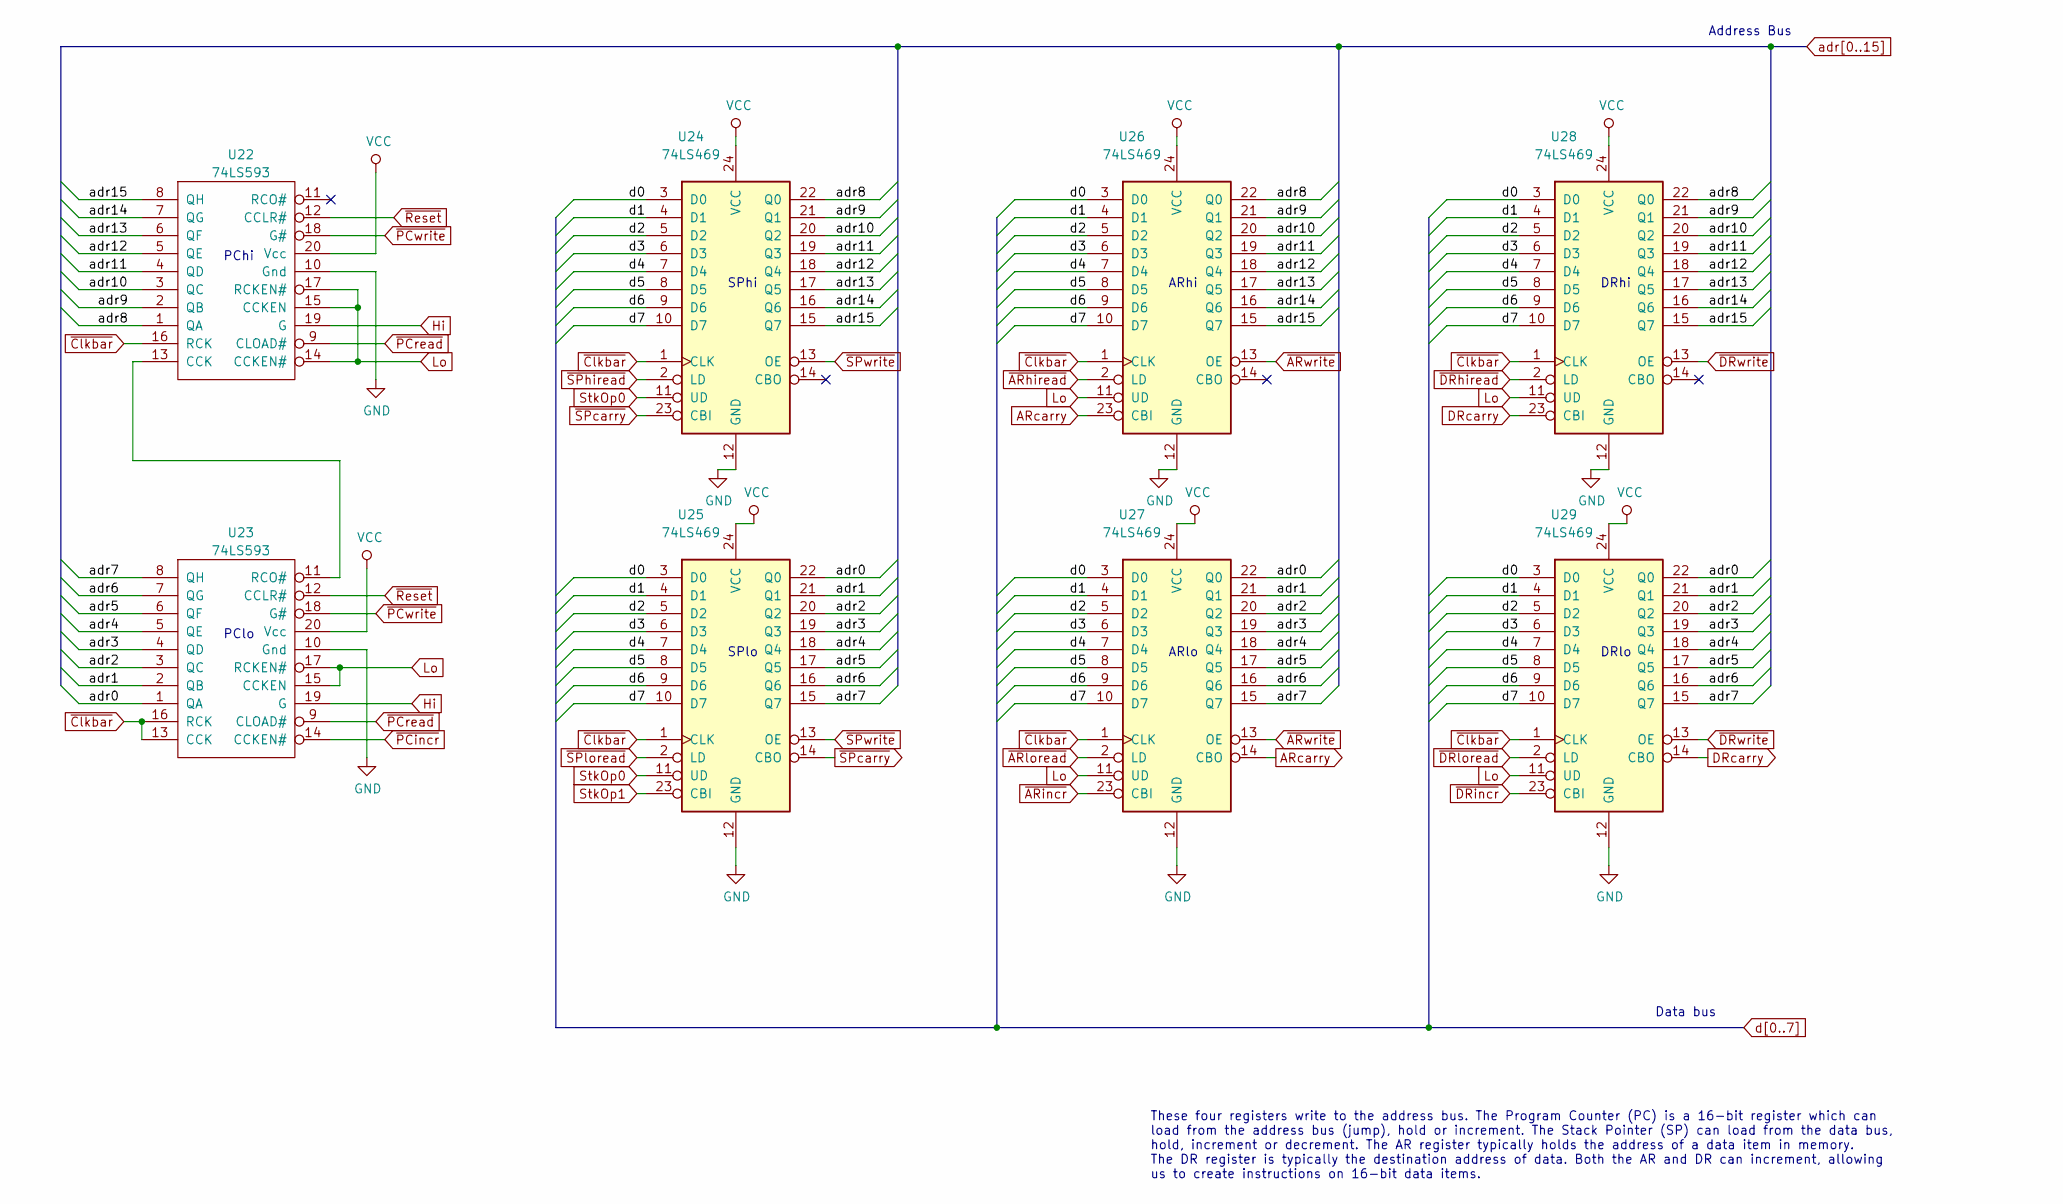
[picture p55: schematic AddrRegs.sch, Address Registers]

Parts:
U22, U23: 74LS593; SOIC-20W_7.5x12.8mm_P1.27mm
U24, U25, U26, U27, U28, U29: 74LS469; DIP-24_W7.62mm

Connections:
ARcarry: U26.23 (CBI), U27.14 (CBO)
DRcarry: U28.23 (CBI), U29.14 (CBO)
Hi: U22.19 (G), U22.20 (Vcc), U23.19 (G), U23.20 (Vcc), U24.24 (VCC), U25.24 (VCC), U26.24 (VCC), U27.24 (VCC), U28.24 (VCC), U29.24 (VCC); also elsewhere on the board
Lo: U22.10 (Gnd), U22.14 (CCKEN#), U22.15 (CCKEN), U22.17 (RCKEN#), U23.10 (Gnd), U23.15 (CCKEN), U23.17 (RCKEN#), U24.12 (GND), U25.12 (GND), U26.11 (UD), U26.12 (GND), U27.11 (UD), U27.12 (GND), U28.11 (UD), U28.12 (GND), U29.11 (UD), U29.12 (GND); also elsewhere on the board
NNNZout: U24.9 (D6), U25.9 (D6), U26.9 (D6), U27.9 (D6), U28.9 (D6), U29.9 (D6); also elsewhere on the board
unnamed: U22.13 (CCK), U23.11 (RCO#)
NorZout: U24.7 (D4), U25.7 (D4), U26.7 (D4), U27.7 (D4), U28.7 (D4), U29.7 (D4); also elsewhere on the board
NotZout: U24.6 (D3), U25.6 (D3), U26.6 (D3), U27.6 (D3), U28.6 (D3), U29.6 (D3); also elsewhere on the board
Nout: U24.5 (D2), U25.5 (D2), U26.5 (D2), U27.5 (D2), U28.5 (D2), U29.5 (D2); also elsewhere on the board
StkOp0: U24.11 (UD), U25.11 (UD); also elsewhere on the board
StkOp1: U25.23 (CBI); also elsewhere on the board
ZNNout: U24.8 (D5), U25.8 (D5), U26.8 (D5), U27.8 (D5), U28.8 (D5), U29.8 (D5); also elsewhere on the board
Zout: U24.4 (D1), U25.4 (D1), U26.4 (D1), U27.4 (D1), U28.4 (D1), U29.4 (D1); also elsewhere on the board
adr0: U23.1 (QA), U25.22 (Q0), U27.22 (Q0), U29.22 (Q0); also elsewhere on the board
adr1: U23.2 (QB), U25.21 (Q1), U27.21 (Q1), U29.21 (Q1); also elsewhere on the board
adr2: U23.3 (QC), U25.20 (Q2), U27.20 (Q2), U29.20 (Q2); also elsewhere on the board
adr3: U23.4 (QD), U25.19 (Q3), U27.19 (Q3), U29.19 (Q3); also elsewhere on the board
adr4: U23.5 (QE), U25.18 (Q4), U27.18 (Q4), U29.18 (Q4); also elsewhere on the board
adr5: U23.6 (QF), U25.17 (Q5), U27.17 (Q5), U29.17 (Q5); also elsewhere on the board
adr6: U23.7 (QG), U25.16 (Q6), U27.16 (Q6), U29.16 (Q6); also elsewhere on the board
adr7: U23.8 (QH), U25.15 (Q7), U27.15 (Q7), U29.15 (Q7); also elsewhere on the board
adr8: U22.1 (QA), U24.22 (Q0), U26.22 (Q0), U28.22 (Q0); also elsewhere on the board
adr9: U22.2 (QB), U24.21 (Q1), U26.21 (Q1), U28.21 (Q1); also elsewhere on the board
adr10: U22.3 (QC), U24.20 (Q2), U26.20 (Q2), U28.20 (Q2); also elsewhere on the board
adr11: U22.4 (QD), U24.19 (Q3), U26.19 (Q3), U28.19 (Q3); also elsewhere on the board
adr12: U22.5 (QE), U24.18 (Q4), U26.18 (Q4), U28.18 (Q4); also elsewhere on the board
adr13: U22.6 (QF), U24.17 (Q5), U26.17 (Q5), U28.17 (Q5); also elsewhere on the board
adr14: U22.7 (QG), U24.16 (Q6), U26.16 (Q6), U28.16 (Q6); also elsewhere on the board
adr15: U22.8 (QH), U24.15 (Q7), U26.15 (Q7), U28.15 (Q7); also elsewhere on the board
d0: U24.3 (D0), U25.3 (D0), U26.3 (D0), U27.3 (D0), U28.3 (D0), U29.3 (D0); also elsewhere on the board
d7: U24.10 (D7), U25.10 (D7), U26.10 (D7), U27.10 (D7), U28.10 (D7), U29.10 (D7); also elsewhere on the board
~ARhiread: U26.2 (LD); also elsewhere on the board
~ARincr: U27.23 (CBI); also elsewhere on the board
~ARloread: U27.2 (LD); also elsewhere on the board
~ARwrite: U26.13 (OE), U27.13 (OE); also elsewhere on the board
~Clkbar: U22.16 (RCK), U23.13 (CCK), U23.16 (RCK), U24.1 (CLK), U25.1 (CLK), U26.1 (CLK), U27.1 (CLK), U28.1 (CLK), U29.1 (CLK); also elsewhere on the board
~DRhiread: U28.2 (LD); also elsewhere on the board
~DRincr: U29.23 (CBI); also elsewhere on the board
~DRloread: U29.2 (LD); also elsewhere on the board
~DRwrite: U28.13 (OE), U29.13 (OE); also elsewhere on the board
~PCincr: U23.14 (CCKEN#); also elsewhere on the board
~PCread: U22.9 (CLOAD#), U23.9 (CLOAD#); also elsewhere on the board
~PCwrite: U22.18 (G#), U23.18 (G#); also elsewhere on the board
~Reset: U22.12 (CCLR#), U23.12 (CCLR#); also elsewhere on the board
~SPcarry: U24.23 (CBI), U25.14 (CBO)
~SPhiread: U24.2 (LD); also elsewhere on the board
~SPloread: U25.2 (LD); also elsewhere on the board
~SPwrite: U24.13 (OE), U25.13 (OE); also elsewhere on the board

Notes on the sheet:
SPhi
SPlo
PChi
PClo
Address Bus
ARhi
ARlo
DRhi
DRlo
Data bus
These four registers write to the address bus. The Program Counter (PC) is a 16-bit register which can load from the address bus (jump), hold or increment. The Stack Pointer (SP) can load from the data bus, hold, increment or decrement. The AR register typically holds the address of a data item in 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

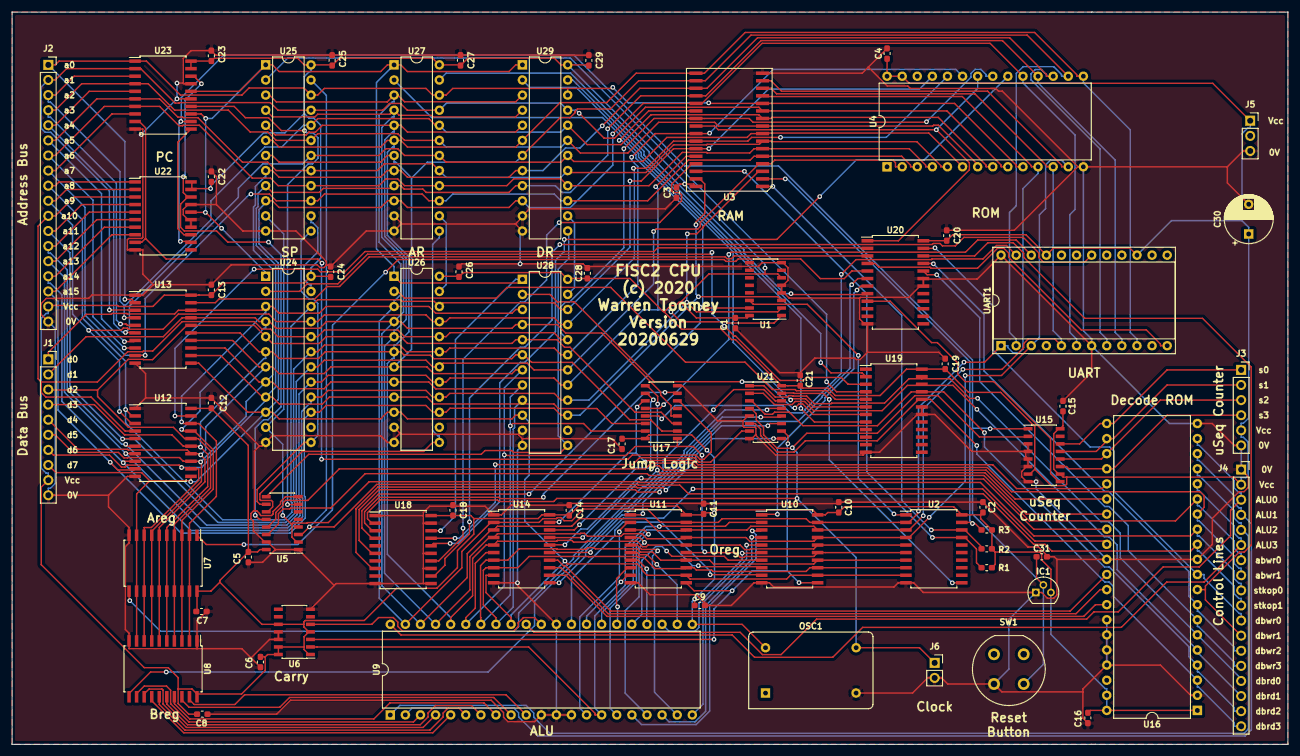
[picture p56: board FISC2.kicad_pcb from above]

Board: 2 copper layers, 214.6 x 123.2 mm, 73 parts (0 on the bottom side), 127 nets.

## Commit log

2020-06-30 Initial commit to the GitHub repository.
    [AddrRegs.sch, Control.sch, Data.sch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]
2020-07-01 I updated some Verilog propagation delays
    based on my breadboard measurements.
    [FISC2.dsn, FISC2.kicad_pcb]
2020-07-01 Updated schematic PDF, more journal entries.
2020-07-01 Taking on board feedback from Alan
2020-07-02 More journal entries: testing the 22K pullups.
    [FISC2.kicad_pcb]
2020-07-02 The PCB design is done, schematic updated, PCBs ordered.
    [FISC2.kicad_pcb, Memory.sch]
2020-07-04 Some assembler improvements: names for X, Y and SP registers.
2020-07-06 Added .text and .data pseudo-ops to the assembler.
2020-07-07 Added more instructions, assembler processes multiple files.
2020-07-08 Added numeric labels to the assembler. Renamed X, Y registers.

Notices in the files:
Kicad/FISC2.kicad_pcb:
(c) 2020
